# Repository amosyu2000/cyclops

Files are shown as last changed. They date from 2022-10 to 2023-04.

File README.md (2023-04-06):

<div align="center">

<a href="https://github.com/amosyu2000/cyclops">
	Cyclops header
</a>

# Cyclops <!-- omit in toc -->
Cyclops Ride Assist: Real-Time Monitoring System.<br/>  
__Team 9__  
[Aaron Li](https://github.com/aaronhsli) (lia79)  
[Amos Cheung](https://github.com/amoscheung99527) (cheuny2)  
[Amos Yu](https://github.com/amosyu2000) (yua25)  
[Brian Le](https://github.com/briantule) (leb7)  
[Manny Lemos](https://github.com/MannyLemos) (lemosm1)  

</div>

 <!-- Page Break -->

North American cities are shifting from a car-centric design to greener forms of transportation. It is expected that more people will adopt cycling as their primary method of commuting. However, it is difficult for a cyclist to keep track of everything going on around them, especially during busy times.

Cyclops Ride Assist (CRA) will be a user-friendly, all-in-one, and easily mountable system that adds modern automobile safety features on any bicycle that will allow its users to have full detection of their surroundings during their trip from start to finish. This includes rear view detection using LiDAR sensors and an LED display, crash identification through an accelerometer, as well as a front-facing camera to capture and record footage. In the event of an accident, the CRA will automatically record a min of footage, the LiDAR data, as well as an acclerometer log for future review and analysis. 

## Video

Click the thumbnail to be directed to our promotional video!

Watch the video (https://youtu.be/2H2faZxTyGI)

## Schedule 

| Date | Description |
|---|---|
| September 7, 2022 | Project started |
| September 21, 2022 | Problem Statement and Goals started |
| September 24, 2022 | Development Plan started |
| Oct 3, 2022 | Software Requirements Specification started |
| October 19, 2022 | Hazard Analysis started |
| October 25, 2022 | Verification and Validation Plan started |
| November 14, 2022 | Proof of Concept demo |
| January 17, 2023 | Design Document started |
| February 9, 2023 | Revision 0 demo |
| March 1, 2023 | Verification and Validation Report started |
| April 1, 2023 | Revision 1 demo |
| April 5, 2023 | User Guide started |
| April 5, 2023 | Reflection started |
| April 11, 2023 | Capstone EXPO |

## Repository Structure

### Source Code

We put all our code in the [Code tab](https://github.com/amosyu2000/cyclops). The file structure of the code is as follows.

<details><summary>docs</summary>

- Documentation for the project

</details>

<details><summary>refs</summary>

- Reference material used for the project, including papers

</details>

<details><summary>src</summary>

- Source code

</details>

<details><summary>test</summary>

- Test cases

</details>

### Issues

We report and keep track of bugs that need to be fixed and things that need to be done in the [Issues tab](https://github.com/amosyu2000/cyclops/issues). 

### Contributing

We contribute to the codebase by making pull requests, which are tracked in the [Pull requests tab](https://github.com/amosyu2000/cyclops/pulls).

### Meeting Minutes

We schedule weekly meetings to discuss progress, setbacks, and deadlines. Meeting minutes are kept in the [Discussions tab](https://github.com/amosyu2000/cyclops/discussions).

### Wiki

We write down things we've learned so that we can refer to it in the future. Documentation is kept in the [Wiki tab](https://github.com/amosyu2000/cyclops/wiki) and is updated frequently.

## License
See our [license file](./LICENSE).

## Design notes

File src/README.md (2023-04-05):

<div align="center">

# Source Code

</div>

## How to execute `__main__`
1. Add your packages to the pipenv with `pipenv install <package> --skip-lock`
1. Once added, run `pipenv run python .`

## Modules

This folder contains all source code for the project, including software for the Raspberry Pi, schematics for the electrical system, or 3D models for the mechanical housing.

### Physical Modules



### Electrical Modules



### Software Modules









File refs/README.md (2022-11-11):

<div align="center">

# Reference Information

</div>

This folder holds information and resources of interest for the project.  This
is intended to be a convenient location for project members to access
support material for the project.

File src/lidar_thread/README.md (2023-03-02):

<div align="center">

# Lidar Sensor

</div>

## Hardware
[TF-Luna (8m)](http://en.benewake.com/product/detail/5e1c1fd04d839408076b6255.html)

## Usage
In the `src` directory, run `pipenv run python -m lidar_thread.__init__`

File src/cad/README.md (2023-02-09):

<div align="center">

# CAD Files

</div>

.ipt, .stl files for use on Prusa i3 MK3S printers.

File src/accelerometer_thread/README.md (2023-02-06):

<div align="center">

# Accelerometer

</div>

## Hardware
[ADXL345](https://www.analog.com/media/en/technical-documentation/data-sheets/adxl345.pdf)

## Usage
In the `src` directory, run `pipenv run python -m accelerometer_thread.__init__`

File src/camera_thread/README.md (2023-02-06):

<div align="center">

# Camera

</div>

## Hardware
[Webcam](https://www.amazon.ca/Microphone-Otooking-Streaming-Conferencing-Recording/dp/B08HYDZ6TN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)

## Usage
In the `src` directory, run `pipenv run python -m camera_thread.__init__`

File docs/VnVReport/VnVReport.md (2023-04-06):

<div align="center">

<a href="https://github.com/amosyu2000/cyclops">
	Cyclops header
</a>

# Verification and Validation Report <!-- omit in toc -->
Cyclops Ride Assist: Real-time Monitoring System.<br/>  
__Team 9__  
Aaron Li (lia79)  
Amos Cheung (cheuny2)  
Amos Yu (yua25)  
Brian Le (leb7)  
Manny Lemos (lemosm1)  

</div>

 <!-- Page Break -->

## Table Of Contents <!-- omit in toc -->
- [1. Revision History](#1-revision-history)
- [2. Symbols, Abbreviations, and Acronyms](#2-symbols-abbreviations-and-acronyms)
- [3. General Information](#3-general-information)
	- [3.1. Purpose](#31-purpose)
	- [3.2. Scope](#32-scope)
	- [3.3. Background](#33-background)
- [4. Functional Requirements Evaluation](#4-functional-requirements-evaluation)
- [5. Non-Functional Requirements Evaluation](#5-non-functional-requirements-evaluation)
	- [5.1. Look and Feel Requirements](#51-look-and-feel-requirements)
	- [5.2. Usability and Humanity Requirements](#52-usability-and-humanity-requirements)
	- [5.3. Performance Requirements](#53-performance-requirements)
	- [5.4. Operational and Environmental Requirements](#54-operational-and-environmental-requirements)
	- [5.5. Maintainability and Support Requirements](#55-maintainability-and-support-requirements)
	- [5.6. Security Requirements](#56-security-requirements)
	- [5.7. Cultural and Political Requirements](#57-cultural-and-political-requirements)
	- [5.8. Legal Requirements](#58-legal-requirements)
- [6. Testing](#6-testing)
	- [6.1. Rear Vehicle Detection](#61-rear-vehicle-detection)
	- [6.2. Crash Detection](#62-crash-detection)
	- [6.3. Video/Data Logging](#63-videodata-logging)
	- [6.4. Power](#64-power)
	- [6.5. Mounting](#65-mounting)
- [7. Changes Due to Testing](#7-changes-due-to-testing)
- [8. Code Coverage Metrics](#8-code-coverage-metrics)
- [9. Appendix](#9-appendix)
	- [9.1. Reflection](#91-reflection)
	- [9.2. Usability Survery Responses](#92-usability-survery-responses)

## List of Tables <!-- omit in toc -->
- [Table 1.1: Revision History](#rh)
- [Table 1.2: Rear Vehicle Detection Tests](#t1.2)
- [Table 1.3: Crash Detection Tests](#t1.3)
- [Table 1.4: Video/Data Logging Tests](#t1.4)
- [Table 1.5: Power Tests](#t1.5)
- [Table 1.6: Mounting Tests](#t1.6)
- [Table 1.7: Code Coverage Metrics](#t1.7)

## List of Figures <!-- omit in toc -->

## 1. Revision History
<div align="center">

<p id="rh">Table 1.1: Revision History</p>

| Date | Developer(s) | Change |
|:--|:--|:--|
| March 1, 2023 | Aaron Li, Amos Cheung, Amos Yu, Brian Le, Manny Lemos | Document created |
| March 6, 2023 | Brian Le | Updated sections | 
| March 6, 2023 | Amos Cheung | Updated sections | 
| March 7, 2023 | Aaron Li | Updated sections |
| April 3, 2023 | Amos Cheung | Changed name/description of some of the sections. Refer to issue #322 for details | 
| April 5, 2023 | Aaron Li | Link sections. | 

</div>

## 2. Symbols, Abbreviations, and Acronyms
| Name | Description |
|:--|:--|
| CRA | Abbreviation of Cyclops Ride Assist.|
| Cyclist | A person who operates a bicycle as a means of transportation. |
| User | A person who will operate the final product. See Cyclist. |
| Client | See user. |
| SRS | Software Requirements Specification |
| Video feed | A cycle of clips using a fifo queue implementation. Can be concatenated to form the last buffer_time seconds of video.  |
| LiDAR | Light Detection and Ranging. A range sensing method that uses a pulsed laser. |
| LED stick | An array of 8 individually addressable RGB LEDs. |
| α_x | Measures acceleration parallel to the path of the bicycle. |
| α_y | Measures acceleration perpendicular to the path of the bicycle along the plane of the ground. |
| α_z | Measures acceleration in the vertical direction. |
| norm | A measure of the absolute value of the acceleration vector. |
| tilt | A measure of acceleration vector in the xy plane. |
| f_sampling_cd | Sampling frequency of the crash detection. |
| f_sampling_bd | Sampling frequency of the rear vehicle detection. |
| buffer_time | Seconds of video to save after a crash occurs. |

## 3. General Information

### 3.1. Purpose
The purpose of this document is to outline the steps taken for validation, verification, and testing of the functionality of Cyclops Ride Assist (CRA).

### 3.2. Scope
This document details the testing procedures and pass-fail requirements that ensure each sub-system in CRA functions independently and as a complete and fully integrated product. Software and hardware components alike will both be subject to Black box testing.

### 3.3. Background
CRA will be an easily mountable, and quick to set up system that adds modern car safety features onto any bike. These features include rear vehicle detection and alert, a continuous loop of the last 60 seconds of camera, accelerometer, and LiDAR data, and crash identification and response. CRA is aimed at cyclists of all levels that frequently traverse road and gravel terrains. CRA is not designed to be used on extreme terrain such as downhill mountain biking.

## 4. Functional Requirements Evaluation
The testing of the functional requirements is important to ensure that the system, and the many components that it is composed of, functions as designed. The methodology for the functional requirements is to begin with unit testing of the individual components, then move to integration testing.

| Traceability | Relevant Components | Test Plan and Test Factors |
|:--|:--|:--|
| CFR1 | Rear Vehicle Detection | The tests that focus on this requirement demonstrated that the system is able to accurately convert a distance signal input into an LED output. For the testing of this requirement to pass, it was critical that both the LiDAR and the LEDs are functioning properly independently of each other. When testing the LiDAR, it was important to consider the length of the cable that connects the LiDAR to the microcontroller. Having such a long cable can cause inaccuracies in signal transmission. Testing the LiDAR also involved making sure that the sensor could return accurate distance measurements over the full range of operation of the device. The LEDs also needed to be tested to make sure that each individual LED on the LED stick could be toggled on or off, and the color modified as desired. To test the integration of the full rear vehicle detection system, it was important to test that the rate at which the LEDs turn on was proportional to the rate at which an object was being closer in the LiDAR's range of operation. Testing involved both using code to test as well as field testing, to ensure that this functional requirement worked accurately and continuously from the input to the output.|
| CFR2 | Video/Data Logging | The test plan for video recording demonstrated that the system can collect uninterrupted video footage. This sort of testing focuses on the camera equipment itself as well as the code that uses it. Factors to consider included making sure that the camera was mounted securely to the housing, and verifying that the soldering of the camera cable has good contact and no shorting. When testing the software for the video logging, the camera was connected to a laptop and it was demonstrated that it worked as intended. This same test was then transferred to the microcontroller to make sure that it could provide the same performance on the embedded system.|
| CFR3 | Crash Detection | A factor that was kept in mind when testing the accuracy of the acceleration data returned by the accelerometer was that the data returned was not in m/s^2. Thus, it was also necessary to test the function used to scale the data coming in to be in SI units. Knowing also that the accelerometer is three-axis, it was necessary to test all three axes independently to measure any cross-sensitivity that might be present. It was also important to test the frequency at which the crash detection polls data. Testing revealed an optimal f_sample_cd sampling frequency that was a balance between resource usage and data reliability. Testing involved both using code to test as well as field testing. Field testing looked like subjecting the accelerometer to various impacts in different directions, and also running tests to ensure that, when a user is cycling under normal conditions, the jitter of the acceleration data that is being measured is kept below a threshold. |
| CFR5 | Crash Detection | The tests that focus on this requirement were designed to demonstrate that the crash detection component is able to differentiate between a user that is cycling versus a user that is still. Testing revealed that the system is not capable of achieving this, as there were too many factors at play. For example, in order for the acceleration data of an idle bike versus a moving bike to be differentiable, it had to be assumed that the bike was on its kickstand in order to remove the factor of any movement that the user might introduce. Although this test did not pass, it was shown that the functionality of the crash detection in | CFR7 was not  |affected, as the crash detection algorithm did not depend on the ability to discern if a user is moving. This test revealed that the accelerometer is always detecting that the user is moving, and so the crash detection algorithm was designed to work around this problem. 
| CFR6 | Rear Vehicle Detection | When testing the LiDAR sensor, a factor that was considered was the type of material of the surface that the signal would reflect off of. The exterior of vehicles is usually made of a smooth metal with a coating to finish, which was shown to reflect the LiDAR signal reliably. Although vehicles were the primary target for the rear vehicle detection, testing factored in other common surfaces that might be seen by cyclists on the road, such as concrete, wood, and plastic, as well as objects with bizarre shapes, such as other bicycles. It was also important to test the frequency at which the rear vehicle detection polls distance data. Testing revealed an optimal f_sample_bd sampling frequency that was a balance between resource usage and data reliability. Unit testing for the software portion of this functional requirement involved feeding mock data to the rear vehicle detection function, then verifying that the algorithm could recognize that an object was approaching (i.e. the distance was steadily decreasing). 
| CFR7 | Crash Detection | Testing the crash detection algorithm involved verifying the functionality of each of the three stages of the algorithm, then making sure that the algorithm was able to transition from one stage to the next in response to the acceleration data coming in. The three stages are called the Normal, Climax, and Inverse states, and to enter each stage, the acceleration data needed to exhibit certain behavior. If the algorithm got to the Inverse state, it was determined that a crash had occurred. When testing the robustness of the algorithm, atypical crash datasets were provided to see if a crash would be detected. By this approach, the algorithm could be continuously improved and refined until all the datasets would be detected. The same testing process was carried out for false positives. Testing involved using software testing suites as well as field testing, to ensure that the algorithm could match performance in a real-time environment.|
| CFR8 | Crash Detection, Video/Data Logging | The testing done for this requirement focused on the length of the video exported by the system. Other factors to consider included the memory and CPU usage that the buffer process consumed on the microcontroller. A software testing suite was used to verify that the buffer process was safely creating and dumping video fragments, and could stitch those fragments together into a full video of maximum length buffer_time upon request. The suite also tested the length of video outputs that are requested one right after another. On top of using the suite, manual testing revealed the importance of maintaining a steady, expected framerate. This was found to be important because it was necessary to ensure a video that was not sped-up or slowed-down, and would also not sporadically speed up and slow down. |
| CFR9 | Video/Data Logging | It was important to test the functional requirement of CRA to be able to save the video footage to disk in order to define how the microcontroller behaves when the external storage is either not plugged in or out of memory. The idea is to validate that the user experience is not affected when the external storage component is found to be in an invalid state. A factor to consider was the fact that a user could choose to plug in their own external storage instead of using the one provided. Another factor was the fact that a user might be using the external storage for other things as well, and thus the CRA should not interfere with other files on it. Field testing looked like leaving the external storage unplugged or plugging in several different external storages at different storage capacities.|
| CFR11 | Power | The objective behind testing the power component was to make sure that the battery is able to sustain the microcontroller under normal operating conditions, and to define the behavior of CRA in the cases when the power supplied by the battery is insufficient. A part of the testing plan involved measuring the battery life of the system from a full charge, when it is turned on, and when it is turned off. This testing revealed ways that the microcontroller process could be optimized to consume less power, and gave the product a specification of battery life that can be provided to the user. Furthermore, the testing plan needed to decide at what point the user needs to be reminded of low battery, and at what point the battery can no longer sufficiently power CRA. |
| CFR12 | Video/Data Logging | The testing done for this requirement focused on the continuous, uninterrupted execution of the video buffer process while another a previous video was being logged. For the testing of this requirement to pass, it was required that there be a negligible, ideally zero, amount of lag occur when a video logging action is called. This testing was first done manually in the lab, performed over SSH or with the CRA plugged into an external monitor. Then, the testing was transitioned to the field, where the system was subjected to normal operating conditions. In the case of the field, the process could not be monitored in real time, so the test was verified by looking for any time discrepancies in the generated logs. |
| CFR13 | Crash Detection | The testing done for this requirement focused on the continuous, uninterrupted execution of the crash detection process while another crash was being logged. For the testing of this requirement to pass, it was required that there be a negligible, ideally zero, amount of lag occurring when the crash detection algorithm would detect a crash. This testing was first done manually in the lab, performed over SSH or with the CRA plugged into an external monitor. Then, the testing was transitioned to the field, where the system was subjected to normal operating conditions. In the case of the field, the process could not be monitored in real time, so the test was verified by looking for any time discrepancies in the generated logs. |

## 5. Non-Functional Requirements Evaluation
The testing of the non-functional required both qualitative and quantitive tests. [Usability surveys](#92-usability-survery-responses), rankings, and timing tests were all used in conjunction with one another to determine if all the requirements had been satisfied. In order to ensure that the CRA is of the highest standards, the team ensured that all testing was done in a robust and repeatable way. All test specifications and structure can be found in the VnVPlan. 

### 5.1. Look and Feel Requirements
|Requirement Traceability | Test Plan and Test Factors| Results and Evaluation | 
|:--|:--|:--|
|CNFR1, CNFR2, CNFR3, CNFR4, CNFRST1| The main goal of testing the Look and Feel Requirements is to ensure that the CRA is well adapted to a certain style and appearance that was outlined in the SRS document. Due to certain factors such as societal or personal factors, it was key to ensure that the look and feel of the CRA would not become a hindrance to its users. The test plan was to first conduct a visual inspection test and to create several usability surveys - which can be viewed in [Section 9.2](#92-usability-survery-responses) - for all patrons to fill out in order to determine whether or not the product was satisfactory according to the noted requirements.| Usability tests were completed by different users and the overall score was averaged out to be an 8.5. Positive feedback came from the minimalistic design, colour choice, and size. However, there was criticism in terms of the overall rectangular appearance and choice of material. |

### 5.2. Usability and Humanity Requirements
|Requirement Traceability | Test Plan and Test Factors| Results and Evaluation | 
|:--|:--|:--|
|CNFR5 - CNFR14, CNFRST2 - CNFRST6| The main goal of testing the Usability and Humanity Requirements is to ensure that the CRA can be used by a variety of users and stakeholders with ease as was outlined in the SRS document. Since the system may be considered complicated to non-technical or technical users, it was imperative to make sure that the product was as simple as possible. Therefore, two categories were to be tested: hardware and software.| Overall, four different tests were completed to ensure that the Usability and Humanity Requirements were fulfilled. For further details and implications of the test, the VnV Plan can be referenced. For CNFRST2, the average time was measured to be around 16.3s. Positive feedback was given for the design of the locking mechanism while negative feedback was given for the weight. For CNFRST3, the average time it took to open the application after a power cycle was approximately 30.7s. This was not satisfactory to the developers as it was above the threshold set (RESPONSE_TIME_MILLISECONDS) given and so further implementation and testing will be done to ensure a shorter time. For CNFRST4 and CNFRST5, the manual was spoken instead to different users using non-technical language. The overall score was 8.1 out of a possible 10. Feedback included further instructions and explanations of the system. These tests were combined for simpler testing. For CNFRST6, the audiovisual cue was output almost immediately which was <1 second. This is within the response time desired.| 

### 5.3. Performance Requirements
|Requirement Traceability | Test Plan and Test Factors| Results and Evaluation | 
|:--|:--|:--|
|CNFR15 - CNFR33, CNFRST7 - CNFRST21 | The main goal of testing the performance requirements is to ensure that the CRA is performing up to expected standards. The testing plan included all the different modules of the system. This would include the hardware (The chassis, the camera, the microcontroller, the storage, etc.) as well as the software (Algorithms, crash detection, LiDAR, video logging, etc). These tests also ran simultaneously with various CFRST tests.| Please refer to the Functional Requirements Evaluation in [Section 4](#4-functional-requirements-evaluation) or the Testing listed below in [Section 6](#6-testing) for further details on the testing plan for performance. Furthermore, the details of each test can be found in the VnVPlan document. For CNFRST7, the average of the recorded tests was 30.7s. This was the same test as CFNRST3. For CNFRST8, the average of the recorded tests was 16.5s. This is within our allowable range as prescribed through UPLOAD_TIME_SECONDS. For CNFRST9, the average of the recorded tests was <1s. This is within our allowable range. For CNFRST10,  the average of the recorded tests was 84%. This is within our allowable range but can be improved on to ensure better vehicle detection. For CNFRST11, the developers tested on their own personal bicycles with no hindrance. Furthermore, after conversing with users, it was deemed that there was no hindrance to the pedaling, braking, or other normal functions on their bicycle. For CNFRST12, there was no leaking or sounds to be heard. Over the course of twenty trials, there was no indication of any failure or degradation. For CNFRST13, through our software unit testing, it was deemed that all calculations were within the three decimal range provided. For CNFRST14, through our software unit testing, it was deemed the speedometer and accelerometer were running accurately within 2%. For CNFRST15, the average of the recorded tests was within 1s. This is within our allowable range. For CNFRST16, the average of the recorded tests was 10.3s. This is within our allowable range. For CNFRST17, a drop test and crash test was performed twenty different times. After further inspection, it was deemed that there was no damage to the CRA. For CNFRST18, the average of the recorded tests was 5.1s. This is within our allowable range. For CNFRST19, the system was left on for various periods of time while running solely on battery. At the end of the tests, it was found that the battery could last for approximately 30 minutes before depleting. This result was not satisfactory and will require further research. For CNFRST20, a survey was collected with feedback and can be viewed in [Section 9.2](#92-usability-survery-responses). Many responses did not have any concerns with the CRA; however, some wanted further extensibility in terms of ports, cameras, battery. For CNFRST21, the test was intended to be continuous. Upon writing this document, there has been no documentation of any damage or wear to the product. | 

### 5.4. Operational and Environmental Requirements
|Requirement Traceability | Test Plan and Test Factors| Results and Evaluation | 
|:--|:--|:--|
|CNFR34 - CNFR38, CNFRST22 - CNFRST24 | The main goal of testing the operational and environmental requirements is to ensure that the CRA would be able to operate in various conditions and situations. The testing plan included placing the CRA in various locations with different climates, placing the CRA in different positions, as well as interfacing the CRA with different OS and hardware. | For CNFRST22, the CRA was brought outside and all intended functionalities were working as expected. For CNFRST23, the CRA was connected to a variety of systems and computers  and all intended functionalities were working as expected. For CNFRST24, the repository was able to be accessed publicly by the developers as well as other users and stakeholders through a link. | 

### 5.5. Maintainability and Support Requirements
|Requirement Traceability | Test Plan and Test Factors| Results and Evaluation | 
|:--|:--|:--|
|CNFR39 - CNFR42, CNFRST25 | The main goal of testing the maintainability and support requirements is to ensure that the CRA will be widely available and accessible to all. The testing plan included ensuring that the code repository was fully public and able to be accessed by any on various sorts of computers and systems. | For CNFRST25, different errors like unplugging, missing hardware, and recreated bugs were created and the system did not work as intended. Furthermore, the system would alert the user that it was not working as intended. | 

### 5.6. Security Requirements
|Requirement Traceability | Test Plan and Test Factors| Results and Evaluation | 
|:--|:--|:--|
|CNFR43, CNFR44, CNFR45, CNFRST26, CNFRST27|The main goal of testing the security requirements is to ensure that the CRA. The testing plan included two plans that would test the access and the privacy to the loaded storage. It was ensured that the footage created would not be uploaded to any unwanted platforms or the cloud. | For CNFRST26, the SD card was placed into various systems and computers and all files were readable. A conversion was done between the Pi video file and an .mp4. For CNFRST27, no videos were sent to the cloud through the wireless connection provided to the CRA. All files were found to be local. | 

### 5.7. Cultural and Political Requirements
|Requirement Traceability | Test Plan and Test Factors| Results and Evaluation | 
|:--|:--|:--|
|CNFR46, CNFR47, CNFRST28 | The main goal of testing the cultural and political requirements is to ensure that the CRA will not offend stakeholders, users, or others. This testing plan was included to ensure that the product would not infringe on Equity, Diversion, and Inclusion of any users. The tests included a [usability survey](#92-usability-survery-responses) given to users to gain their feedback. | For CNFRST28, the manual was indeed in English.  | 
### 5.8. Legal Requirements
|Requirement Traceability | Test Plan and Test Factors| Results and Evaluation | 
|:--|:--|:--|
|CNFR48, CNFR49, CNFRST29, CNFRST30 |The main goal of testing the legal requirements is to ensure that the CRA is compliant and is not breaking any laws in various countries, mainly Canada. The testing plan included group meetings and further research that would be compiled into a document. | For CNFRST29, various bicycle brands were researched and tested. Furthermore, many users possess bicycles and so testing was also done on a multitude of these vehicles. For CNFRST30, the CRA did not infringe on any of the legal or compliance requirements in Canada. Therefore, it was noted that the product would be allowed. | 

## 6. Testing
Testing was structured based on how the systems and subsystems were defined for the software of Cyclops. With the nature of how each major safety feature is composed of both electrical and software components, either white box or black box testing was utilized. If the unit required a real-world environment to fully work, black box testing was chosen and if the unit involved more algorithmic components, white box testing was chosen.

### 6.1. Rear Vehicle Detection
The main goal of testing the rear vehicle detection would be to test the functionality of our LiDAR sensor as well as the algorithm used to convert the distance-based data into a visual representation (LED)’s. The visual representation of LEDs is configured such that each LED will represent a specific level/proximity to the rider of a vehicle or object. Our plan in unit testing would be to ensure that the LEDs are functioning from each extremity (close and far) ensuring that there is a visible object in the sensor's field of vision at all times. 

<div align="center">

<p id="t1.2">Table 1.2: Rear Vehicle Detection Tests</p>

| Test Number | Description | Requirement Referenced | Inputs | Expected Outputs | Actual Outputs | Result |
|:--|:--|:--|:--|:--|:--|:--|
| BD1 | Object should be held 0 - 1 meters to the rear sensor | CFR1, CFR2, CFR6, CFR10, CFR12, CNFR12, CNFR25 | LiDAR sensor feed | LED stick cells 1 - 7 should all be lit up | LED stick cells1 - 7 were all lit up | Pass |
| BD2 | Object will be 4 meters from the rear sensor | CFR1, CFR2, CFR6, CFR10, CFR12, CNFR12, CNFR25 | LiDAR sensor feed | LED stick cells 1 - 4 should all be lit up | LED stick cells 1 - 6 were all lit up | Pass |
| BD3 | Object will be greater than 8 meters from the rear sensor | CFR1, CFR2, CFR6, CFR10, CFR12, CNFR12, CNFR25 | LiDAR sensor feed | LED stick cells should all be off | LED stick cells were all off | Pass |
| BD4 | Rear Vehicle detection should have < 1 second in latency for updating the LEDS. We will hide an object away from the Ultrasonic sensors field of vision and then suddenly hold it in the view to see its reaction time | CFR1, CFR2, CFR6, CFR10, CFR12, CNFR15 | LiDAR sensor feed | LED stick cells should light up within 1 second once an object is put in the sensors field of vision | LED stick cells light up within 1 second once the object is put in the sensors field of vision | Pass |
</div>

### 6.2. Crash Detection 

The crash detection unit of CRA consists of 2 main components which are the accelerometer inputs and the algorithm to determine a crash. The algorithm is implemented through trial and error to approximate a valid threshold of disturbance towards the unit for the program to have recognized a crash. The test plan is to create a real world environment where the rider and bike will go through common obstacles and routines that are similar to that of the field. Varying obstacles shall be used to create a variety of test cases to test the system boundaries. The accelerometer is the main electrical component in this subsystem so we will also add test suites to ensure that reads are properly made and logged. Simulated tests will be done in a safe and risk free manner in which we are generating enough force for CRA to recognize a crash. 

Each test performed for the crash detection unit will have CRA 2 main units already mounted on the bike handle and rear seat respectively.

<div align="center">

<p id="t1.3">Table 1.3: Crash Detection Tests</p>

| Test Number | Description | Requirement Referenced | Inputs | Expected Outputs | Actual Outputs | Result |
|:--|:--|:--|:--|:--|:--|:--|
| CD1 | Rider will ride in a straight line on a flat road for 10 seconds | CFR3, CFR4, CFR5, CFR7 | Accelerometer electrical input, front camera feed | No crashed detected | No crashed detected | Pass |
| CD2 | Rider will ride in a straight line over grass or a bumpy path for 10 seconds | CFR3, CFR4, CFR5, CFR7 | Accelerometer electrical input, front camera feed | No crashed detected | No crashed detected | Pass |
| CD3 | Rider will ride in a straight line for 5 seconds and then “crash” | CFR3, CFR4, CFR5, CFR7 | Accelerometer electrical input, front camera feed | Crash detection algorithm should prompt a video clip to be logged | Video clip was logged and stored on SD as well as crash information of moments before | Pass |
| CD4 | Rider will hold the bike in their hand and let the bike drop/fall over | CFR3, CFR4, CFR5, CFR7 | Accelerometer electrical input, front camera feed | No crashed detected | No crashed detected | Pass |
| CD5 | Rider will hold the bike and jolt it forward and backwards for 5 seconds | CFR3, CFR4, CFR5, CFR7 | Accelerometer electrical input | α_x readings should update to reflect the sudden change in acceleration | α_x readings updates to reflect the sudden change in acceleration | Pass |
| CD6 | Rider will hold the bike and jolt it side to side (left to right) for 5 seconds | CFR3, CFR4, CFR5, CFR7 | Accelerometer electrical input | α_y readings should update to reflect the sudden change in acceleration | α_y readings updates to reflect the sudden change in acceleration | Pass |
| CD7 | Rider will hold the bike and jolt it up and down for 5 seconds | CFR3, CFR4, CFR5, CFR7 | Accelerometer electrical input | α_z readings should update to reflect the sudden change in acceleration | α_z readings updates to reflect the sudden change in acceleration | Pass |
| CD8 | Create another crash after recovering from the prior crash.| CFR12, CFR13 | Accelerometer electrical input | CRA should resume crash detection and recording video and data | CRA resumes crash detection and recording video and data | Pass |
</div>

### 6.3. Video/Data Logging

The video and data logging unit testing will ensure the functionality of the logging remains active during the time the system is running, saves logged values upon crash, and resumes its logging after the crash. Logged clips and values should remain consistent and have little to no latency. The test suite for this unit will also account for the accuracy and rate in which data has been logged when the unit itself experiences varying changes in movement. 

Each test will be performed by having the CRA unit experience and trigger a crash.

<div align="center">

<p id="t1.4">Table 1.4: Video/Data Logging Tests</p>

| Test Number | Description | Requirement Referenced | Inputs | Expected Outputs | Actual Outputs | Result |
|:--|:--|:--|:--|:--|:--|:--|
| VDL1 | Take note of event that happened in the field of view of vfront 60 seconds prior to crash | CFR2, CFR7, CFR8 | Vfront input | The events of the video clip should be exactly the same as what was viewed 60 seconds prior | The events of the video clip are the exact same as what was viewed 60 seconds prior | Pass |
| VDL2 | Prior to the crash, jolt CRA forward and backwards to log and verify the changes in α_x have been logged | CFR3 | Vfront input, Accelerometer electrical input, front camera feed | The past 60 seconds of events for α_x should be logged and stored within the CSV data log | The past 60 seconds of events for α_x are logged and stored within the CSV data log | Pass |
| VDL3 | Prior to the crash, jolt CRA forward and backwards to log and verify the changes in α_x have been logged | CFR3 | Vfront input, Accelerometer electrical input, front camera feed | The past 60 seconds of events for α_y should be logged and stored within the CSV data log | The past 60 seconds of events for α_y are logged and stored within the CSV data log | Pass | 
| VDL4 | Prior to the crash, jolt CRA forward and backwards to log and verify the changes in α_x have been logged | CFR3 | Vfront input, Accelerometer electrical input, front camera feed | The past 60 seconds of events for α_z should be logged and stored within the CSV data log | The past 60 seconds of events for α_z are logged and stored within the CSV data log | Pass |
| VDL5 | When CRA is powered on, video and data logs should be stored on a new file | CFR7, CFR8 | Power button, Vfront input, Accelerometer electrical input, front camera feed | The next crash is detected and should be logged, verify that the file is a fresh file from the previous crash log | A crash was detected and the file is a fresh file from the previous crash log | Pass |
| VDL6 | When CRA detects a crash, the next crash after should have video and data logs stored on a new file | CFR7, CFR8, CNFR29 | Power button, Vfront input, Accelerometer electrical input, front camera feed | The next crash is detected and should be logged, verify that the file is a fresh file from the previous crash log | A crash was detected and the file is a fresh file from the previous crash log | Pass |
| VDL7 | CRA video and data logs should be responsive and have latency of < 1 second. We will display the constant data outputs being read in by CRA and note if the values are changing within a reasonable time | CNFR15, CNFR17 | Vfront input, Accelerometer electrical input, front camera feed | The values of the acceleration should update and reflect a drop within 1 second of use dropping the unit | The values update within 1.5 second of dropping the unit | Fail |

</div>

### 6.4. Power

CRA has configured the power button such that both the crash detection and rear vehicle detection should automatically start running once it has been pressed. The system also has configured the button to log the last bit of data once the power has been turned off (button is pressed again). 

<div align="center">

<p id="t1.5">Table 1.5: Power Tests</p>

| Test Number | Description | Requirement Referenced | Inputs | Expected Outputs | Actual Outputs | Result |
|:--|:--|:--|:--|:--|:--|:--|
| P1 | CRA should automatically have the scripts of CRA’s crash and rear vehicle detection ran once powered on | CFR11, CNFR6 | Power button | Video and data should begin to be read in and LEDs should light up to indicate power on | Video and data begins to be read in and LEDs light up when powered on | Pass |
| P2 | CRA should automatically clip and log the past 60 seconds of CRA’s crash and rear vehicle detection data once powered off | CFR11, CNFR6 | Power button | Data should be logged and saved within CSV locally when CRA has been powered off | Data is logged and saved within CSV locally when CRA was powered off | Pass | 

</div>

### 6.5. Mounting

The physical system of the CRA consists of two separate housing units that each attach to different parts of the bike. The main housing unit mounts to the handlebars, while the LiDAR housing unit mounts to the seat post. Both units use the same mounting hardware. Testing will ensure that each mounting system can reliably secure the CRA to the bicycle in a variety of situations.

<div align="center">

<p id="t1.6">Table 1.6: Mounting Tests</p>

| Test Number | Description | Requirement Referenced | Inputs | Expected Outputs | Actual Outputs | Result |
|:--|:--|:--|:--|:--|:--|:--|
| M1 | The main housing is resistant to shaking when mounted to the handlebars of the bicycle | CNFR5, CNFR21 | High-frequency, low-amplitude shaking over an extended time period | The housing stays in place | The housing stays in place | Pass |
| M2 | The main housing is resistant to impact when mounted to the handlebars of the bicycle | CNFR5, CNFR21 | A single, high-amplitude impact | The housing stays in place | The housing stays in place | Pass |
| M3 | Securely mount the main housing the handlebars of the bicycle | CNFR13, CNFR21 | Several bike handlebars of different diameters | The housing mounts securely | The housing mounts securely | Pass |
| M4 | The LiDAR housing is resistant to shaking when mounted to the seat post | CNFR5, CNFR21 | High-frequency, low-amplitude shaking over an extended time period | The housing stays in place | The housing stays in place | Pass |
| M5 | The LiDAR housing is resistant to impact when mounted to the seat post | CNFR5, CNFR21 | A single, high-amplitude shock | The housing stays in place | The housing stays in place | Pass | 
| M6 | Securely mount the LiDAR to the seat post | CNFR13, CNFR21 | Several seat posts of different tube diameters | The housing mounts securely | The housing mounts securely | Pass |

</div>

## 7. Changes Due to Testing
The Rev0 demo provided the cyclops team with an opportunity to showcase a functional prototype of the ride monitoring system. However, the presentation's weak points paired with feedback from the Teaching Assistants provided valuable insight that has shaped our final product. 

The most glaring failure of the demo was the poor performance of the ultrasonic sensor. The signal noise from operating in an enclosed space meant that the distance being detected was marginally accurate at best, and catastrophically dangerous to users at worst. Immediately following the demo more reliable alternatives were researched. It was determined that the technology at the forefront of the automotive industry, LiDAR distance sensing, was the only suitable option. In the following weeks, the switchover to LiDAR was implemented in code, wiring schematics, and mounting. The change proved fruitful, the outputs were significantly more accurate and less susceptible to noise.  Moreover, the upper limit of distance sensing was drastically increased from 2 metres to 8 metres providing a much larger window to warn users of incoming vehicles. 

Another problem identified by the Teaching assistants was our hardware housing’s striking resemblance to the humble construction block commonly known as a brick. This issue was multifold; the design was not only sharp and unattractive but also too large. This problem was considered at length following the presentation and led the Cyclops team to take on a complete redesign of the internal circuitry and hardware layout. This effort yielded a hardware housing with an approximate 50 percent reduction in volume and a less boxy design which favoured rounded corners. 

While digging into technical specifications and the real-world usage of the ride-assist system, the Teaching Assistants identified battery life as a potential source of trouble. At that time, the unit could run for approximately 30 minutes on a 10,000 mAh battery. Thanks to this insight the Cyclops team made it a priority to begin researching battery-saving methods which could be applied to the raspberry pi development board used. While still an ongoing effort, this issue has begun to be addressed. With all things considered, the largest contributor to poor battery life is the overhead associated with running unneeded functions of the operating system. Namely; the ethernet and power LEDs were disabled, wifi and Bluetooth were disabled, and HDMI output was disabled. Moreover, the LEDs used were exchanged for a more power-efficient led strip. Reaching beyond the raspberry pi, the problem was also addressed at its root - the battery. The size of the battery has been increased. The summation of these changes aims to see battery life improved to a minimum of 2 hours.

## 8. Code Coverage Metrics
Code coverage is determined by whether a specific sub system and code was exercised or not during the execution of our test suite. For the code coverage, although there exists a lot of unit testing extensions that measure out these metrics for us, it is more accurate and effective for us to calculate these metrics ourselves due to the nature that the majority of our testing is done in a real world environment and limited use of PyTest. Coverage was collected my monitoring each segment of the system while running through all of the mentioned unit tests. We monitor and have set breakpoints for functions, statements, and conditions ensuring they run through during utilization of that specific sub system. It is also noted that we will not be running unit testing for each of the respective constructor (init.py) files for each of the subsystems. Metrics that we are including in our coverage report includes:
- Function coverage: How many functions defined have been called
- Statement coverage: How many of the statements in the in the program have been executed
- Condition coverage: How many of the boolean sub-expressions have been testing for a true and a false value
- Line coverage: How many lines of source code have been tested

<div align="center">

<p id="t1.7">Table 1.7: Code Coverage Metrics</p>

| File | Statements | | Condition | | Functions | | Lines | | 
|:--|:--|:--|:--|:--|:--|:--|:--|:--|
| acceleration_plot.py | 100% | 38/38 | 100% | 1/1 | 100% | 4/4 | 100% | 79/79 |
| acceleration.py | 100% | 35/35 | N/A | N/A | 100% | 9/9 | 100% | 91/91 |
| video_capture.py | 93% | 65/70 | 80% | 8/10 | 100% | 4/4 | 100% | 159/159 |
| led.py | 100% | 14/14 | 100% | 2/2 | 100% | 3/3 | 100% | 36/36 |
| ultrasonic.py | 100% | 30/30 | 100% | 3/3 | 100% | 5/5 | 100% | 82/82 |

</div>

## 9. Appendix

### 9.1. Reflection
The VnV Plan put about a solid foundation upon which the Cyclops team worked to verify and validate the numerous intricate components of the ride assist system. The testing identified in the VnV Plan was a response to the fundamental features required by the implementation chosen. Those features are rear vehicle detection, crash detection, video and data logging, and some baseline usability and stylistic requirements. 

As a result of tackling broader requirements in testing specifications as opposed to generating specific tests for specific implementations, the VnV Plan proved to be a robust document that withstood the changes made due to testing. Some of those changes include switching from ultrasonic to LiDAR distance sensing and decreasing the size of the system. In the first instance clearly predicting what was required was driven by the overarching concept of the system; improving user safety by indicating the distance of objects behind the rider. This brings about an important concept that the Cyclops team learned and will be sure to use in future Verification and Validation Planning; Test cases should be broad enough that implementation shifts will not render them obsolete, yet specific enough that every requirement is sure to be met under their cumulative rule. 

Another vital component of specifying testing requirements is the idea of a feasible workload. This concept was considered carefully in the construction of the VnV plan and remains a cornerstone of our testing specifications. Striking a balance between a robust set of tests that fulfill all of our system's requirements while remaining feasible for the members to perform is a tricky task that must be navigated with care. Over the course of the VnV plan and subsequent testing specifications, the Cyclops team formed smaller subgroups to form testing teams. These testing teams worked together to share the load of testing, hold each other accountable to schedules, and vouch for one another when workloads were too high. To maximize efficiency the Cyclops team learned that tests should be designed to maximize their coverage and overlap as minimally as possible with other tests. 

Selecting the right tests to prove the required characteristics is yet another vital component of testing design. The Cyclops team came to understand that having the ability to take a step back from the specific test being designed and consider how the project will operate as a whole was the key to this undertaking. To succeed the team must be on the same page when it comes to overarching goals that must be fulfilled and how the product will be used. For example, when designing testing for the hardware housing it is extremely important not to treat the housing as simply a piece of plastic operating in a vacuum. Testing designers must consider the hardware housing operating in the context of the project riding atop the handlebars of a typical bicycle, outside in the elements, moving at speed, and experiencing bumps and jolts. These considerations are what make or break a testing case and demonstrate project vision.

### 9.2. Usability Survery Responses
| Timestamp | CNFRST1: Is the CRA designed in a way that is appealing? | CNFRST1: Is the CRA designed in a way that is non-intrusive? | CNFRST1: What would you add to the CRA if you were the designer? | CNFRST3: Is the CRA software designed in a way that is appealing?|CNFRST3: Was the Power ON system button easy to use? | CNFRST11: Does the CRA hinder your ability to ride your bicycle? If so, in what way? | CNFRST21: Is there any way that you would like to expand the CRA? | CNFRST21: Do you have any concerns with the CRA on your own personal bicycle? | CNFRST29: What is your brand and model of bicycle and if you know, what are the size and weight restrictions? | CNFRST46, 47: Is the CRA and all of the documents inclusive, neutral and not offensive to any stakeholders, users, or others. |
|:--|:--|:--|:--|:--|:--|:--|:--|:--|:--|:--|
| 3-3-2023 14:15:18 | Yes | Yes | nothing | Yes | Yes | no | No | No | don't know my bike model | Yes |
| 3-3-2023 14:17:13 | Yes | Yes | Nothing, its perfect | Yes | Yes | No it does not. | No | Yes | CCM 26inch tires. | Yes |
| 3-4-2023 10:35:49 | Yes | Yes | Other color options | Yes | Yes | No it doesn't. | Yes | No | Triumph Lazer | Yes |
| 3-5-2023 12:22:53| Yes | Yes | Increase camera resolution | Yes | Yes | No | No | No | Super cycle Walmart edition. Max height 6ft3. Max weight 300lbs. | Yes |
| 3-5-2023 16:31:17 | Yes | No | I would add a panel of LED lights to add to the aesthetic of the machine. | Yes | Yes | It blocks my POV. | Yes | No | NA | Yes |
| 3-5-2023 16:59:53 | Yes | Yes | A price tag | Yes | Yes | I can't put the light on the bicycle, and I ride the bike at night | No | No | Giant 10' wheel. Cannot be over 200lbs | Yes |
| 3-6-2023 17:22:36 | Yes | Yes | | Yes | Yes | | No | No | | Yes |
| 3-7-2023 14:53:19 | Yes | Yes | a headlight | Yes | Yes | no | No | No | | Yes |

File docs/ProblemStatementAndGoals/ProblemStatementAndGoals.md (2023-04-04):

<div align="center">

<a href="https://github.com/amosyu2000/cyclops">
	Cyclops header
</a>

# Problem Statement And Goals <!-- omit in toc -->
Cyclops Ride Assist: Real-Time Monitoring System<br/>  
__Team 9__  
Aaron Li (lia79)  
Amos Cheung (cheuny2)  
Amos Yu (yua25)  
Brian Le (leb7)  
Manny Lemos (lemosm1)  

</div>

 <!-- Page Break -->

## Table of Contents <!-- omit in toc -->
- [1. Revision History](#1-revision-history)
- [2. Problem Statement](#2-problem-statement)
  - [2.1. Problem](#21-problem)
  - [2.2. Stakeholders](#22-stakeholders)
  - [2.3. Inputs](#23-inputs)
  - [2.4. Outputs](#24-outputs)
- [3. Goals](#3-goals)
  - [3.1. Reliable Rear Vehicle Detection](#31-reliable-rear-vehicle-detection)
  - [3.2. Convenient Mounting and Dismounting](#32-convenient-mounting-and-dismounting)
  - [3.3. Accurate Crash Identification](#33-accurate-crash-identification)
  - [3.4. Fast Video Buffering and Saving](#34-fast-video-buffering-and-saving)
  - [3.5. Accessible Video and Data Export](#35-accessible-video-and-data-export)
- [4. Stretch Goals](#4-stretch-goals)
  - [4.1. Emergency Response Integration](#41-emergency-response-integration)
  - [4.2. Mobile App](#42-mobile-app)
  - [4.3. Map Integration](#43-map-integration)
- [5. Appendix](#5-appendix)
  - [5.1. Symbolic Parameters](#51-symbolic-parameters)

## List of Tables <!-- omit in toc -->
- [Table 1.1: Revision History](#rh)
- [Table 5.1.1: List of Symbolic Parameters](#sp)

## List of Figures <!-- omit in toc -->

## 1. Revision History
<div align="center">

<p id="rh">Table 1.1: Revision History</p>

| Date | Developer(s) | Change |
|:--|:--|:--|
| 2022-10-19 | All | Document creation |
| 2022-10-20 | Amos Yu | Improved formatting |
| 2022-11-09 | Aaron Li | Updated content |
| 2023-04-03 | Amos Yu | Updated Problem Statement and Goals for Rev1 |

</div>

## 2. Problem Statement

### 2.1. Problem

As North America pursues greener goals, it is expected a higher percentage of people will adopt cycling as their primary method of transportation as for its relatively low carbon footprint compared to automobiles. However, many roads were not designed and developed with cyclists in mind. Even with dedicated bicycle lanes, cyclists may find themselves in fear as cars, trucks, and buses dart past with a far greater speed and momentum. In the worst cases, accidents may occur leading to both physical injuries and emotional trauma for the cyclist, the automobile driver, their respective families, and the community. Therefore, it is vital that this system will provide greater safety by increasing the awareness of cyclists on the road, allowing drivers and cyclists to share the road responsibly.

Cyclops Ride Assist (CRA) is going to be an all-in-one, easily installable, and easy-to-use system that adds modern car safety features onto a bike, such as rear vehicle detection and crash detection. Furthermore, the CRA will feature automatic video, LiDAR, and accelerometer data upload to a flash drive.

This solution to this problem will deliver on the following goals listed in [Section 3](#3-goals).

### 2.2. Stakeholders 

| Stakeholder | Representatives |
|:--|:--|
| Project Proposers | Aaron Li, Amos Cheung, Amos Yu, Brian Le, Manny Lemos |
| Project Supervisor | Spencer Smith |
| Teaching Assistants | Nicholas Annable, Christopher Schankula, Timofey Tomashevskiy, Samuel Crawford, Ting-Yu Wu |
| End Users | Cyclists |

### 2.3. Inputs

- The user will be able to mount and dismount the system to and from their bicycle. 
- The user will be able to turn the system on and off.
- The user will be able to connect the system to an external power source, such as a power bank.
- The user will be able to save footage at any time during their ride.

### 2.4. Outputs
- The system will stay on the bicycle until manual intervention by the user. 
- The system will be powered on and fully activated with all functionalities. 
- The system will increase the safety and awareness of the cyclist during their ride.
- The system will deliver on the following goals listed in [Section 3](#3-goals). 

## 3. Goals

### 3.1. Reliable Rear Vehicle Detection

The system will be mounted to the bicycle in such a way that it can monitor the blindspots of the cyclist. As soon as the system turns on, it will detect if there are vehicles within MAX_DISTANCE metres of the cyclist's rear. The system will visually notify the cyclist that there is a vehicle in their blindspot without requiring them to turn around and take their eyes off of the road.

### 3.2. Convenient Mounting and Dismounting

The cyclist will be able to mount the system to the bicycle and unmount the system from the bicycle with minimal effort. The system should remain mounted on the bicycle under normal working conditions and in the event of a crash. The should system should only unmount if unmounted by the user or in extreme circumstances of mechanical failure.

### 3.3. Accurate Crash Identification

As soon as the system turns on, it will collect data on the orientation and state of the bicycle. Using the data collected, the system will interpret if the cyclist has been involved in one of many types of accidents (crashing into something, getting hit by something, falling off) with a high degree of accuracy. The crash identification algorithm will consider acceleration due to gravity and a CRASH_THRESHOLD acceleration.

### 3.4. Fast Video Buffering and Saving

As soon as the system turns on, it will collect video footage at a rate of FRAMERATE frames per second. The system will buffer the past BUFFER_TIME seconds of footage and will delete all older footage. In the event of an accident, or if the user hits the capture button, the system will save the buffer footage within MAX_UPLOAD_TIME seconds to an external storage option.

### 3.5. Accessible Video and Data Export

Exported footage and data will be accessible to the user at any point during or after the ride. Taking inspiration from airplane electronic flight recorders, the footage and data exported by the system should clearly communicate to the user the context of the bicycle and its surroundings during each crash or capture. 

## 4. Stretch Goals

### 4.1. Emergency Response Integration

A user will be able to provide the contact information of an emergency contact to the system. The system will alert the saved emergency contact in the event of any serious crashes. 

### 4.2. Mobile App

The user will be able to interface with the system via the mobile app. The user will be able to use the app to set certain parameters and permissions for the system. The system will be able to wirelessly export footage and data to the user's smartphone via the mobile app.

### 4.3. Map Integration

The system will record the distance and places/roads travelled from start to finish of a trip. The system will leverage GPS and real-time traffic data to alert the user of any road closures, accidents, or heavy traffic. 

## 5. Appendix

### 5.1. Symbolic Parameters

<div align="center">

<p id="sp">Table 5.1.1: List of Symbolic Parameters</p>

| Name | Parameter Description | Type | Units |
|:--|:--|:--|:--|
| GRAVITY | Acceleration due to gravity. | float | m/s<sup>2</sup> |
| CRASH_THRESHOLD | The maximum acceleration incurred during a crash. | integer | m/s<sup>2</sup> |
| MAX_DISTANCE | The maximum distance that the rear vehicle detection will monitor. | float | m |
| BUFFER_TIME | The length of footage before the crash that will be saved. | integer | seconds |
| MAX_UPLOAD_TIME | The maximum time required to upload a video to the external storage device. | integer | seconds |
| RESPONSE_RATE | The polling rate at which the output is updated to match the current input. | integer | Hz |
| FRAMERATE | The framerate of the front-facing video | integer | fps |

</div>

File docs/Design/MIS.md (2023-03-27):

<div align="center">

<a href="https://github.com/amosyu2000/cyclops">
	Cyclops header
</a>

# Module Interface Specification <!-- omit in toc -->
Cyclops Ride Assist: Real-time bicycle crash detection and blindspot monitoring.<br/>  
__Team 9__  
Aaron Li (lia79)  
Amos Cheung (cheuny2)  
Amos Yu (yua25)  
Brian Le (leb7)  
Manny Lemos (lemosm1)  

</div>

 <!-- Page Break -->

## Table Of Contents <!-- omit in toc -->
- [1. Revision History](#1-revision-history)
- [2. Introduction](#2-introduction)
- [3. Purpose](#3-purpose)
- [4. Scope](#4-scope)
	- [4.1. System Context](#41-system-context)
- [5. Project Overview](#5-project-overview)
	- [5.1. Functional Decomposition](#51-functional-decomposition)
	- [5.2. Module Hierarchy](#52-module-hierarchy)
- [6. System Variables](#6-system-variables)
	- [6.1. Monitored and Controlled Variables](#61-monitored-and-controlled-variables)
	- [6.2. Constants](#62-constants)
- [7. User Interfaces](#7-user-interfaces)
	- [7.1. Inputs](#71-inputs)
	- [7.2. Outputs](#72-outputs)
- [8. Mechanical Hardware](#8-mechanical-hardware)
	- [8.1. Raspberry Pi Mechanical Specifications](#81-raspberry-pi-mechanical-specifications)
	- [8.2. Polylactic Acid (PLA) Material](#82-polylactic-acid-pla-material)
	- [8.3. Mechanical Design](#83-mechanical-design)
- [9. Electrical Components](#9-electrical-components)
	- [9.1. CRA Electrical Specifications](#91-cra-electrical-specifications)
	- [9.2. Raspberry Pi Electrical Specifications](#92-raspberry-pi-electrical-specifications)
	- [9.3. Accelerometer Specifications](#93-accelerometer-specifications)
	- [9.4. Lidar Sensor Specifications](#94-lidar-sensor-specifications)
	- [9.5. Camera Specifications](#95-camera-specifications)
- [10. Communication Protocols](#10-communication-protocols)
	- [10.1. USB Protocol](#101-usb-protocol)
	- [10.2. Wi-Fi Protocol](#102-wi-fi-protocol)
	- [10.3. I2C Protocol](#103-i2c-protocol)
	- [10.4. Serial Protocol](#104-serial-protocol)
- [11. Software Modules](#11-software-modules)
	- [11.1. video\_capture.py](#111-video_capturepy)
	- [11.2. acceleration.py](#112-accelerationpy)
	- [11.3. \__init_\_.py - LED\_Handler](#113-_init_py---led_handler)
	- [11.4. lidar.py](#114-lidarpy)
	- [11.3. \__init_\_.py - Dir\_Handler](#113-_init_py---dir_handler)
- [12. Timeline](#12-timeline)
- [13. Appendix](#13-appendix)
	- [13.1. Reflection](#131-reflection)
		- [13.1.1. Solution Limitations](#1311-solution-limitations)
	- [13.2. References](#132-references)

## List of Tables <!-- omit in toc -->
- [Table 1.1: Revision History](#rh)

## List of Figures <!-- omit in toc -->
- [Figure 4.1.1: CRA System Context Diagram](#4.1.1)
- [Figure 5.1.1: CRA Functional Decomposition Diagram](#5.1.1)
- [Figure 5.2.1: CRA Module Hierarchy Diagram](#5.2.1)
- [Figure 8.1.1: Raspberry Pi 4 Model B Physical Schematic](#8.1.1)
- [Figure 8.3.1: Figure 8.3.1: Raspberry-Pi Housing and Mount Assembly](#8.3.1)
- [Figure 8.3.2: Raspberry-Pi Housing Top Component](#8.3.2)
- [Figure 8.3.3: Raspberry-Pi Housing Middle Component](#8.3.3)
- [Figure 8.3.4: Raspberry-Pi Housing Bottom Component](#8.3.4)
- [Figure 8.3.5: Raspberry-Pi Housing Mount Top Component](#8.3.5)
- [Figure 8.3.6: Raspberry-Pi Housing Mount Bottom Component](#8.3.6)
- [Figure 8.3.7: Lidar Housing and Mount Assembly](#8.3.7)
- [Figure 8.3.8: Lidar Housing Component](#8.3.8)
- [Figure 8.3.9: Lidar Housing Mount Top Component](#8.3.9)
- [Figure 8.3.10: Lidar Housing Mount Bottom Component](#8.3.10)
- [Figure 9.1.1: CRA Circuit Diagram](#9.1.1)
- [Figure 9.1.2: CRA Breadboard Schematic](#9.1.2)
- [Figure 9.2.1: Raspberry Pi 4 Model B Circuit Diagram](#9.2.1)
- [Figure 9.2.2: Raspberry Pi 4 Model B Pinouts](#9.2.2)
- [Figure 9.4.1: Accelerometer Sensor Diagram](#9.4.1)
- [Figure 9.5.1: Lidar Sensor Diagram](#9.5.1)
- [Figure 11.0.1: CRA Software Stack](#11.0.1)

## 1. Revision History
<div align="center">

<p id="rh">Table 1.1: Revision History</p>

| Date | Developer(s) | Change |
|:--|:--|:--|
| **2023**-01-17 | Aaron Li, Amos Cheung, Amos Yu, Brian Le, Manny Lemos | Document created |
| 2023-02-02 | Amos Cheung | Updated Timeline and Module Hierchary based on peer review |
| 2023-03-22 | Manny Lemos | Revision 1 Edit |

</div>

## 2. Introduction
This document is the Modular Interface Specification of Cyclops Ride Assist (CRA) system. The purpose of this document is to outline the design specification for each component in CRA and serve as the basis for implementation work when building the system. 

## 3. Purpose
Cyclops Ride Assist (CRA) aims to provide cyclists with a simple-to-use ride monitoring system that decreases the risk of a crash, and provides valuable data in the event of a crash.

## 4. Scope
CRA will be an easily mountable, and quick to set up system that adds modern car safety features onto any bike. These features include rear vehicle detection and alert, a continuous loop of the last 60 seconds of camera, accelerometer, and Lidar data, and crash identification and response. CRA is aimed at cyclists of all levels that frequently traverse road and gravel terrains. CRA is not designed to be used on extreme terrain such as downhill mountain biking.

### 4.1. System Context

<div align="center">
<p id="4.1.1">Figure 4.1.1: CRA System Context Diagram</p>



</div>

## 5. Project Overview

### 5.1. Functional Decomposition
<div align="center">
<p id="5.1.1">Figure 5.1.1: CRA Functional Decomposition Diagram</p>

  

</div>

### 5.2. Module Hierarchy
<div align="center">
<p id="5.2.1">Figure 5.2.1: CRA Module Hierarchy Diagram</p>

  

</div>

## 6. System Variables

### 6.1. Monitored and Controlled Variables

The following are a list of variables that are to be monitored.

| Monitored Var | Monitored Type | Range | Units | Comments |
|:--|:--|:--|:--|:--|
| poweroff_button_pushed | Boolean | N/A | N/A | GPIO event to respond to the press of the poweroff button. |
| capture_button_pushed | Boolean | N/A | N/A | GPIO event to respond to the press of the capture button. |
| capture | N/A | N/A | N/A | Video capture object which is queried for video frames, and monitored for errors. |
| accelerometer | N/A | N/A | N/A | Accelerometer sensor object which is queried for acceleration readings, and monitored for errors. |
| x | Size | [-160, 160] |  m/s<sup>2</sup> | The first acceleration vector provided by the accelerometer sensor. |
| y | Size | c |  m/s<sup>2</sup> | The second acceleration vector provided by the accelerometer sensor. |
| z | Size | c |  m/s<sup>2</sup> | The final acceleration vector provided by the accelerometer sensor. |
| norm | Size | c |  m/s<sup>2</sup> | Vector sum of the 3 dimensions of acceleration. |
| Lidar_serial | N/A | N/A | N/A | Lidar sensor object which is queried for distance readings, and monitored for errors. |
| distance | Size | [20, 800] | cm | Used to store the current distance retrieved from the Lidar sensor.

The following are a list of variables that are to be controlled.

| Controlled Var | Controlled Type | Range | Units | Comments |
|:--|:--|:--|:--|:--|
| poweroff_event | Boolean | N/A | N/A | Event which can be set to safely terminate all threads and power down the pi. |
| crash_event |  Boolean | N/A | N/A | Event which is set based on accelerometer data parsed by a crash detection algorithm. Results in a 10-second wait followed by data logging. |
| c_capture_event | Boolean | N/A | N/A | Camera capture event which is set when data logging is intended to occur. Notifies camera thread to concatenate and log its clips. |
| a_capture_event | Boolean | N/A | N/A | Accelerometer capture event which is set when data logging is intended to occur. Notifies accelerometer thread to export its buffer of data. |
| l_capture_event | Boolean | N/A | N/A | Lidar capture event which is set when data logging is intended to occur. Notifies Lidar thread to export its buffer of data. |
| fps | Size | [1, 60] | Frames Per Second | Number of captures per second |
| frame_width | Size | [640, 1920] | Pixels | Number of pixel in capture width |
| frame_height | Size | [480, 1080] | Pixels | Number of pixel in capture height |
| video_length | Time | [0 - 60] | Seconds | The length in seconds of the requested video |
| accelerometer_sample_rate | Size | [10, 3200] | Samples Per Second | Number of accelerometer sensor readings per second |
| accelerometer_data | Entries | N/A | N/A | A FIFO queue which retains the last 60 seconds of accelerometer data. |
| Lidar_sample_rate | Size | [1, 250] | Samples Per Second | Number of Lidar distance sensor readings per second |
| baud_rate | Size | [9600, 921600] | Bits Per Second | Rate of data transfer in serial communication channel. |
| Lidar_data | Entries | N/A | N/A | A FIFO queue which retains the last 60 seconds of Lidar data. |

### 6.2. Constants

| Constant Var | Constant Type | Value | Units | Comments |
|:--|:--|:--|:--|:--|
| g | Acceleration | 9.81 | m/s<sup>2</sup> | Acceleration due to gravity |

## 7. User Interfaces

### 7.1. Inputs

| Input Name | Input Type | Range | Units | Comments |
|:--|:--|:--|:--|:--|
| Power On Button | Physical | [0, 1] | N/A | Button that is used to power on the system and automatically run the CRA software. |
| Power Off Button | Physical | [0, 1] | N/A | Button that is used to power off the system. |
| Capture Button | Physical | [0, 1] | N/A | Button that is used to manually capture an event |
| Mount | Physical | N/A | N/A | Mount used to secure Cyclops to the bike. |
| Battery Port | Physical | N/A | N/A | Port for charging the battery bank. |
| SD Storage Device Port | Physical | N/A | N/A | Port for inserting the SD Card. |
| USB-A Storage Device Port | Physical | N/A | N/A | Port for inserting the USB-A stick. |

### 7.2. Outputs

| Output Name | Output Type | Range | Units | Comments |
|:--|:--|:--|:--|:--|
| LED Strip | Visual | [0, 8] | N/A | 8 addressable RGB LEDs are used to communicate with the user. Their primary purpose is to display the distance of an object behind the user as a function of colour and number of LEDs turned on. Moreover, the LEDs also notify users of CRA powering on, detecting a crash, performing a data capture, and powering off. |
| USB-A stick | Physical | N/A | N/A | The USB-A stick is used to store capture folders containing the last 60 seconds of video capture, acceleration data, and rear object distance data. |

## 8. Mechanical Hardware

### 8.1. Raspberry Pi Mechanical Specifications   

<div align="center">
<p id="8.1.1">Figure 8.1.1: Raspberry Pi Mechanical Drawing and Schematic [1]</p>

  

</div>
The Raspberry Pi 4 Model B is the microcontroller that will be used for all software and processing. The mechanical specifications of the Raspberry Pi is as follows:

| Raspberry Pi Mechanical Specifications | Value | 
|:--|:--|
| Dimensions |  85mm x 56mm | 
| CPU | Quad core Cortex-A72 (ARM V8) | 
| Ports | USB3, USB2, USB-C, HDMI, MicroSD | 
| RAM | 4GB | 
| Operating Temperature | 0-50C | 
| Audio | 4-Pole Stereo Audio | 
| Video | Composite Video | 

The requirements traceability of the Raspberry Pi is as follows:

| Module | [Functional Requirements](../SRS/SRS.md#64-functional-requirements) | [Non-Functional Requirements](../SRS/SRS.md#7-non-functional-requirements) |
|:--|:--|:--|
| Raspberry Pi | CFR11 | CNFR6, CNFR11, CNFR20, CNFR28, CNFR29, CNFR31, CNFR33, CNFR36, CNFR37 |

### 8.2. Polylactic Acid (PLA) Material

The mechanical chassis and frame will be created using Polylactic Acid (PLA) filament, molded through a Prusa i3 MK3s 3D printer. 

The color of the PLA material was chosen to be white in order to reflect the NFRs outlined in the SRS document, specifically CNFR1. 

The mechanical specifications of PLA are as follows [2]:

| PLA Specifications | Value | 
|:--|:--|
| Heat Deflection Temperature | 52C | 
| Density | 1.24 g/cm3 | 
| Tensile Strength | 50MPa | 

### 8.3. Mechanical Design

The mechanical chassis and frame is shown below in Figure 8.3. Each module outlined in the above sections will be fitted with a frame or mount to allow for ease-of-use and protection. 

The mechanical design was created using PLA and the Prusa i3 MK3s 3D printer. 
<div align="center">
<p id="8.3.1">Figure 8.3.1: Raspberry-Pi Housing and Mount Assembly</p>

  

</div>

<div align="center">
<p id="8.3.2">Figure 8.3.2:  Raspberry-Pi Housing Top Component </p>

  

</div>

| Raspberry-Pi Housing Top Component Specification | Value | 
|:--|:--|
| Outer Dimensions | 6.9 mm x 80 mm x 125 mm | 
| Weight | 8 grams | 
| Material | PLA |  

<div align="center">
<p id="8.3.3">Figure 8.3.3: Raspberry-Pi Housing Middle Component</p>

  

</div>

| Raspberry-Pi Housing Middle Component Specification | Value | 
|:--|:--|
| Outer Dimensions | 41 mm x 80 mm x 125 mm | 
| Weight | 9 grams | 
| Material | PLA |  

<div align="center">
<p id="8.3.4">Figure 8.3.4: Raspberry-Pi Housing Bottom Component</p>

  

</div>

| Raspberry-Pi Housing Bottom Component Specification | Value | 
|:--|:--|
| Outer Dimensions | 6.9 mm x 80 mm x 125 mm | 
| Weight | 8 grams | 
| Material | PLA |  

<div align="center">
<p id="8.3.5">Figure 8.3.5: Raspberry-Pi Housing Mount Top Component</p>

  

</div>

| Raspberry-Pi Housing Mount Top Component Specification | Value | 
|:--|:--|
| Outer Dimensions | 30 mm x 69.5 mm x 20 mm | 
| Weight | 8 grams | 
| Material | PLA |  

<div align="center">
<p id="8.3.6">Figure 8.3.6: Raspberry-Pi Housing Mount Bottom Component</p>

  

</div>

| Raspberry-Pi Housing Mount Bottom Component Specification | Value | 
|:--|:--|
| Outer Dimensions | 30 mm x 69.5 mm x 20 mm | 
| Weight | 8 grams | 
| Material | PLA |  

<div align="center">
<p id="mhdb">Figure 8.3.7: Lidar Housing and Mount Assembly</p>

  

</div>

<div align="center">
<p id="mhdb">Figure 8.3.8: Lidar Housing Component</p>

  

</div>

| Lidar Housing Component Specification | Value | 
|:--|:--|
| Outer Dimensions | 40 mm x 51 mm x 16 mm | 
| Weight | MASS grams | 
| Material | PLA | 

<div align="center">
<p id="8.3.9">Figure 8.3.9: Lidar Housing Mount Top Component</p>

  

</div>

| Lidar Housing Mount Top Component Specification | Value | 
|:--|:--|
| Outer Dimensions | 30 mm x 69.5 mm x 20 mm | 
| Weight | 8 grams | 
| Material | PLA |  

<div align="center">
<p id="8.3.10">Figure 8.3.10: Lidar Housing Mount Bottom Component</p>

  

</div>

| Lidar Housing Mount Bottom Component Specification | Value | 
|:--|:--|
| Outer Dimensions | 30 mm x 69.5 mm x 20 mm | 
| Weight | 8 grams | 
| Material | PLA |  

The requirements traceability of the mechanical frames are as follows:

| Module | [Functional Requirements](../SRS/SRS.md#64-functional-requirements) | [Non-Functional Requirements](../SRS/SRS.md#7-non-functional-requirements) |
|:--|:--|:--|
| Mechanical Frame | n/a | CNFR1, CNFR2, CNFR3, CNFR4, CNFR5, CNFR9, CNFR11, CNFR14, CNFR21, CNFR22, CNFR23, CNFR28, CNFR29, CNFR32, CNFR33, CNFR35, CNFR40, CNFR48, CNFR49 |

## 9. Electrical Components

### 9.1. CRA Electrical Specifications

<div align="center">
<p id="9.1.1">Figure 9.1.1: CRA Circuit Diagram</p>



<p id="9.1.2">Figure 9.1.2: CRA Breadboard Schematic</p>



</div>

### 9.2. Raspberry Pi Electrical Specifications

The Raspberry Pi 4's reduced electrical schematic can be seen below. Using various pins and ports provided, CRA will be able to accomplish what is set out in the scope. 
<div align="center">
<p id="9.2.1">Figure 9.2.1: Raspberry Pi 4 Model B Circuit Diagram [3]</p>

  

<p id="9.2.2">Figure 9.2.2: Raspberry Pi 4 Model B Pinouts</p>

 

</div>

| Raspberry Pi Electrical Specifications | Value | 
|:--|:--|
| Microchip | 64-bit SoC @ 1.5GHz | 
| Pins | 40 Pin GPIO Header | 
| Voltage | 5V DC via USB-C/GPIO Header | 
| Amperage | 3A | 

### 9.3. Accelerometer Specifications

The accelerometer will be used to determine when a crash has occured. The accelerometer used is the ADXL-345 and the specifications are as follows, as outlined by Analog Devices [4]. 

| Accelerometer Specifications | Value | 
|:--|:--|
| Voltage Range | 2.0V to 3.6V | 
| Interfaces | SPI and I2C | 
| Temperature Range | -40C to 85C | 
| Axis | 3-Axis (X,Y,Z) | 
| Resolution | 10-bit | 

The requirements traceability of the accelerometer is as follows:

| Module | [Functional Requirements](../SRS/SRS.md#64-functional-requirements) | [Non-Functional Requirements](../SRS/SRS.md#7-non-functional-requirements) |
|:--|:--|:--|
| Accelerometer | CFR3, CFR5 | CNFR15, CNFR17, CNFR24, CNFR25, CNFR29, CNFR33, CNFR35 |

<div align="center">
<p id="9.4.1">Figure 9.4.1: Accelerometer Sensor Diagram [4]</p>

  

</div>

### 9.4. Lidar Sensor Specifications

The Lidar sensor will be used to determine the distance of objects approaching CRA from the rear. CRA makes use of the TF-Luna Lidar sensor and is specified in its documentation [5] by the following.

| Radar Sensor Specifications | Value | 
|:--|:--|
| Dimensions | 45mm x 20mm x 15mm | 
| Operating Range | 0.2-0.8m | 
| Accuracy | ±2% | 
| Range Resolution | 1cm | 
| FOV | 2° | 
| Frame Rate | 1-250Hz | 
| Supply Voltage | 5V| 
| Average Power | 350mW | 

The requirements traceability of the Lidar sensor is as follows:

| Module | [Functional Requirements](../SRS/SRS.md#64-functional-requirements) | [Non-Functional Requirements](../SRS/SRS.md#7-non-functional-requirements) |
|:--|:--|:--|
| Lidar sensor | CFR1, CFR2 | CNFR2, CNFR4, CNFR15, CNFR18, CNFR29, CNFR33 |

<div align="center">
<p id="9.5.1">Figure 9.5.1: Lidar Sensor Diagram [5]</p>

  

</div>

### 9.5. Camera Specifications

The camera will be used to continuously record sequential clips such that the last 60 seconds of footage is always available to be permanently saved. The camera that is being used is the Ootoking 1080p webcam, that can be referenced on Amazon.ca [6].
| Camera Specification | Value | 
|:--|:--|
| Dimension | 3cm x 4cm x 2cm| 
| Weight | 55g | 
| Resolution | 1080p |

The requirements traceability of the camera is as follows:

| Module | [Functional Requirements](../SRS/SRS.md#64-functional-requirements) | [Non-Functional Requirements](../SRS/SRS.md#7-non-functional-requirements) |
|:--|:--|:--|
| Camera | CFR2, CFR6, CFR12 | CNFR2, CNFR7, CNFR15, CNFR27, CNFR33, CNFR35 |

## 10. Communication Protocols

The requirements traceability of all communication protocols is as follows:

| Modules | [Functional Requirements](../SRS/SRS.md#64-functional-requirements) | [Non-Functional Requirements](../SRS/SRS.md#7-non-functional-requirements) |
|:--|:--|:--|
| USB, Wi-Fi, I2C | CFR9, CFR10 | CNFR16, CNFR19, CNFR36, CNFR40, CNFR42. CNFR43, CNFR44, CNFR45 |

### 10.1. USB Protocol
In order to communicate and transmit data, the USB protocol will be used. The following ports will be mainly used for the following: 

| USB | Purpose | 
|:--|:--|
| USB 3.0 | The USB 3.0 ports will be used to connect a camera and a removable USB-A stick. During development other devices like keyboards, mice, external storage devices, and other computers will be connected to these ports to allow for greater ease-of-use and accessibility. | 
| USB-C | The USB-C port will be used to power CRA via battery packs. | 

### 10.2. Wi-Fi Protocol
The Wi-Fi protocol is the 802.11ac protocol. This protocol allows for connections from frequencies of 2.4GHz or 5.0Ghz. This protocol will be used for the following. 

| Wifi Protocol | Purpose | 
|:--|:--|
| 802.11ac | This wireless protocol will allow the users to connect to the CRA remotely using SSH, VNC, and SFTP. Furthermore, this protocol allows users to connect their CRA to either a 2.4 or 5.0GHz wireless network. | 

### 10.3. I2C Protocol
The I2C protocol will be used for communication with the accelerometer. 

| I2C Protocol | Purpose | 
|:--|:--|
| I2C | Enables peripheral chips like the accelerometer to communicate with the controller chip in a synchronous packet switched configuration. | 

### 10.4. Serial Protocol
Bitwise continuous communication protocol which is used in two sensor applications of the CRA system.

| Serial Protocol | Purpose | 
|:--|:--|
| UART | Asynchronous communication interface used for short distance transmissions. The UART protocol will be used for communication with the Lidar distance sensor.  | 
| SPI | Synchronous communication interface used for short distance transmissions. The SPI protocol will be used for communication with the 8 LED pixel strip.  | 

## 11. Software Modules

The main entry point of the program is the `__main__.py` script. All software modules are classes implemented in Python 3.9. Software modules are constructed and executed by threaded `Start` classes. Each module is instantiated by `__main__.py` and communicates with other threads via thread events. Upon startup of the Raspberry Pi, `__main__.py` should immediately begin execution. To shut down the Raspberry Pi, `__main__.py` should pass control to the OS to do a safe poweroff and terminate.

<div align="center">
<p id="11.0.1">Figure 11.0.1: CRA Software Stack</p>



</div>

### 11.1. video_capture.py

__Module Implementation__

Composed of a class Threaded_Video_Writing. Provides the functionality of grabbing frames from a camera, writing said frames to a temporary non-volatile storage location, and logging the last 60 seconds of footage to a permanent storage location. 

__Module Secrets__

- Video capture instance.
- Frames of video clips.
- Video codec.
- Temporary non-volatile storage location
- Video Resolution
- Output file type.

__Module Relationships__

Receives the following Threaded_Video_Writing class construction parameters through `__init__()`.

| Parameter | Type | Description |
|:--|:--|:--|
| fps | integer | Number of frames requested from camera every second. |

__Likely Changes__

- Reduce the number of input parameters to the instantiation of the Threaded_Video_Writing class. These inputs will be replaced by fixed parameters which are deemed most suitable. 
  - This change was implemented
- Implement hardware accelerated video encoding.
  - This will likely enable higher resolution video capture
  - This change has not yet been implemented

__Unlikely Changes__

- Change the camera being used from a USB web-camera to the Raspberry Pi Camera Module.
  - Subsequently, a large portion of the code for the Threaded_Video_Writing class will have to be rewritten.
  - This change has not yet been implemented

__Traceability__

The requirements traceability of the video_capture.py class is as follows:

| Module | [Functional Requirements](../SRS/SRS.md#64-functional-requirements) | [Non-Functional Requirements](../SRS/SRS.md#7-non-functional-requirements) |
|:--|:--|:--|
| video_capture.py | CFR2, CFR8, CFR9, CFR12 | CNFR6, CNFR12, CNFR15, CNFR16, CNFR19, CNFR26, CNFR27, CNFR30, CNFR37, CNFR38, CNFR39, CNFR43, CNFR44 |

### 11.2. acceleration.py

__Module Implementation__

A class named Acceleration. Provides functions for retrieving acceleration readings from the accelerometer, storing the past 60 seconds of readings to a queue, analyzing readings to determine is a crash has occurred, and logging the queue of readings to a non-volatile memory location in the form of a .csv file.

__Module Secrets__

- Amount of time to store acceleration readings for.
- Acceleration Readings.
- Acceleration scaling factors (calibrated).
- Algorithm for computing if a crash has occurred.
- Algorithm to translate queue of readings into .csv file.

__Module Relationships__

Receives the following Acceleration class construction parameters through `__init__()`.

| Parameter | Type | Description |
|:--|:--|:--|
sample_rate | integer | Number of times per second to retrieve an accelerometer reading. This will determine the size of the required queue. |
i2c | busio.I2C Class | Enables setup to accelerometer object by passing i2c as the communication protocol. |

Receives incoming acceleration data through `read_data()`.

| Parameter | Type | Description |
|:--|:--|:--|
| x | float | x component of acceleration |
| y | float | y component of acceleration |
| z | float | z component of acceleration |

The scaled available acceleration data is analyzed, and a determination is returned through `is_crashed()`.

| Returns | Description |
|:--|:--|
| boolean | If a crash has been detected |

Receives the current permanent storage location through `Dir_Handler()`.

| Parameter | Type | Description |
|:--|:--|
| dir_handler | string | Absolute directory of the current permanent capture storage location. |

__Likely Changes__

- Adding the ability to log acceleration data in CSV format, so that data can be collected in the field and brought back to the lab for analysis.
  - This change has been implemented
- Crash detection algorithm will likely be updated and refined as manual testing continues.
  - This change has been implemented.

__Unlikely Changes__

- Functions related to the visualization of acceleration data are useful in testing, but may be removed to improve the performance of the embedded system.
  - This change has been implemented.

__Traceability__

The requirements traceability of the acceleration.py class is as follows:

| Module | [Functional Requirements](../SRS/SRS.md#64-functional-requirements) | [Non-Functional Requirements](../SRS/SRS.md#7-non-functional-requirements) |
|:--|:--|:--|
| acceleration.py | CFR3, CFR5, CFR7, CFR13 | CNFR6, CNFR12, CNFR15, CNFR17, CNFR24, CNFR29, CNFR37, CNFR38, CNFR39 |

### 11.3. \__init__.py - LED_Handler

__Module Implementation__
A class named LED_Handler. Provides a startup, capture, dynamic capture error, dynamic rear object distance, and poweroff LED lighting animations for use with the 8 LED neopixel strip.

__Module Secrets__

- Rasberry Pi pin setups.
- Number of LEDs
- Distance Display Color Gradient
- Animation Implementations

__Module Relationships__

 `error_capture_sequence()` method receives `debug` when called.

| Parameter | Type | Description |
|:--|:--|:--|
| debug | list | 3 boolean values mapping to Accelerometer, Camera, and LiDar capture events respectively. Successful capture is indicated by False, and Failed capture by True. |

`distance_display()` method receives `distance` when called.

| Parameter | Type | Description |
|:--|:--|:--|
| distance | integer | Distance in cm or objects in the rear. |

__Likely Changes__

- Enhance Power on animation to show an initialization debug. 
  - This change has not yet been implemented.

__Unlikely Changes__

- No unlikely changes

__Traceability__

The requirements traceability of the Led_Handler() class is as follows:

| Module | [Functional Requirements](../SRS/SRS.md#64-functional-requirements) | [Non-Functional Requirements](../SRS/SRS.md#7-non-functional-requirements) |
|:--|:--|:--|
| Led_Handler() | CFR1 | CNFR6, CNFR8, CNFR12, CNFR13, CNFR18, CNFR37, CNFR38, CNFR39 |

### 11.4. lidar.py

__Module Implementation__
A class named Lidar. Provides the functionality of reading data from the rear facing lidar sensor, translating this data into a distance reading, storing the past 60 seconds of readings to a queue, and logging the queue of readings to a non-volatile memory location in the form of a .csv file.

__Module Secrets__

- Rasberry Pi serial setup.
- Algorithm to translate raw lidar sensor data into a distance reading.

__Module Relationships__

Receives the following led class construction parameters through `__init__()`.

| Parameter | Type | Description |
|:--|:--|:--|
sample_rate | integer | Number of distance sensor readings per second. |
baud_rate | integer | Speed of communication over serial channel in bits per second. |

Data is interpreted from the lidar distance sensor, and a distance is returned through `read_data()`.

| Returns | Description |
|:--|:--|
| integer | distance in cm measured by the lidar distance sensor. |

Receives the current permanent storage location through `Dir_Handler()`.

| Parameter | Type | Description |
|:--|:--|
| dir_handler | string | Absolute directory of the current permanent capture storage location. |

__Likely Changes__

- Some methodology to decrease noise.
  - Perhaps some distance average or data linearization.

__Unlikely Changes__

- No unlikely changes

__Traceability__

The requirements traceability of the lidar.py class is as follows:

| Module | [Functional Requirements](../SRS/SRS.md#64-functional-requirements) | [Non-Functional Requirements](../SRS/SRS.md#7-non-functional-requirements) |
|:--|:--|:--|
| lidar.py | CFR1 | CNFR6, CNFR12, CNFR15, CNFR18, CNFR37, CNFR38, CNFR39 |

### 11.3. \__init__.py - Dir_Handler

__Module Implementation__
A class named Dir_Handler. Provides the functionality of mounting a USB stick if any are available, as well as determining or creating the most up-to-date directory to permanently store a capture file at.

__Module Secrets__

- Algorithm to mount a USB stick
- Algorithm to determine the most recent capture folder and the conditions under which a new folder must be created.
- Parent directory of folders which will be created.

__Module Relationships__

 `locate_export_dir()` method receives `filename` when called.

| Parameter | Type | Description |
|:--|:--|:--|
| filename | string | Name of the file to be saved excluding timestamps. |

__Likely Changes__

- Add intelligent USB stick mounting if a USB stick is detected. 
  - This change has been implemented.

__Unlikely Changes__

- No unlikely changes

__Traceability__

The requirements traceability of the Dir_Handler() class is as follows:

| Module | [Functional Requirements](../SRS/SRS.md#64-functional-requirements) | [Non-Functional Requirements](../SRS/SRS.md#7-non-functional-requirements) |
|:--|:--|:--|
| Dir_Handler() | ADD | ADD |

## 12. Timeline
| Date | Task | Person | Testing |
|---|---|---|---|
| 2023-01-22 | Creation of crash detection algorithm. | Manny Lemos, Amos Yu  | Automated testing to determine response under a wide range of accelerometer inputs. |
| 2023-01-25 | Update design and 3D print hardware case to accommodate the camera, battery pack, and mounting bracket. | Aaron Li, Amos Cheung | Manual testing. Ensure everything fits as expected. |
| 2023-01-28 | Design and 3D print a mounting bracket to attach the hardware case to bicycle fork. | Aaron Li, Manny Lemos | Manual testing. Ensure the mounting bracket can support the weight of the loaded hardware case sufficiently. Ensure the mounting bracket will function for common bicycle forks. |
| 2023-01-31 | Swap breadboard and jumper wires for PCB and soldered connections. | Amos Cheung | Manual testing. Verify connections using multimeter. |
| 2023-02-05 | Integration of all software modules. | Brian Le, Amos Yu | Manual Testing. Mount the hardware to the bicycle and ensure it functions as detailed in the SRS Document. | 
| 2023-02-09 | Rev0 Demonstration | Brian Le, Amos Yu, Amos Cheung, Aaron Li, Manny Lemos | Ensure all tasks in the timeline up to 2023-02-09 is completed and working as a whole. |
| 2023-02-20 | Implement Lidar Sensor | Amos Cheung, Amos Yu, Brian Le | Manual testing. Ensure lidar sensor functions as detailed in the SRS document. | 

## 13. Appendix

### 13.1. Reflection
Cyclops ride assist aims to fill the ride monitoring and crash avoidance gap in the cycling market. This solution takes the form of a camera, accelerometer, and distance sensor. These inputs are parsed by an embedded computer to provide users with warning lights when vehicles are approaching, and an automatically logged clip if a crash is detected.
#### 13.1.1. Solution Limitations
**Camera Resolution:** The maximum camera resolution possible with the current implementation is 640p. This is due to the data transfer speeds being limited by the USB connection made between the camera and the Raspberry Pi. Using the Raspberry Camera Module is an alternative to the current implementation which would overcome the USB bandwidth issue and could increase the resolution to 1080p. This alternative comes with the downside of addition cost and recording software rewriting because the Pi Camera Module uses custom libraries.

**Camera Position:** With the current implementation the camera is seated atop the bicycle forks facing forward. This provides video capture of the volume of space in front of the cyclist. The limitation of this implementation is evident, there is no camera footage of the volume of space behind the rider. An alternative to the current state would be to add an additional camera with a view behind the cyclist. However, due to the current USB bandwidth issues with a single camera and the lack of support for dual Raspberry Pi Camera Modules this change is not feasible. A possible alternative would be changing the position of the current camera to face being the cyclist.

**Battery Life:** For cyclists who go on multi hour long bicycle rides, battery life may be of concern. The Raspberry Pi used to perform computations is not particularly battery efficient compared to more project specific embedded computers who do not have as much computational overhead. The capacity of the current battery pack being used is 10,000mah. To improve battery life, a higher capacity battery pack could be purchased. However, a higher capacity battery pack is almost certain to come along with the unwanted side effects of a larger size and heavier weight. 

**Ultrasonic Sensor:** Prior to the Lidar sensor, an Ultrasonic distance sensor was used to measure the distance of rear objects. This Ultrasonic sensor was viable up to 2 metres. However, the effectiveness of this was extremely limited when detecting an object at the upper end of this range, or in an enclosed environment where ultrasonic signals bouncing off surfaces created noise. Temperature was also a major limiting factor as the accuracy was subject to change in temperatures of 5 - 19 degrees. One way we can look to improve on the performance and accuracy of our object detection would be to use a higher quality sensor for cyclops which would decrease these problems.

### 13.2. References

[1] "Raspberry Pi 4 Mechanical Drawing", 2018. [Online]. Available: https://datasheets.raspberrypi.com/rpi4/raspberry-pi-4-mechanical-drawing.pdf

[2] "What is PLA?", 2023. [Online]. Available: https://www.twi-global.com/technical-knowledge/faqs/what-is-pla

[3] "Raspberry Pi 4 Electrical Schematic", 2018. [Online]. Available: https://datasheets.raspberrypi.com/rpi4/raspberry-pi-4-reduced-schematics.pdf

[4] "ADXL-345 Datasheet", 2023. [Online]. Available: https://www.analog.com/media/en/technical-documentation/data-sheets/adxl345.pdf

[5] "TF-Luna Product Manual", 2023. [Online]. Available: http://en.benewake.com/res/wuliu/docs/15978504093169389SJ-PM-TF-Luna%20A05%20Product%20Manual.pdf

[6] "1080p Webcam", 2023. [Online]. Available: https://www.amazon.ca/Microphone-Otooking-Streaming-Conferencing-Recording/dp/B08HYDZ6TN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

[7] K. Gross, “Ultrasonic sensors: Advantages and limitations,” MaxBotix Inc., 28-Oct-2020. [Online]. Available: https://www.maxbotix.com/articles/advantages-limitations-ultrasonic-sensors.htm/. [Accessed: 18-Jan-2023].

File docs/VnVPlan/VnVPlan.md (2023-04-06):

<div align="center">

<a href="https://github.com/amosyu2000/cyclops">
    Cyclops header
</a>

# System Verification and Validation Plan <!-- omit in toc -->
Cyclops Ride Assist: Real-time monitoring system.<br/>  
__Team 9__  
Aaron Li (lia79)  
Amos Cheung (cheuny2)  
Amos Yu (yua25)  
Brian Le (leb7)  
Manny Lemos (lemosm1)  

</div>

 <!-- Page Break -->

## Table Of Contents <!-- omit in toc -->
- [1. Revision History](#1-revision-history)
- [2. Symbols, Abbreviations, and Acronyms](#2-symbols-abbreviations-and-acronyms)
- [3. General Information](#3-general-information)
	- [3.1. Purpose](#31-purpose)
	- [3.2. Scope](#32-scope)
	- [3.3. Background](#33-background)
	- [3.4. Relevant Documentation](#34-relevant-documentation)
- [4. Plan](#4-plan)
	- [4.1. Verification and Validation Team](#41-verification-and-validation-team)
	- [4.2. SRS Verification Plan](#42-srs-verification-plan)
	- [4.3. Design Verification Plan](#43-design-verification-plan)
	- [4.4. Verification and Validation Plan Verification Plan](#44-verification-and-validation-plan-verification-plan)
	- [4.5. Implementation Verification Plan](#45-implementation-verification-plan)
	- [4.6. Automated Testing and Verification Tools](#46-automated-testing-and-verification-tools)
	- [4.7. Software Validation Plan](#47-software-validation-plan)
- [5. System Test Description](#5-system-test-description)
	- [5.1. Tests for Functional Requirements](#51-tests-for-functional-requirements)
		- [5.1.1. Rear Vehicle Detection Test](#511-rear-vehicle-detection-test)
		- [5.1.2. Crash Detection Test](#512-crash-detection-test)
		- [5.1.3. Video/Data Logging Test](#513-videodata-logging-test)
		- [5.1.4. Power On System Test](#514-power-on-system-test)
		- [5.1.5. Power Off System Test](#515-power-off-system-test)
		- [5.1.6. Mounting Test](#516-mounting-test)
	- [5.2. Tests for Nonfunctional Requirements](#52-tests-for-nonfunctional-requirements)
		- [5.2.1. Appearance and Style Test](#521-appearance-and-style-test)
		- [5.2.2. Hardware Ease of Use Test](#522-hardware-ease-of-use-test)
		- [5.2.3. Software Ease of Use Test](#523-software-ease-of-use-test)
		- [5.2.4. Learning Test](#524-learning-test)
		- [5.2.5. Understandability Test](#525-understandability-test)
		- [5.2.6. Accessibility Test](#526-accessibility-test)
		- [5.2.7. Power Response Speed Test](#527-power-response-speed-test)
		- [5.2.8. Video Upload Speed and Latency Test](#528-video-upload-speed-and-latency-test)
		- [5.2.9. Crash Detection Speed and Latency Test](#529-crash-detection-speed-and-latency-test)
		- [5.2.10. Car Detection Speed and Latency Test](#5210-car-detection-speed-and-latency-test)
		- [5.2.11. External Safety-Critical Test](#5211-external-safety-critical-test)
		- [5.2.12. CRA Emission Safety-Critical Test](#5212-cra-emission-safety-critical-test)
		- [5.2.13. CRA Decimal Precision Test](#5213-cra-decimal-precision-test)
		- [5.2.14. CRA Accelerometer Accuracy Test](#5214-cra-accelerometer-accuracy-test)
		- [5.2.15. CRA Camera Time Accuracy Test](#5215-cra-camera-time-accuracy-test)
		- [5.2.16. Reliability and Availability Test](#5216-reliability-and-availability-test)
		- [5.2.17. Robustness and Fault-Tolerance Test](#5217-robustness-and-fault-tolerance-test)
		- [5.2.18. Max Storage Capacity Test](#5218-max-storage-capacity-test)
		- [5.2.19. Low Battery Capacity Test](#5219-low-battery-capacity-test)
		- [5.2.20. Scalability and Extensibility Test](#5220-scalability-and-extensibility-test)
		- [5.2.21. Longevity Test](#5221-longevity-test)
		- [5.2.22. Physical Environment Test](#5222-physical-environment-test)
		- [5.2.23. Interfacing with Adjacent Systems Test](#5223-interfacing-with-adjacent-systems-test)
		- [5.2.24. Productization and Release Test](#5224-productization-and-release-test)
		- [5.2.25. Interfacing with Adjacent Systems Test](#5225-interfacing-with-adjacent-systems-test)
		- [5.2.26. Access Security Test](#5226-access-security-test)
		- [5.2.27. Privacy Test](#5227-privacy-test)
		- [5.2.28. Cultural Test](#5228-cultural-test)
		- [5.2.29. Compliance Test](#5229-compliance-test)
		- [5.2.30. Standards Test](#5230-standards-test)
- [6. Appendix](#6-appendix)
	- [6.1. Symbolic Parameters](#61-symbolic-parameters)
	- [6.2. Usability Survey Questions for Non Functional Tests](#62-usability-survey-questions-for-non-functional-tests)
- [7. Reflection](#7-reflection)
## List of Tables <!-- omit in toc -->
- [Table 1.1: Revision History](#rh)

## List of Figures <!-- omit in toc -->

## 1. Revision History
<div align="center">

<p id="rh">Table 1.1: Revision History</p>

| Date | Developer(s) | Change |
|:--|:--|:--|
| October 25, 2022 | Aaron Li, Amos Cheung, Amos Yu, Brian Le, Manny Lemos | Document created |
| November 7, 2022 | Amos Yu | Addressed peer review suggestions |
| April 5, 2022 | Aaron Li | Re-edited for Rev1 |

</div>

## 2. Symbols, Abbreviations, and Acronyms
| Name | Description |
|:--|:--|
| CRA | Abbreviation of Cyclops Ride Assist.|
| Cyclist | A person who operates a bicycle as a means of transportation. |
| User | A person who will operate the final product. See Cyclist. |
| Client | See user. |
| SRS | Software Requirements Specification |
| Video feed | A cycle of clips using a fifo queue implementation. Can be concatenated to form the last buffer_time seconds of video.  |
| LiDAR | Light Detection and Ranging. A range sensing method that uses a pulsed laser. |
| LED stick | An array of 8 individually addressable RGB LEDs. |
| α_x | Measures acceleration parallel to the path of the bicycle. |
| α_y | Measures acceleration perpendicular to the path of the bicycle along the plane of the ground. |
| α_z | Measures acceleration in the vertical direction. |
| norm | A measure of the absolute value of the acceleration vector. |
| tilt | A measure of acceleration vector in the xy plane. |
| f_sampling_cd | Sampling frequency of the crash detection. |
| f_sampling_bd | Sampling frequency of the rear vehicle detection. |
| buffer_time | Seconds of video to save after a crash occurs. |

## 3. General Information
### 3.1. Purpose
The purpose of this document is to describe the testing, validation, and verification processes which will be carried out on the CRA system. Testing instills confidence that software and hardware function as expected independently, and interface correctly. 
### 3.2. Scope
This validation and verification document lays the foundation for testing the CRA system. The requirements for correct system functionality presented in the SRS document will be extended upon to include specific, quantifiable metrics. Success in the testing described will verify that CRA has met these requirements in a measurable, meaningful way.

### 3.3. Background
CRA will be an easily mountable, and quick to set up system that adds modern car safety features onto any bike. These features include rear vehicle detection and alert, a continuous loop of the last 60 seconds of camera, accelerometer, and LiDAR data, and crash identification and response. CRA is aimed at cyclists of all levels that frequently traverse road and gravel terrains. CRA is not designed to be used on extreme terrain such as downhill mountain biking.

Specifically, this document will address testing pertaining to both the software and hardware of CRA. Out of scope testing would include testing for requirements not covered in the SRS document. 
### 3.4. Relevant Documentation
[SRS Document](https://github.com/amosyu2000/cyclops/blob/main/docs/SRS/SRS.md)
## 4. Plan
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

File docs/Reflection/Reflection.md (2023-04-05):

<div align="center">

<a href="https://github.com/amosyu2000/cyclops">
	Cyclops header
</a>

# Reflection <!-- omit in toc -->
Cyclops Ride Assist: Real-Time Monitoring System<br/>  
__Team 9__  
Aaron Li (lia79)  
Amos Cheung (cheuny2)  
Amos Yu (yua25)  
Brian Le (leb7)  
Manny Lemos (lemosm1)  

</div>

 <!-- Page Break -->
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

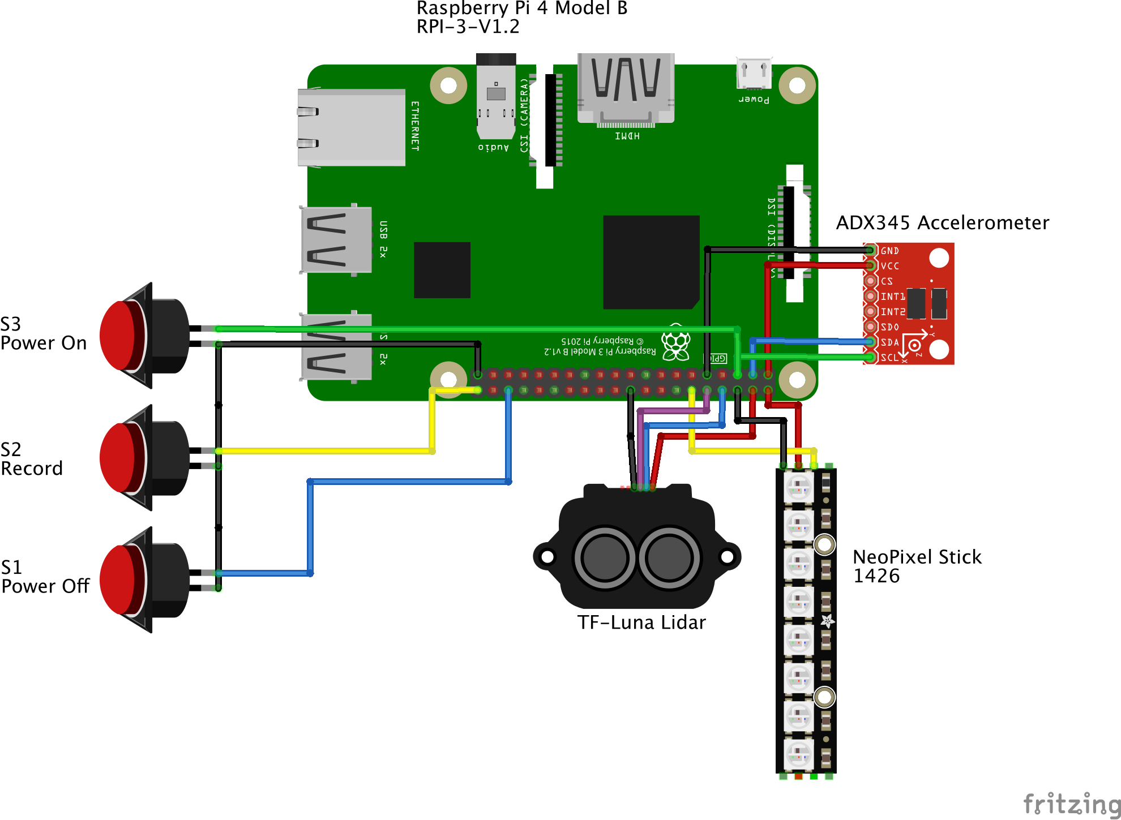
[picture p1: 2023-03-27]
src/circuit_schematics/V2/CRA_bb.png

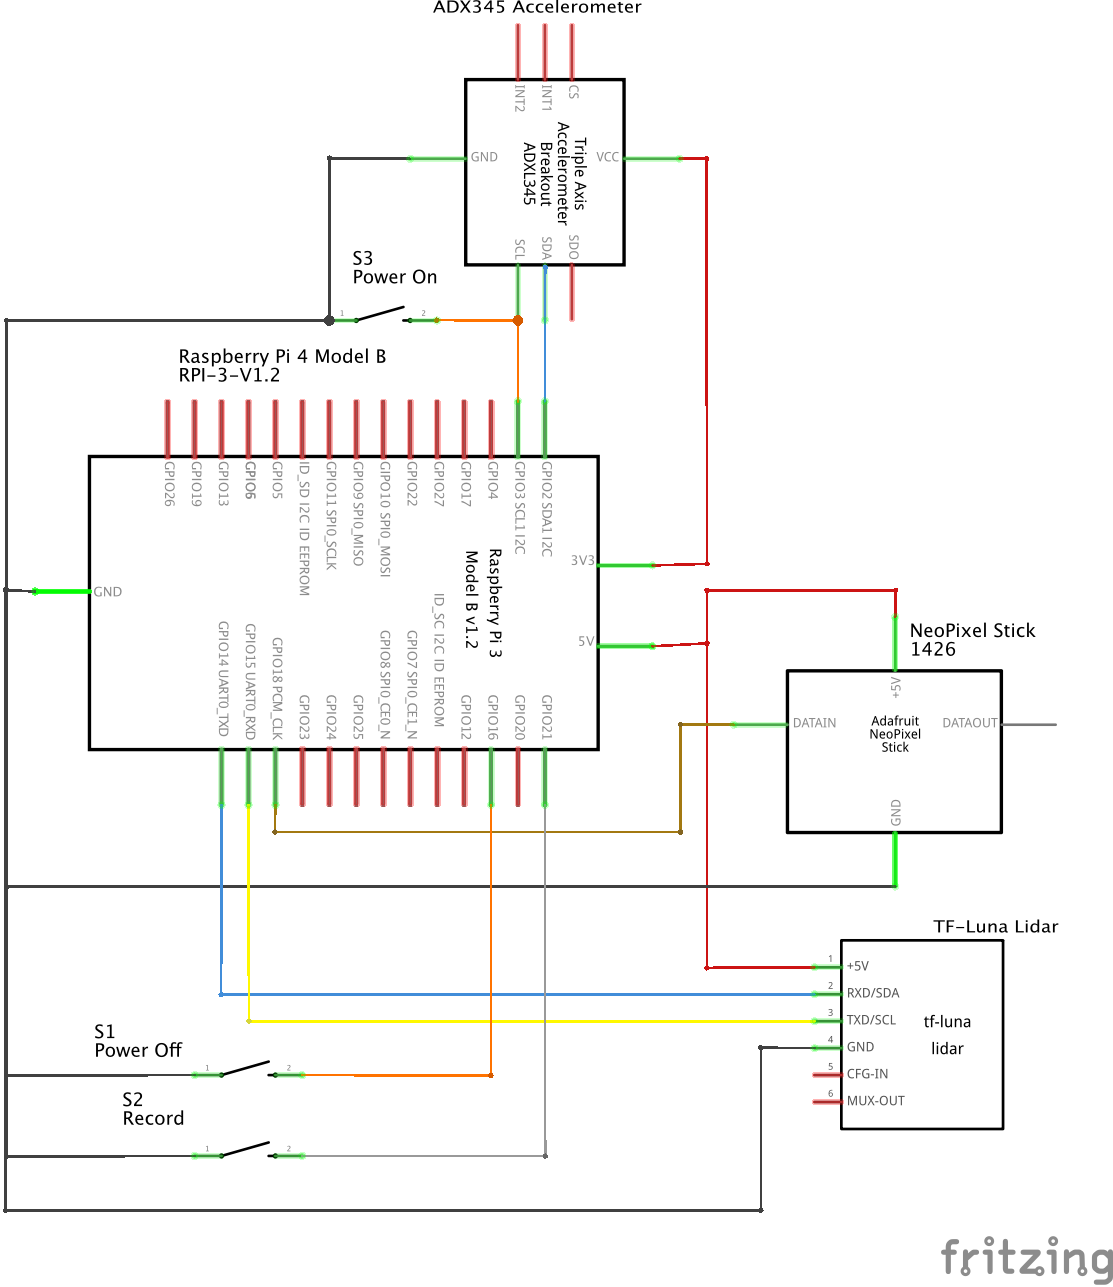
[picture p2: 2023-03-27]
src/circuit_schematics/V2/CRA_schem.png

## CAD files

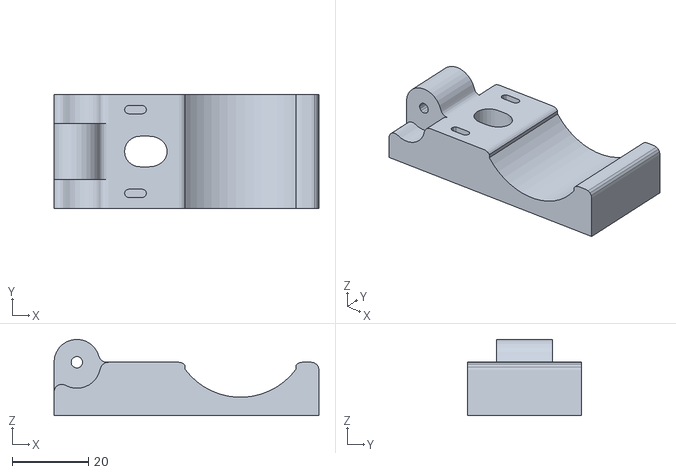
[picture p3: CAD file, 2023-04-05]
src/cad/bike_mount/BIKE_MOUNT_BOTTOM.stl
69.5 x 30.0 x 20.0

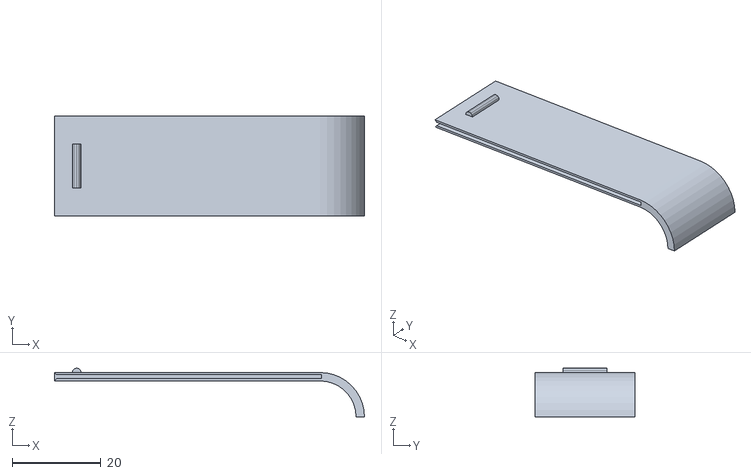
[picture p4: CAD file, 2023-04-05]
src/cad/front_housing/DOOR.stl
69.8 x 22.6 x 11.0

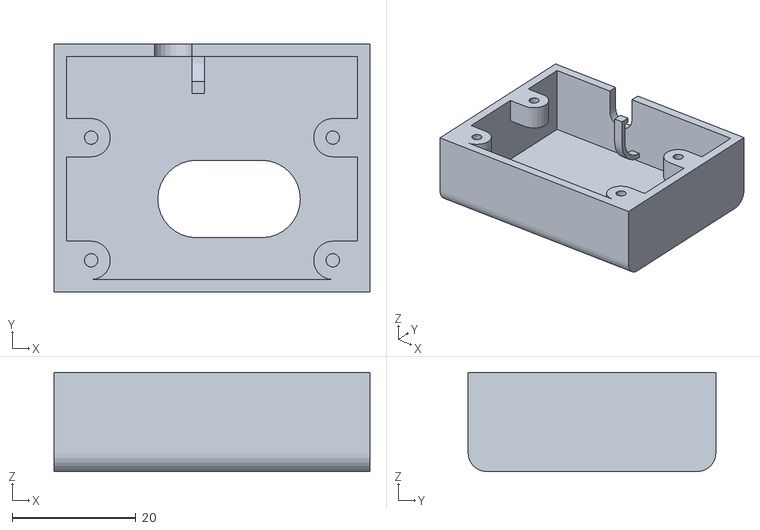
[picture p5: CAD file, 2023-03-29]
src/cad/rear_housing/LiDAR_Housing.stl
51.0 x 40.0 x 16.0

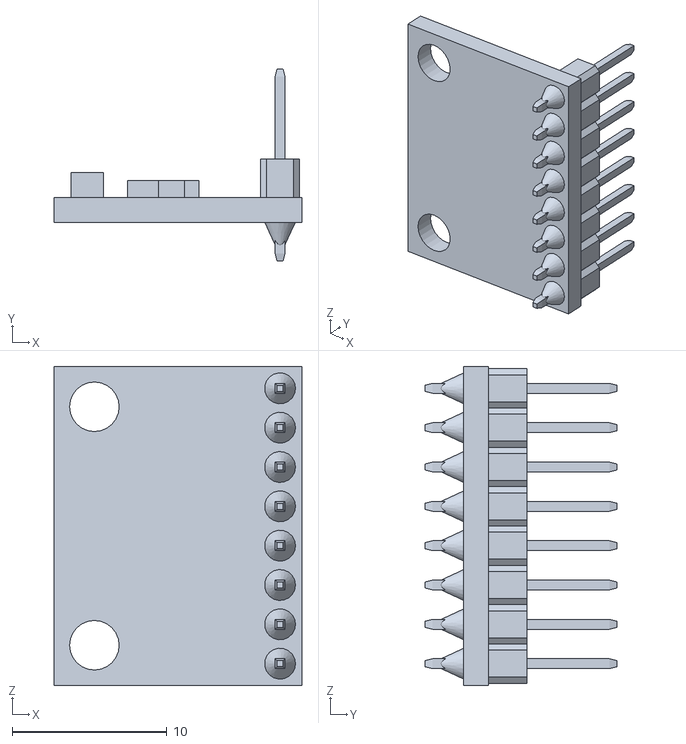
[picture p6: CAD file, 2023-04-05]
src/cad/ACCELEROMETER.stl
16.0 x 12.4 x 20.6

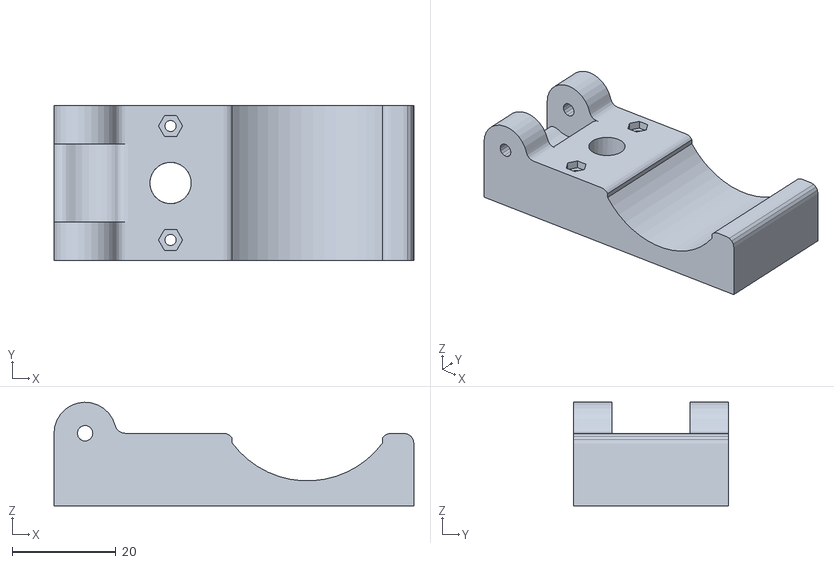
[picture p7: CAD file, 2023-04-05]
src/cad/bike_mount/BIKE_MOUNT_TOP.stl
69.5 x 30.0 x 20.0

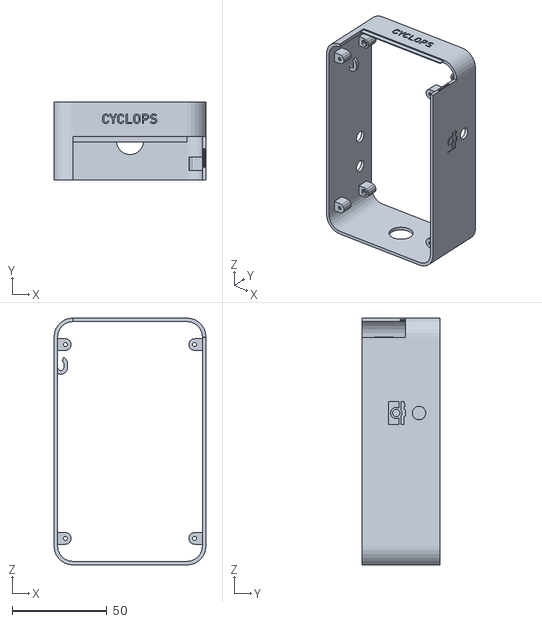
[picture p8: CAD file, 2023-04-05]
src/cad/front_housing/MIDDLE.stl
80.0 x 41.0 x 130.0

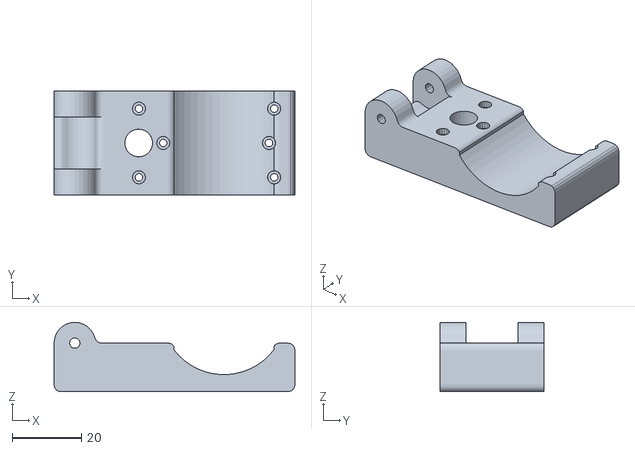
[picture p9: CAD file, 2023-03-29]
src/cad/rear_housing/Bike_Mount_Right_LiDAR.stl
69.5 x 30.0 x 20.0

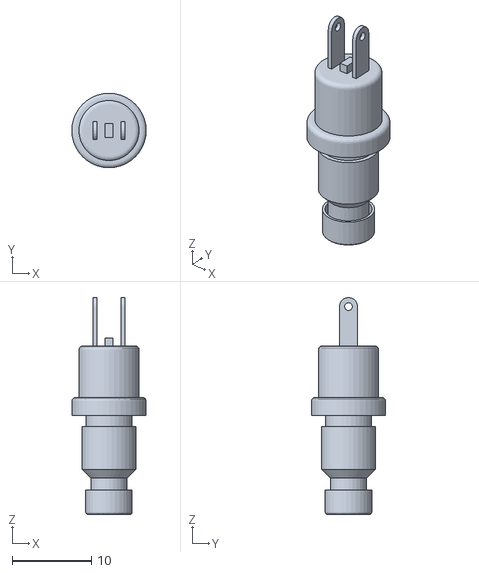
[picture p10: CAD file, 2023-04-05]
src/cad/BUTTON.stl
9.40 x 9.40 x 27.4

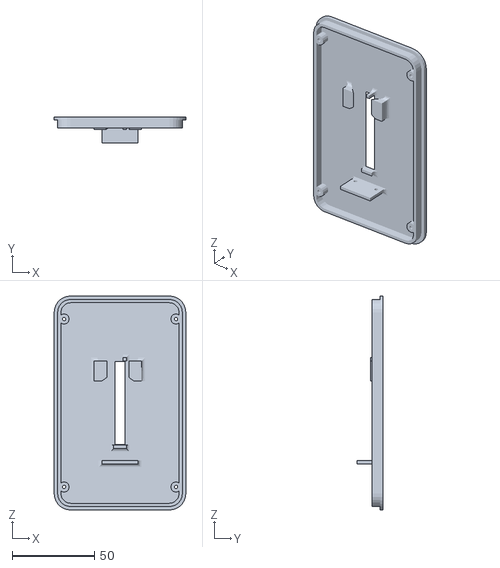
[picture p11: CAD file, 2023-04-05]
src/cad/front_housing/TOP.stl
80.0 x 16.0 x 130.0

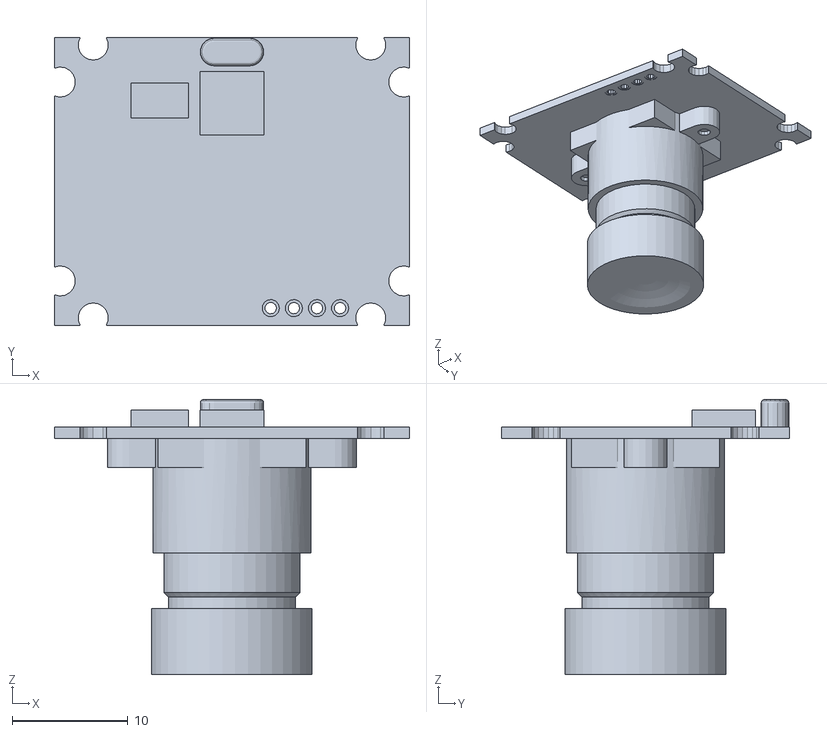
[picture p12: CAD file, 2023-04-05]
src/cad/CAMERA.stl
30.7 x 24.9 x 23.8

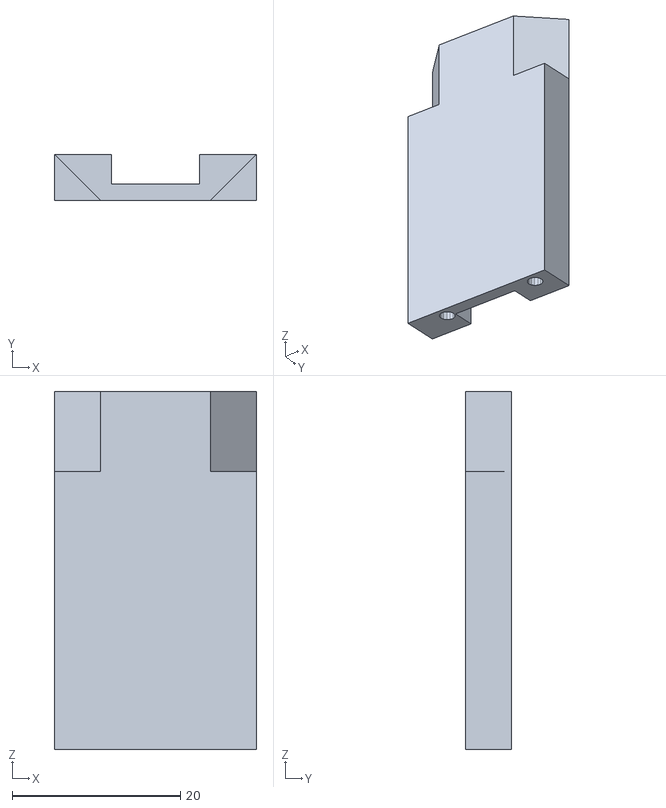
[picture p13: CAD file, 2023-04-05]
src/cad/front_housing/LED_HOUSING.stl
24.0 x 5.50 x 42.5

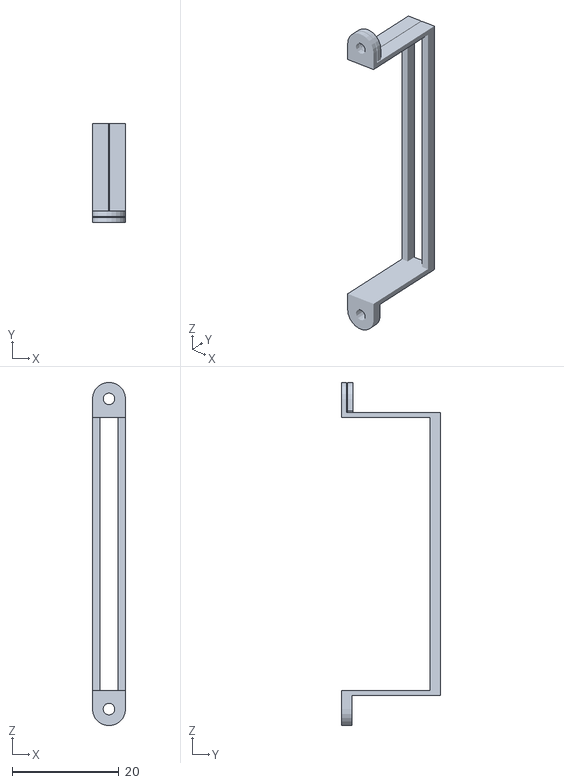
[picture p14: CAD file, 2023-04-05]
src/cad/front_housing/WIRE_HOUSING.stl
6.20 x 18.6 x 64.1

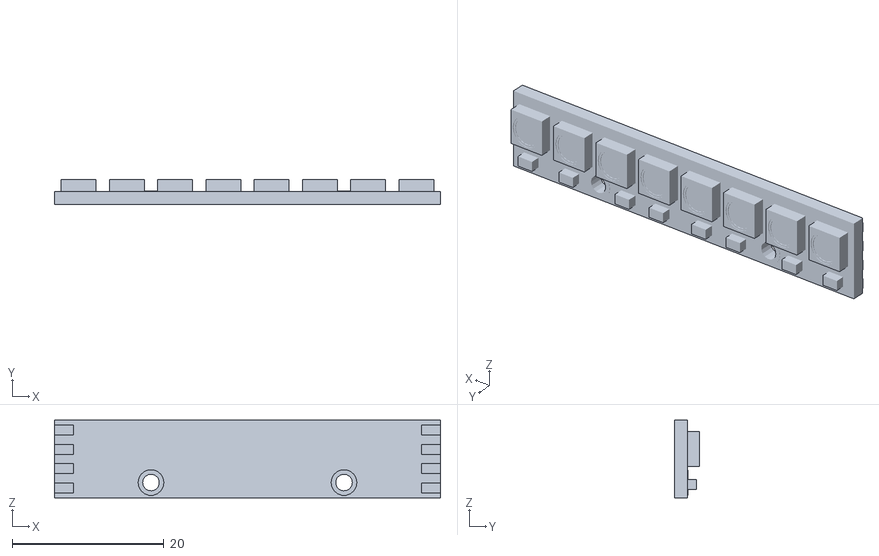
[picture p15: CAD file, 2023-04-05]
src/cad/LED.stl
50.8 x 3.35 x 10.2

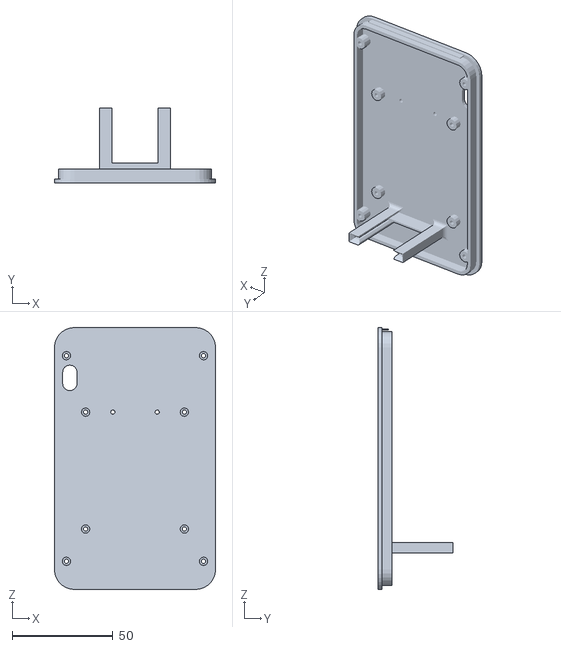
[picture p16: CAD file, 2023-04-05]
src/cad/front_housing/BOTTOM.stl
80.0 x 37.0 x 130.0

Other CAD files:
src/cad/RASPBERRY PI.stl
src/cad/BOLT.stl
src/cad/NUT.stl
src/cad/ACCELEROMETER.ipt
src/cad/BOLT.ipt
src/cad/BUTTON.ipt
src/cad/CAMERA.ipt
src/cad/LED.ipt
src/cad/NUT.ipt
src/cad/bike_mount/BIKE_MOUNT_BOTTOM.ipt
src/cad/bike_mount/BIKE_MOUNT_TOP.ipt
src/cad/front_housing/BOTTOM.ipt
src/cad/front_housing/DOOR.ipt
src/cad/front_housing/HOUSING.iam
src/cad/front_housing/LED_HOUSING.ipt
src/cad/front_housing/MIDDLE.ipt
src/cad/front_housing/PARAMETERS.ipt
src/cad/front_housing/TOP.ipt
src/cad/front_housing/WIRE_HOUSING.ipt
src/cad/rear_housing/Bike_Mount_Right_LiDAR.ipt
src/cad/rear_housing/LiDAR.iam
src/cad/rear_housing/LiDAR_Housing.ipt
src/cad/rear_housing/LiDAR_Sensor.ipt

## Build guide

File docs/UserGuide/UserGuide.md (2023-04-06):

<div align="center">

<a href="https://github.com/amosyu2000/cyclops">
	Cyclops header
</a>

# User Guide <!-- omit in toc -->
Cyclops Ride Assist: Cyclops Ride Assist: Real-Time Monitoring System<br/>  
__Team 9__  
Aaron Li (lia79)  
Amos Cheung (cheuny2)  
Amos Yu (yua25)  
Brian Le (leb7)  
Manny Lemos (lemosm1)  

</div>

 <!-- Page Break -->

## Table Of Contents <!-- omit in toc -->
- [1. Revision History](#1-revision-history)
- [2. Legal and Copyright Information and Disclaimer](#2-legal-and-copyright-information-and-disclaimer)
- [3. Introduction](#3-introduction)
- [4. Hardware Installation](#4-hardware-installation)
  - [4.1. Hardware Overview](#41-hardware-overview)
  - [4.2. Main Housing Assembly](#42-main-housing-assembly)
  - [4.3. Rear Housing Assembly](#43-rear-housing-assembly)
  - [4.4. Mounting and Dismounting the CRA](#44-mounting-and-dismounting-the-cra)
    - [4.4.1. Mounting the Main Housing of the CRA](#441-mounting-the-main-housing-of-the-cra)
    - [4.4.2. Mounting the Rear Housing of the CRA](#442-mounting-the-rear-housing-of-the-cra)
- [5. Instructions on Using the CRA](#5-instructions-on-using-the-cra)
  - [5.1. Pre-Trip Power On Sequence](#51-pre-trip-power-on-sequence)
  - [5.2. Post-Trip Power Off Sequence](#52-post-trip-power-off-sequence)
  - [5.3. Logging Data from the CRA](#53-logging-data-from-the-cra)
  - [5.4. Interpreting a Capture Sequence Debug](#54-interpreting-a-capture-sequence-debug)
  - [5.5. Retrieving the Video, LiDAR, and Accelerometer Data](#55-retrieving-the-video-lidar-and-accelerometer-data)
- [6. Troubleshooting](#6-troubleshooting)
- [7. Frequently Asked Questions](#7-frequently-asked-questions)

## List of Tables <!-- omit in toc -->
- [Table 1.1: Revision History](#rh)
- [Table 4.1: All Hardware Components](#hc)

## List of Figures <!-- omit in toc -->
- [Figure 3.1: The Cyclops Ride Assist](#cra)  
- [Figure 4.1: Hardware Components of the Cyclops Ride Assist](#hcra)  
- [Figure 4.2: The Main Housing of the Cyclops Ride Assist (CAD)](#mh)
- [Figure 4.3: The Internals of the Main Housing of the Cyclops Ride Assist](#mhi)
- [Figure 4.4: The Rear Housing of the Cyclops Ride Assist (CAD)](#rhc)
- [Figure 4.5: The Main Housing of the Cyclops Ride Assist](#mhca)
- [Figure 4.6: The Rear Housing of the Cyclops Ride Assist](#rhca)
- [Figure 4.7: The Clamp of the Cyclops Ride Assist](#crac)
- [Figure 5.1: The Cyclops Ride Assist on a Bicycle](#bike)
- [Figure 5.2: The On and Off Button of the Cyclops Ride Assist](#onof)
- [Figure 5.3: The Capture Button of the Cyclops Ride Assist](#capt)
- [Figure 5.4: The Special LEDs of the Cyclops Ride Assist](#ledc)
- [Figure 5.5: The Sliding Door and USB Access of the Cyclops Ride Assist](#sdus)

## 1. Revision History
<div align="center">
<p id="rh">Table 1.1: Revision History</p>

| Date | Developer(s) | Change |
|:--|:--|:--|
| April 5, 2023 | Aaron Li, Manny Lemos | Document created |

</div>

## 2. Legal and Copyright Information and Disclaimer

The Cyclops Ride Assist as well as its accompanying documentation is licensed under the Cyclops Team in the Department of Computing and Software (CAS) at McMaster University. All Hardware and Software is the intellectual property of CAS. CAS reserves the right to nullify any aspect or agreement in the Cyclops Ride Assist as well as in its accompanying documentation with no prior notice.

As the product has been deemed open-source, you may develop or re-create the Product for personal, non-commercial, or commercial use as you deem fit with the proper citations. The Team and CAS will not be held liable in the event of any possible hazards or consequences created from the Product that may or may not be limited to physical, mental, health damages, technical issues, or factors out of the Team's control.

By using this product, you accept and agree to be bound by the Terms and Conditions. 

Copyright © 2023 Cyclops, Department of Computing and Software (CAS), McMaster University. 

## 3. Introduction

This document is the User Guide for the Cyclops Ride Assist (CRA). It will cover all required installations, assemblies, mounting and dismounting, and proper usage. Furthermore, some common troubleshooting techniques will be introduced as well as some frequently asked questions. 
The CRA is an all-in-one, easily mountable, and quick to setup system that adds modern car safety features onto a bicycle or motorcyCle. These features include rear vehicle detection, crash detection, and automatic video and data capture with upload. This ensures that the Cyclops Ride Assist can be immediately used out of package. The User Guide will thus outline the best practices on mounting the CRA to their own personal bicycle.

<div align="center">

  

<p id="cra">Figure 3.1: The Cyclops Ride Assist</p>
</div>

## 4. Hardware Installation 
### 4.1. Hardware Overview

As the Cyclops Ride Assist is a complete product consisting of both hardware and software, it is imperative to correctly install both to ensure proper use. This section will outline the proper technique required to do so. Both the main and rear housing assembly will be pre-assembled prior to delivery to a user.

Pictured below in Figure 3.1 are the components of the Cyclops Ride Assist. Cables are provided. Batteries are not included.

<div align="center">



<p id="hcra">Figure 4.1: All hardware components of the Cyclops Ride Assist.</p>
</div>

<div align="center">

| Hardware Component Name | Assembly Location| Number of Pieces |
|:--|:--|:--|
| Raspberry Pi Model B | Main Housing | 1 |
| 1080p USB Camera  | Main Housing | 1 |
| Accelerometer ADXL-345 | Main Housing | 1 |
| Adafruit Neopixel LED Striplight | Main Housing | 1 |
| On, Off, Capture Push Button | Main Housing | 3 |
| Main Housing (Top) | Main Housing | 1 |
| Main Housing (Middle) | Main Housing | 1 |
| Main Housing (Bottom) | Main Housing | 1 |
| Clamp for Main Housing (Top) | Main Housing | 1 |
| Clamp for Main Housing (Bottom) | Main Housing | 2 |
| Sliding Door | Main Housing | 1 |
| Camera Slot | Main Housing | 1 |
| LED Housing Slot | Main Housing | 1 |
| TF-Luna LiDAR Sensor  | Rear Housing | 1 |
| Rear Housing | Main Housing | 1 |
| Clamp for Rear Housing (Top) | Rear Housing | 1 |
| M2 x 20mm Nuts | Main and Rear Housing | 22 |
| M2 Bolts | Main and Rear Housing | 22 |
<p id="hc">Table 4.1: All Hardware Components of the Cyclops Ride Assist</p>
</div>

### 4.2. Main Housing Assembly
The Main Housing Assembly will come pre-assembled to the users. All external components can be purchased through approved third party vendors and the 3D printed components will be sourced locally. 

<div align="center">



<p id="mh">Figure 4.2: The Main Housing of the Cyclops Ride Assist.</p>
</div>

<div align="center">



<p id="mhi">Figure 4.3: The Internals of the Main Housing of the Cyclops Ride Assist.</p>
</div>

### 4.3. Rear Housing Assembly
The Rear Housing Assembly will come pre-assembled to the users. All external components can be purchased through approved third party vendors and the 3D printed components will be sourced locally. 

<div align="center">



<p id="rhc">Figure 4.4: The Rear Housing of the Cyclops Ride Assist (CAD).</p>
</div>

### 4.4. Mounting and Dismounting the CRA

#### 4.4.1. Mounting the Main Housing of the CRA
| Step Number |  Instruction |
|:--|:--|
| 1 | Securely mount the CRA to your bicycle. |
| 2 | Place the housing clamp onto the handlebars of your bicycle. Tighten the clamp by spinning the tightener clockwise. | 
| 3 | Ensure the camera is facing forward. |
| 4 | Ensure the LED strip is visible while seated in your riding position. |
| 5 | Ensure all cables are securely strapped to the bicycle such that no cable is overhanging.|
<div align="center">


<p id="mhca">Figure 4.5: The Main Housing of the Cyclops Ride Assist.</p>
</div>   

#### 4.4.2. Mounting the Rear Housing of the CRA

| Step Number |  Instruction |
|:--|:--|
| 1 | Complete [Section 4.4.1.](#441-mounting-the-main-housing-of-the-cra)|
| 2 | Place the rear clamp onto the seat bar of your bicycle. Tighten the clamp by spinning the tightener clockwise. | 
| 2 | Ensure the LiDAR sensor is facing away from the bicycle and is level. |
| 3 | Ensure all cables are securely strapped to the bicycle such that no cable is overhanging.|

<div align="center">



<p id="rhca">Figure 4.6: The Main Housing of the Cyclops Ride Assist (CAD).</p>
</div>

<div align="center">



<p id="crac">Figure 4.7: The Clamp of the Cyclops Ride Assist (CAD).</p>
</div>

## 5. Instructions on Using the CRA
Below are the instruction on how to use the CRA once fully assembled on a bicycle. Please ensure that the previous sections have already been completed.

<div align="center">



<p id="bike">Figure 5.1: The Cyclops Ride Assist Mounted Properly on a Bicycle.</p>
</div>

### 5.1. Pre-Trip Power On Sequence
In order to setup the CRA prior to a trip, please do the following: 

| Step Number |  Instruction |
|:--|:--|
| 1 | Securely mount the CRA to your bicycle using [Section 4.4](#44-mounting-and-dismounting-the-cra) above. |
| 2 | Locate a portable battery capable of consistently outputting 5V. |
| 2a | Ensure the battery is charged beyond 60%. |
| 3 | Securely fasten the battery into the battery carrying pouch. |
| 4 | Connect the USB power cable to the battery. |
| 5 | Power on the battery. |
| 6 | Press the WHITE button labeled '1' located on the left side of the main housing. |
| 7 | Wait for the GREEN welcome sequence on the LEDs. |
| 8 | Begin your trip. |

### 5.2. Post-Trip Power Off Sequence
In order to turn off the CRA after a trip, please do the following: 

| Step Number |  Instruction |
|:--|:--|
| 1 | Press the black Power Off button labeled ‘0’ located on the left side of the main housing and as seen in Figure 5.2 below. |
| 2 | Wait for the RED goodbye sequence on the LEDs. |
| 3 | Power off your portable battery. |
| 4 | Remove the CRA from your bicycle. |

<br/>
<div align="center">



<p id="onof">Figure 5.2: The On and Off Button.</p>
</div>

### 5.3. Logging Data from the CRA
In the event of a system recognized collision, data logging will occur automatically 10 seconds after the crash without any user intervention. 

Logging can also occur when the user presses the BLUE capture button on the side of the main housing.  

| Step Number |  Instruction |
|:--|:--|
| 1 | Ensure the Pre-Trip Power On Sequence has been followed completely. |
| 2 | Press the BLUE capture button labelled with a camera icon located on the right side of the main housing. |

<div align="center">



<p id="capt">Figure 5.3: The Capture Button.</p>
</div>

### 5.4. Interpreting a Capture Sequence Debug

Following a system detected collision or capture button press, the CRA will do the following actions automatically: 

| Action |  Instruction |
|:--|:--|
| 1 | Following a system detected crash or capture button press, the CRA will log 60 seconds of accelerometer, camera, and LiDAR data.  |
| 2 | Following the logging, the user is notified separately of the success or failure of each of these 3 logging events. |
| 3 | Wait between 0 to 10 seconds after a system detected crash or capture button press for all footage and data to log.|
| 4 |Note the blinking color of the 3 LEDs closest to the user. Blue would indicate a SUCCESS and red would indicate a FAILURE. Please refer to [Section 6: Troubleshooting](#6-troubleshooting) for further help.|
| 4a |The LEDs correspond to: <br/> Accelerometer (closest LED to user)<br/>  Camera (2nd closest LED to user) <br/> LiDAR (3rd closest LED to user)|

<div align="center">



<p id="ledc">Figure 5.4: The Special LED Buttons.</p>
</div>

### 5.5. Retrieving the Video, LiDAR, and Accelerometer Data
In order to view the video footage, LiDAR files, or accelerometer data files, a personal computer must be used. The following steps will outline how to do so.

| Step |  Instruction |
|:--|:--|
| 1 | Open the sliding door on the rear of the main housing to expose the USB stick.  |
| 2 | Pull the USB stick out of the USB port.  |
| 3 | Plug the USB stick into your device (personal computer, laptop, etc.)|
| 4 |Copy any videos or files you would like to save onto your device. All files are located inside "Capture" folders.|
| 5 |(OPTIONAL) Reformat the USB stick as FAT32 to wipe all data.|

<div align="center">



<p id="sdus">Figure 5.5: The Sliding Door for USB Access.</p>
</div>

## 6. Troubleshooting
In the event of an error, please do the following: 

| Action |  Instruction |
|:--|:--|
| 1 | Determine the cause of the issue (accelerometer, camear, LiDAR) based on the LED lights as outlined in Step 3 and 4 of [Section 5.4](#54-interpreting-a-capture-sequence-debug) |
| 1a | If the accelerometer is the issue, open the CRA Main Housing. Check to see if the accelerometer cables are properly connected to the microcontroller. |
| 1b | If the camera is the issue, open the CRA Main Housing. Check to see if the camera cables are properly connected to the microcontroller.|
| 1c | If the LiDAR is the issue, ensure that the wires are connected properly at the CRA Rear Housing.|
| 2 | If the above actions do not work, please power off the CRA using the BLACK button under the '0', wait 30s, and then power it on using the WHITE button under the '1' button.|
| 3 | If the above actions do not work, please power off the CRA through the battery, wait 30s, re-power on the battery, and then power the CRA on using the WHITE button under the '1' button.|

## 7. Frequently Asked Questions 
Q: Will the CRA system work with my bicycle?   
A: CRA is intended to work with all modern bicycles. Its universal clamp can grip posts from 1” up to 3.5” in diameter.

Q: Where can I ask further questions about the Cyclops Ride Assist? Where can I submit a ticket for an issue?
A: An issue or question can be created on our repository, available [here](https://github.com/amosyu2000/cyclops) on Github.

Q: How can I contribute to the Cyclops Ride Assist software/hardware?   
A: All of our software and hardware drawings are open-source and available  [here](https://github.com/amosyu2000/cyclops) on Github.

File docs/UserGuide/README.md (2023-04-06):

<div align="center">

# User Guide




</div>

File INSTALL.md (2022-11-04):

Check the [wiki](https://github.com/amosyu2000/cyclops/wiki) for installation instructions.

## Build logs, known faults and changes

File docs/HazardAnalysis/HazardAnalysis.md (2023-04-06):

<div align="center">

<a href="https://github.com/amosyu2000/cyclops">
	Cyclops header
</a>

# Hazard Analysis <!-- omit in toc -->
Cyclops Ride Assist: Real-Time Monitoring System.<br/>  
__Team 9__  
Aaron Li (lia79)  
Amos Cheung (cheuny2)  
Amos Yu (yua25)  
Brian Le (leb7)  
Manny Lemos (lemosm1)  

</div>

 <!-- Page Break -->

## Table Of Contents <!-- omit in toc -->
- [1. Revision History](#1-revision-history)
- [2. Introduction](#2-introduction)
- [3. Scope and Purpose](#3-scope-and-purpose)
- [4. Definition of Hazard](#4-definition-of-hazard)
- [5. Critical Assumptions](#5-critical-assumptions)
- [6. System Boundary](#6-system-boundary)
	- [6.1. Housing System Boundary](#61-housing-system-boundary)
		- [6.1.1. Physical Hazards](#611-physical-hazards)
		- [6.1.2. Software Hazards](#612-software-hazards)
	- [6.2. Software System Boundary](#62-software-system-boundary)
		- [6.2.1. Physical Hazards](#621-physical-hazards)
		- [6.2.2. Software Hazards](#622-software-hazards)
	- [6.3. Microcontroller System Boundary](#63-microcontroller-system-boundary)
		- [6.3.1. Physical Hazards](#631-physical-hazards)
		- [6.3.2. Software Hazards](#632-software-hazards)
	- [6.4. Peripherals System Boundary](#64-peripherals-system-boundary)
		- [6.4.1. Physical Hazards](#641-physical-hazards)
		- [6.4.2. Software Hazards](#642-software-hazards)
	- [6.5. Camera System Boundary](#65-camera-system-boundary)
		- [6.5.1. Physical Hazards](#651-physical-hazards)
		- [6.5.2. Software Hazards](#652-software-hazards)
	- [6.6. LiDAR System Boundary](#66-lidar-system-boundary)
		- [6.6.1. Physical Hazards](#661-physical-hazards)
		- [6.6.2. Software Hazards](#662-software-hazards)
	- [6.7. Memory System Boundary](#67-memory-system-boundary)
		- [6.7.1. Physical Hazards](#671-physical-hazards)
		- [6.7.2. Software Hazards](#672-software-hazards)
- [7. Failure Modes and Effect Analysis](#7-failure-modes-and-effect-analysis)
	- [7.1. Hazards Out of Scope](#71-hazards-out-of-scope)
	- [7.2. Failure Modes and Effect Analysis Table](#72-failure-modes-and-effect-analysis-table)
- [8. Safety and Security Requirements](#8-safety-and-security-requirements)
	- [8.1. Safety Requirements](#81-safety-requirements)
	- [8.2. Access Requirements](#82-access-requirements)
	- [8.3. Integrity Requirements](#83-integrity-requirements)
	- [8.4. Privacy Requirements](#84-privacy-requirements)
- [9. Roadmap](#9-roadmap)
- [10. Appendix](#10-appendix)

## List of Tables <!-- omit in toc -->
- [Table 1.1: Revision History](#rh)
- [Table 7.2.1: Failure Modes and Effect Analysis](#fmea)

## List of Figures <!-- omit in toc -->

## 1. Revision History
<div align="center">

<p id="rh">Table 1.1: Revision History</p>

| Date | Developer(s) | Change |
|:--|:--|:--|
| 2022-10-19 | Aaron Li, Amos Cheung, Amos Yu, Brian Le, Manny Lemos | Document created |
| 2022-10-20 | Amos Yu | Improved formatting |
| 2022-11-06 | Amos Yu | Addressed peer review suggestions |
| 2023-03-25 | Aaron Li | Updated document, incorporate TA and peer feedback for Rev1| 

</div>

## 2. Introduction
This document is the hazard analysis of the Cyclops Ride Assist (CRA) system. The CRA is an all-in-one, easily mountable, and quick to setup system that adds modern car safety features onto a bicycle or motorcyle. These features include rear vehicle detection, crash detection, and automatic video and data capture with upload. 

## 3. Scope and Purpose
The scope of this document will be kept within the physical and software space of the CRA system boundary. Hazards imposed by the outer environment, society, and user error will be considered out of the scope for this document. At each major phase of production, this document will be updated to reflect any hazards that come up. Phases of production will include software design and implentation, hardware design and implementation, software and hardware testing, etc. 

The purpose of this document is to identify potential hazards which arise due to failures in the hardware and software used in the CRA system, the causes and effects of these failures, plans for hazard mitigation and potential elimination, and the safety and security requirements which emerge as a result of this knowledge. Requirements can be found extensively in our  [SRS](../SRS/SRS.md).
    
## 4. Definition of Hazard
A hazard is any property or condition in the CRA, that combined with environmental conditions, has the potential to cause harm to both the user and the various systems of the CRA. In the CRA, there are physical (mount, enclosure, wiring) and software hazards (video logging, vehicle detection) that will be mitigated to ensure safety-criticalness. A hazard is differentiable from an error in that an error results in degraded system performance but does not have the potential to cause harm. Hazards of the CRA will be discussed extensively in this document.    
## 5. Critical Assumptions
There are no critical assumptions that were made.    
## 6. System Boundary
The system boundary consists of all components within and on the surface of the physical space of the housing and mounting bracket. Although the system's environment can affect or be affected by the CRA, it will not be considered to be within the system boundary. Thus, the hazards can be classified by subdividing the system boundary into sub-systems and domains.   

### 6.1. Housing System Boundary
#### 6.1.1. Physical Hazards
The physical hazards within the housing system boundary are listed below.Consideration was given to components of the CRA that could lead to possible physical hazards to the user and system. Some possible environmental factors were also acknowledged. 

| Hazard | Possible Consequences |
|:--|:--|
|Temperature of Exterior Environment| This can cause extreme temperature conditions with the housing which may damage certain components of the housing.|
|Environmental Factors| Water can be introduced into the housing via holes, screwholes, etc, leading to housing damage.|
|Accidental Drop of Housing | The housing can be damaged by the surface upon which it has fallen (concrete, wood, glass, dirt, etc).|
|Inconsistent Mounting |Tilting and shifting of the bracket can occur, leading to instability of the system on the handlebars.|
|Significant Car Accident| A signficant external force applied to the housing (ex. a major crash, weight of the vehicle) can cause the housing to break.|
|Ergonomic Design| After prolonged use, the user may feel strained due to repeated movements. Possible repetitive movement can lead to further injury including carpal tunnel syndrome. |
|Clamp Design| Improper clamping can lead to possible damage to the housing. Since the force is high, physical harm can be caused to the user if clamped onto a finger or other body part.  |
#### 6.1.2. Software Hazards
Since the housing is a completely mechanical system, there are no software hazards within the housing system boundary.
| Hazard | Possible Consequences |
|:--|:--|
|-|-|
### 6.2. Software System Boundary
#### 6.2.1. Physical Hazards
The physical hazards contained within the software system boundary are listed below. Consideration was given to components of the CRA that could lead to possible software hazards to the user and system. 

| Hazard | Possible Consequences |
|:--|:--|
|Microcontroller Failures| Errors such as wiring issues, shorts, etc. can cause the microcontroller to become defective, leading to software malfunctions. This may lead to improper output of the system.|
|Cable Connections| Cables held within their own casing may become defective due to wear and tear, leading to communication issues and software errors. This is especially important at manually soldered areas. | 
|LiDAR Recognition Failure| A faulty LiDAR sensor can lead to incorrect data being inputted into the software. The LEDs will then display the incorrect information of objects approaching. |
|Accelerometer Inaccuracies| An inaccurate accelerometer reading can lead to false detections of a crash. This can lead to the software incorrectly identifying accidents vs non-accidents, which can be hazardous if the storage of the flash drive becomes filled unexpectedly.|

#### 6.2.2. Software Hazards
The software hazards contained within the software system boundary are listed below. Consideration was given to components of the CRA that could lead to possible software hazards to the user and system. 

| Hazard | Possible Consequences | 
|:--|:--|
| Error Handling | Unanticipated errors can cause the software process to behave unexpectedly, leading to bugs or crashes during operation. | 
|Memory Leak| A memory leak can cause the software process to crash after prolonged use. | 
|Cable Mismanagement| Crossing wires may become shorted or loose, leading to incorrect inputs and outputs if wires or pins accidentally touch improper connectors. |
| Algorithm Bottlenecks | Bottlenecks in the process can cause slow response and processing times. Having different processes run over a certain runtime can lead to even greater processing times. |
| Code Upkeep | Poor code upkeep can decrease code readability and maintainability. In the event of an error, hazards can arise from debug oversights. |

### 6.3. Microcontroller System Boundary
#### 6.3.1. Physical Hazards
The physical hazards contained within the microcontroller system boundary are listed below. Consideration was given to components of the CRA that could lead to possible physical hazards to the user and system. 

| Hazard | Possible Consequences | 
|:--|:--|
|Faulty Microcontroller Mounting| Improper mounting can cause the microcontroller to move around in the housing, damaging the controller and the housing.|
|High Microcontroller Temperature| High operating temperature can lead to damage to ports or connections. |
|Environmental Factors| The microcontroller can malfunction if introduced to enough dust, water, etc.|
|Power Failure| A power supply failure or surge can cause damage to various components on the microcontroller. |
|Physical and Static Force| Excessive force from an external factor such as a finger can damage components. Static force can induce a current that could cause damage to components. | 

#### 6.3.2. Software Hazards
The software hazards contained within the microcontroller system boundary are listed below. Consideration was given to components of the CRA that could lead to possible software hazards to the user and system. 

| Hazard | Possible Consequences | 
|:--|:--|
|Power Failure | A power supply failure or surge can cause the software processes to terminate at an unexpected state. |
|Microcontroller Damage| Damage to the microcontroller board via physical, static force can cause the firmware to malfunction. |
### 6.4. Peripherals System Boundary
#### 6.4.1. Physical Hazards
The physical hazards contained within the peripherals system boundary are listed below. Consideration was given to components of the CRA that could lead to possible physical hazards to the user and system. 
| Hazard | Possible Consequences | 
|:--|:--|
|Cable Agitation | Constant agitation can cause the peripheral cables to come loose from the micontroller or LiDAR sensor. Agitation can also cause the peripherals to fall from their mounting points. This will lead to unconnected cables and connections while the CRA is in use. |
|Exposed Wiring | Exposed wires with a current can inflict an electric shock to the user. |
|Environmental Factors| The peripherals can become damaged if exposed to enough water, dust, etc, leading to the failure of the CRA's features. |
|Power Failure | A power supply failure or surge can damage the peripherals with a high voltage. |
#### 6.4.2. Software Hazards
The software hazards contained within the peripherals system boundary are listed below. Consideration was given to components of the CRA that could lead to possible software hazards to the user and system. 

| Hazard | Possible Consequences | 
|:--|:--|
|Loose Peripherals| Peripherals can become loose, contaminating the data being collected by the accelerometer, LiDAR, and camera. |
|Cable Mismanagement| The cables of the peripherals can become intertwined with the bike's wires which could lead to falls. |
|Peripheral Boundary Limits| Software can exceed the limit as set out by the manufacturers of the peripheral, leading to unexpected behaviour. |
### 6.5. Camera System Boundary
#### 6.5.1. Physical Hazards
The physical hazards contained within the camera system boundary are listed below. Consideration was given to components of the CRA that could lead to possible physical hazards to the user and system. 

| Hazard | Possible Consequences | 
|:--|:--|
|Environmental Factors | Rain, dust, vehicle fumes, etc. can obscure the view on the lens of the camera, leading to improper footage capture which can not be used for further analysis. | 
|Bicycle Collision| A bicycle collision leading to severe contact between the camera and the surface can cause the front lens of the camera to shatter. | 
#### 6.5.2. Software Hazards
The software hazards contained within the camera system boundary are listed below. Consideration was given to components of the CRA that could lead to possible software hazards to the user and system. 

| Hazard | Possible Consequences | 
|:--|:--|
| Video Compression | Excessive compression of the video can lead to unclear or grainy footage, leading to improper footage capture which can not be used for further analysis.|
### 6.6. LiDAR System Boundary
#### 6.6.1. Physical Hazards
The physical hazards contained within the LiDAR system boundary are listed below. Consideration was given to components of the CRA that could lead to possible physical hazards to the user and system. 

| Hazard | Possible Consequences | 
|:--|:--|
|Cable Mismanagement| The cable of the LiDAR can become intertwined with the bicycle's regular cabling which could lead to dangling or hanging wires.|
|Environmental Factors| Various environmental factors can cause the LiDAR to crash, leading to electrical issues. |
|LiDAR Mounting| The clamp that the LiDAR is located on has a strong clamping force that can become a hazard if tightened improperly on unintended surfaces such as body parts. |
#### 6.6.2. Software Hazards
The software hazards contained within the LiDAR system boundary are listed below. Consideration was given to components of the CRA that could lead to possible software hazards to the user and system. 

| Hazard | Possible Consequences | 
|:--|:--|
|Software Misreads | Rain, dust, vehicle fumes, etc. can obscure the LiDAR's view, leading to inaccurate distance information provided to the software.|
|Environmental Factors| If the LiDAR sensor is exposed to enough factors including temperature, water, dust, the connections and pins make render useless, making the software behave unexpectedly. |

### 6.7. Memory System Boundary
#### 6.7.1. Physical Hazards
The physical hazards contained within the camera system boundary are listed below. Consideration was given to components of the CRA that could lead to possible physical hazards to the user and system. 
| Hazard | Possible Consequences | 
|:--|:--|
|Improper Contact| A flash drive with improper contact can cause unexpected interruptions during operation |
|Flash Drive Damage| Physical damage to the flash drive can lead it to not be properly plugged in to record footage.|
#### 6.7.2. Software Hazards
The software hazards contained within the memory system boundary are listed below. Consideration was given to components of the CRA that could lead to possible software hazards to the user and system. 

| Hazard | Possible Consequences | 
|:--|:--|
|Long File Write Time| Video may take more time to upload, creating a bottleneck in the system. |
|Storage Overflow | Too many files located in the memory can cause the system to overheat if writes continue to occur. |
|Power Supply Failure | A power supply failure or surge during file writing can corrupt the card.| 
## 7. Failure Modes and Effect Analysis
### 7.1. Hazards Out of Scope
Hazards Out of Scope will not be considered in the Failure Modes and Effect Analysis listed below in [Section 7.2](#72-failure-modes-and-effect-analysis-table).

| Group  | Example | 
|:--|:--|
|External Environment|Bicycle hazards (brakes, cabling, frame), road conditions (construction zones, potholes, traffic),  other factors (precipitation, temperature, air quality)|
|Society|City and rural design, video recording laws, theft, damage (graffiti)|
|User Error|Improper use and installation, excessive carelessness during handling, low battery, low storage, and low maintenance upkeep|
### 7.2. Failure Modes and Effect Analysis Table
The Failure Modes and Effect Analysis Table (FMEA) Table indicates the failure modes associated with certain design functions and the optimal response to minimize harm to the user or product. The FMEA able thus outlines the recommended course of action required for the CRA team to eliminate as many hazards or failures for its users.  

<div align="center">
<p id="fmea">Table 7.2.1: Failure Modes and Effect Analysis</p>

| Design Function | Ref # | Failure Mode | Effects of Failures | Causes of Failure | Recommended Action | SR |
|:--|:--|:--|:--|:--|:--|:--|
Crash Detection | H1-1 | False negative crash detection. | The current loop of video will not be logged to the storage device. | a. Sensor failure (bias, drift, complete failure, precision degradation). <br/> b. Crash was not violent enough to trigger a crash detection sequence. | a. Perform a sensor calibration and test when the CRA is turned on. Indicate an issue if one is detected. <br/> b. Allow users to force video loop logging with a  button. | a. SR-1 <br/> b. AR-1|
| | H1-2 | False positive crash detection. | An unnecessary loop of video will be logged to the storage device. | a. Sensor failure (bias, drift, complete failure, precision degradation). <br/> b. A non-crash event had trademark features of a crash (e.g. high force, tipping). | a. Same as H1-1a <br/> b.  Alert the user through the LED display that a video has started. Do not stop the video recording in the event of an accident. | a. SR-1 <br/> b. AR-1 |
| Video Export to Storage | H2-1 | Insufficient memory in storage device | Video loop will not be logged to the storage device. | a. Video loop is too large to be logged on the storage device or there is insufficient space on the storage device. | a. Notify the user that there is an insufficient amount of storage space on boot. In the event of a storage overflow, remove the oldest capture folders to accomodate for the incoming footage.  | a. SR-3 |
| | H2-2 | Obscured front-facing camera footage. | Camera footage will be void or non-optimal in the event of a camera loop logging. Footage cannot be used for review and analysis as required. | a. Debris or dust obstructs the camera's view. <br/> b. Complete camera or camera feed failure. | a. Create a housing that will allow for the complete camera to be covered. Place the camera in a location where it is unlikely to be impacted by any debris. <br/> b. Perform a camera and camera feed check when the CRA is turned on. Indicate an issue if one is detected. | a. IR-1 <br/> b. SR-1 |
| | H2-3 | Corruption of video files. | Video files are lost or become unreadable. | a. Physical damage to the flash drive. <br/> b. Improper contact between the flash drive and the memory slot. <br/> c. Multiple files being written concurrently. <br/> d. Power supply failure. | a. Design a physical barrier that prevents a damaged flash drive from being inserted into the memory slot. <br/> b. Alert the user in the case that there is no detected memory device inputted. If connected, alert the user if the drive cannot be written to. <br/> c. Only allow one video to be written to the memory drive at a time. <br/> d. Use a reliable power supply with a reliable connection. | a. IR-2, AR-1 <br/> b. IR-1 <br/> c. SR-3 <br/> d. IR-3 |
| Rear Vehicle Detection | H3-1 | False negative rear vehicle detection. | A vehicle exists in the user's rear view, but they are not alerted. | a. The vehicle is not detected by the LiDAR sensor. <br/> b. The LiDAR sensor is obstructed by debris. <br/> c. The LiDAR connection or feed fails. | a. Perform a sensitivity check on bootup to ensure that the LiDAR is connected properly through a debug mode. <br/> b. Same as H2-2a <br/> c. Same as H2-2b | a. SR-4 <br/> b. SR-1 <br/> c. SR-1 |
| | H3-2 | False positive rear vehicle detection. | A user is alerted that a vehicle exists in their rear view when no vehicle is present. | a. Debris obstructs the LiDAR's view. | a. Same as H2-2a | a. SR-1 |
| Rear Vehicle Alerting | H4-1 | Incorrect LED lights. | A vehicle exists in the user's rearview but the rear vehicle alerting system does not identify the distance correctly. The opposite also occurs. | a. Debris obstructs the LiDAR's view. <br/> b. The connection pins between the LiDAR and system have failed. </br> c. The LED has disconnected from some of the pins on the microcontroller.  | a. Same as H2-2a <br/> b. Perform a sensitivity check on the LEDs when powering the system on. <br/> c. Perform a sensitivity check on the LEDs when powering the system on. |a. IR-1 <br/> b. SR-1  <br/> c. SR-1|
|| H4-2 | Missing LED lights | The LED system does not light up at all when powered on. | a. The connection between the LiDAR system and the main system has failed. <br/> b. The LED system has come off the microcontroller. | a. Perform a sensitivity check on the LEDs when powering the system on. <br/> b. Perform a sensitivity check on the LEDs when powering the system on. |a. SR-1 <br/> b. SR-1|
| Hardware Housing | H5-1 | Housing integrity is violated. | Internal hardware components are damaged or destroyed. | a. Housing is submerged in water (e.g. rain, puddle, body of water). <br/> b. Housing is violently rattled. <br/> c. Housing is dropped to the ground. | a. Create a water-proof housing with minimal holes <br/> b. Secure the microcontroller using screws, nuts, and bolts to the housing. Secure the housing to the frame through a designed clamp. <br/> c. Make the housing robust and resistant to fall damage. Secure the housing to the frame through a designed clamp to minimize impact. | a. IR-1 <br/> b. SR-2, IR-1 <br/> c. SR-2 |
| | H5-2 | Poor ergonomical and accessible design. | User is susceptible to repetitive strain injuries.| a. Housing obstructs usage of bicycle handlebars. <br/> b. Buttons on the exterior of the housing are hard to use. <br/> c. Housing cannot be put together or taken apart easily. | a. Provide detailed instructions on how to mount the device in a non-obstructive way. <br/> b. Design buttons to be visible, intuitive, tactile, and easily accessible. <br/> c. Design housing using the same nut and bolt size and with intuitive mounting holes of where pieces should be placed. Create a user manual to aid installation. | a. SR-2 <br/> b. AR-2 <br/> c. AR-2|
| Bicycle Mount For Housing | H6-1 | Mount failure. | Housing is dropped to the ground. | a. Mount is impacted by debris. <br/> b. Rattling loosens mount grip. | a. Place the mount in a position unlikely to be impacted by debris. <br/> b. Instruct user to firmly tighten the mount to their bicycle like the metal frame bar. Line the gripping portion of the mount with rubber to increase friction and fit. | a. SR-2, IR-1 <br/> b. SR-2, IR-1 |
| System Firmware | H7-1 | Hardware malfunction. | The microcontroller is unable to execute the software as intended. | a. Power supply failure. <br/> b. Poor mounting of the microcontroller. | a. Same as H2-3d <br/> b. Design a durable mount for the microcontroller, and test the reliability during crashes. | a. IR-3 <br/> b. IR-1 |
| | H7-2 | Software malfunction. | The real-time software running on the microcontroller does not behave as intended. | a. Unanticipated errors in software. <br/> b. Poor code upkeep. | a. Run the software process for a prolonged period of time. <br/> b. Enforce readable, maintainable code. | a. PR-1 <br/> b. PR-2 |

</div>

## 8. Safety and Security Requirements

### 8.1. Safety Requirements
| SR-1 |  A system welfare check will be conducted each time the CRA is powered on to verify that all cameras and sensors are successfully communicating with the microcontroller. |  
|:--|:--|
| Rationale |A problem with the LiDAR sensor could result in unexpected rear view detection behaviour (false positives or false negatives). A problem with the rear facing camera could result in footage of a crash being lost. A problem with crash detection sensors could result in unexpected crash detection behaviour (false positives or false negatives).|  
| Associated Hazards |  H1-1a, H1-2a, H2-2b, H2-3b, H3-1b, H3-1c, H3-2a, H4-1b, H4-1c, H4-2a, H4-2b |  

| SR-2 |  Safety instructions will be created to ensure that the CRA is properly equipped and mounted for the user.  |  
|:--|:--|
| Rationale | Instructions will allow the user to properly mount and maintain their system.|  
| Associated Hazards | H5-1b, H5-1c, H5-2a, H6-1a, H6-1b |  

| SR-3 | System self-assessments will optimize video storage to ensure there is enough space to hold videos and will alert the user if the space is insufficient. |  
|:--|:--|
| Rationale | In the case that the storage memory device is full, videos will be cut short to ensure that the user has the footage of the latest accident that they have been involved in. |  
| Associated Hazards | H2-1a, H2-3c |  

| SR-4 |  The camera, LiDAR, camera feed will be checked on startup by the system to ensure that all required software is connected and usable. |  
|:--|:--|
| Rationale | This is to ensure that the camera is able to create and log video data as required on vehicle collision. This is also to ensure the LiDAR sensing is able to detect distances of objects accurately. |  
| Associated Hazards |  H3-1a |  

### 8.2. Access Requirements
| AR-1 |  CRA will allow the users to access their videos freely from an external hardware storage drive. |  
|:--|:--|
| Rationale | This is to allow the user to connect it to their own personal systems to view, delete their videos. There is no need for encryption as this would complicate the process. |  
| Associated Hazards | H2-3a |  

| AR-2 |  CRA will be ergonomically designed to accomodate all cyclists, including cyclists with special physical accessibility needs. |  
|:--|:--|
| Rationale | The design of the device should feel seamless without interfering with the user experience for cyclists with accessibility needs. |  
| Associated Hazards | H5-2b, H5-2c |  

### 8.3. Integrity Requirements
| IR-1 |  The mounting system will be made with solid and sustainable material to ensure mechanical integrity. |  
|:--|:--|
| Rationale | This will be able to withstand changes in weather and temperature, accidental drops, and debris. |  
| Associated Hazards |  H2-2a, H4-1a, H5-1b, H6-1a, H6-1b, H7-1b |  

| IR-2 | The housing will protect its interior from undesired foreign items. |  
|:--|:--|
| Rationale | This will keep damaging substances like water, debris, and dust out while allowing access to necessary components like memory and charging ports |  
| Associated Hazards | H2-3a |  

| IR-3 | The components that are sourced from third-parties will be upheld to a quality level corresponding to their importance. |  
|:--|:--|
| Rationale | As we cannot economically create every part of the device ourselves, we will need to source basic parts from third-party manufacturers. These parts need to be reliable enough to operate as intended. |  
| Associated Hazards | H2-3d, H7-1a |  

### 8.4. Privacy Requirements
| PR-1 |  CRA will not be connected to the internet but will be used and trained locally for CV purposes. |  
|:--|:--|
| Rationale | This is to ensure that the footage of accidents will not be posted on the internet without the consent of the user. Instead all footage will be saved to an external hardware storage device. | 
| Associated Hazards | H7-2a |  

| PR-2 | Code will be open-sourced, but only select individuals will be allowed to contribute to the master branch of the main repository. |  
|:--|:--|
| Rationale | This will ensure that the code running on the device follows the coding standards and is peer-reviewed by members of the team. | 
| Associated Hazards | H7-2b |  

## 9. Roadmap
The roadmap of CRA is a projection of the safety and security requirements listed above. The majority of these requirements will be implemented on the initial prototype and final application due to the nature of the system and its functionalities. Requirements will be constantly reevaluated with several factors in consideration such as time and project constraints. Towards the end of the project, the Hazard Analysis document will be an evaluation over the project to get an understanding of what risks have been successfully mitigated and which ones will still require work.

With the conclusion of the CRA approaching, the Hazard Analysis was reconsidered to accomodate for any changes or additions. Changes included the introduction of camera and video logging for the rear vehicle detection camera, the LiDAR sensor along with the rear vehicle alerting LED system, as well as the removal of the use of computer vision. Throughout the design process and verification and validation phase, the Hazard Analysis was repeatedly considered which allowed the team to miitigate all risks outlined in this document. Further addendums or updates will be created in the case any discrepancies that arise. 

## 10. Appendix

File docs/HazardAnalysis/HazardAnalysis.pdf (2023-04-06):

HazardAnalysis.md | 4/5/2023
RIDE ASSIST RIDE ASSIST RIDE ASSIST RIDE ASSIST RIDE (https://github.com/amosyu2000/cyclops)

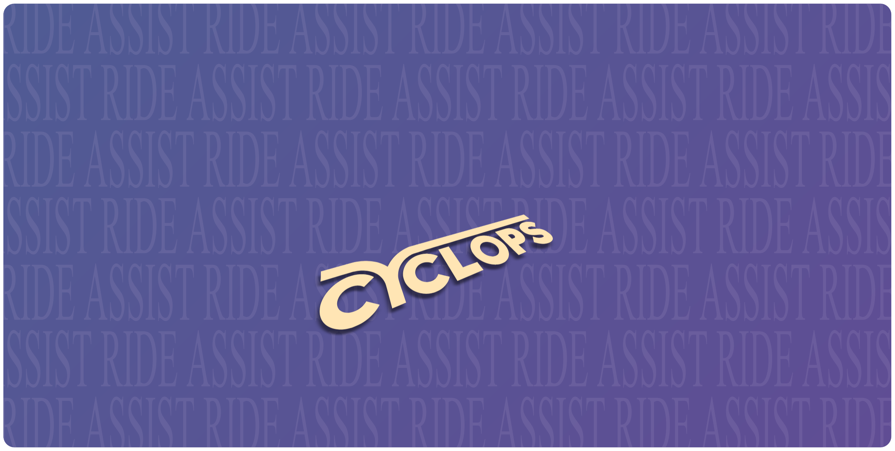
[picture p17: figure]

# ASSIST RIDE ASSIST RIDE ASSIST RIDE ASSIST RIDE ASSIS

RIDE ASSIST RIDE ASSIST RIDE ASSIST RIDE ASSIST RIDE (https://github.com/amosyu2000/cyclops)

# ASSIST RIDE ASSIST RIDE ASSIST RIDE ASSIST RIDE ASSIS

RIDE ASSIST RIDE ASSIST RIDE ASSIST RIDE ASSIST RIDE (https://github.com/amosyu2000/cyclops)

# ASSIST RIDE ASSIST RIDE ASSIST RIDE ASSIST RIDE ASSIS

RIDE ASSIST RIDE ASSIST RIDE ASSIST RIDE ASSIST RIDE (https://github.com/amosyu2000/cyclops)

# Hazard Analysis

Cyclops Ride Assist: Real-Time Monitoring System.

Team 9
Aaron Li (lia79)
Amos Cheung (cheuny2)
Amos Yu (yua25)
Brian Le (leb7)
Manny Lemos (lemosm1)

## Table Of Contents

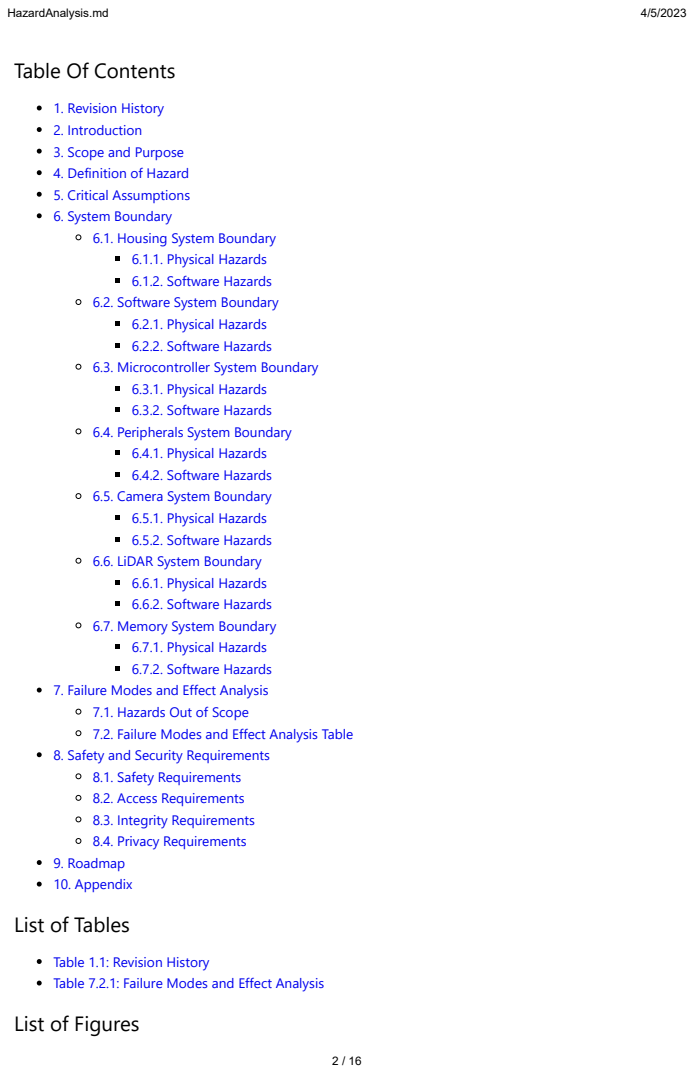
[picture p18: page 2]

1. Revision History
2. Introduction
3. Scope and Purpose
4. Definition of Hazard
5. Critical Assumptions
6. System Boundary
6.1. Housing System Boundary
6.1.1. Physical Hazards
6.1.2. Software Hazards
6.2. Software System Boundary
6.2.1. Physical Hazards
6.2.2. Software Hazards
6.3. Microcontroller System Boundary
6.3.1. Physical Hazards
6.3.2. Software Hazards
6.4. Peripherals System Boundary
6.4.1. Physical Hazards
6.4.2. Software Hazards
6.5. Camera System Boundary
6.5.1. Physical Hazards
6.5.2. Software Hazards
6.6. LiDAR System Boundary
6.6.1. Physical Hazards
6.6.2. Software Hazards
6.7. Memory System Boundary
6.7.1. Physical Hazards
6.7.2. Software Hazards

7. Failure Modes and Effect Analysis
7.1. Hazards Out of Scope
7.2. Failure Modes and Effect Analysis Table
8. Safety and Security Requirements
8.1. Safety Requirements
8.2. Access Requirements
8.3. Integrity Requirements
8.4. Privacy Requirements
9. Roadmap
10. Appendix
List of Tables

Table 1.1: Revision History
Table 7.2.1: Failure Modes and Effect Analysis
List of Figures

## 1. Revision History

Table 1.1: Revision History

Date | Developer(s) | Change
2022- 10-19 | Aaron Li, Amos Cheung, Amos Yu, Brian Le, Manny Lemos | Document created
2022- 10-20 | Amos Yu | Improved formatting
2022- 11-06 | Amos Yu | Addressed peer review suggestions
2023- 03-25 | Aaron Li | Updated document, incorporate TA and peer feedback for Rev1

## 2. Introduction

This document is the hazard analysis of the Cyclops Ride Assist (CRA) system. The CRA is an all-in-one, easily mountable, and quick to setup system that adds modern car safety features onto a bicycle or motorcyle. These features include rear vehicle detection, crash detection, and automatic video and data capture with upload.

## 3. Scope and Purpose

The scope of this document will be kept within the physical and software space of the CRA system boundary. Hazards imposed by the outer environment, society, and user error will be considered out of the scope for this document. At each major phase of production, this document will be updated to reflect any hazards that come up. Phases of production will include software design and implentation, hardware design and implementation, software and hardware testing, etc.

The purpose of this document is to identify potential hazards which arise due to failures in the hardware and software used in the CRA system, the causes and effects of these failures, plans for hazard mitigation and potential elimination, and the safety and security requirements which emerge as a result of this knowledge. Requirements can be found extensively in our SRS.

## 4. Definition of Hazard

A hazard is any property or condition in the CRA, that combined with environmental conditions, has the potential to cause harm to both the user and the various systems of the CRA. In the CRA, there are physical (mount, enclosure, wiring) and software hazards (video logging, vehicle detection) that will be mitigated to ensure safety-criticalness. A hazard is differentiable from an error in that an error results in degraded system performance but does not have the potential to cause harm. Hazards of the CRA will be discussed extensively in this document.

## 5. Critical Assumptions

There are no critical assumptions that were made.

## 6. System Boundary

The system boundary consists of all components within and on the surface of the physical space of the housing and mounting bracket. Although the system's environment can affect or be affected by the CRA, it will not be considered to be within the system boundary. Thus, the hazards can be classified by subdividing the system boundary into sub-systems and domains.
6.1. Housing System Boundary

### 6.1.1. Physical Hazards

The physical hazards within the housing system boundary are listed below.Consideration was given to components of the CRA that could lead to possible physical hazards to the user and system. Some possible environmental factors were also acknowledged.

Hazard | Possible Consequences
Temperature of Exterior Environment | This can cause extreme temperature conditions with the housing which may damage certain components of the housing.
Environmental Factors | Water can be introduced into the housing via holes, screwholes, etc, leading to housing damage.
Accidental Drop of Housing | The housing can be damaged by the surface upon which it has fallen (concrete, wood, glass, dirt, etc).
Inconsistent Mounting | Tilting and shifting of the bracket can occur, leading to instability of the system on the handlebars.
Significant Car Accident | A signficant external force applied to the housing (ex. a major crash, weight of the vehicle) can cause the housing to break.
Ergonomic Design | After prolonged use, the user may feel strained due to repeated movements. Possible repetitive movement can lead to further injury including carpal tunnel syndrome.
Clamp Design | Improper clamping can lead to possible damage to the housing. Since the force is high, physical harm can be caused to the user if clamped onto a finger or other body part.

### 6.1.2. Software Hazards

Since the housing is a completely mechanical system, there are no software hazards within the housing system boundary.

Hazard Possible Consequences

6.2. Software System Boundary

### 6.2.1. Physical Hazards

The physical hazards contained within the software system boundary are listed below. Consideration was given to components of the CRA that could lead to possible software hazards to the user and system.

Hazard | Possible Consequences
Microcontroller Failures | Errors such as wiring issues, shorts, etc. can cause the microcontroller to become defective, leading to software malfunctions. This may lead to improper output of the system.
Cable Connections | Cables held within their own casing may become defective due to wear and tear, leading to communication issues and software errors. This is especially important at manually soldered areas.
LiDAR Recognition Failure | A faulty LiDAR sensor can lead to incorrect data being inputted into the software. The LEDs will then display the incorrect information of objects approaching.
Accelerometer Inaccuracies | An inaccurate accelerometer reading can lead to false detections of a crash. This can lead to the software incorrectly identifying accidents vs non-accidents, which can be hazardous if the storage of the flash drive becomes filled unexpectedly.

### 6.2.2. Software Hazards

The software hazards contained within the software system boundary are listed below. Consideration was given to components of the CRA that could lead to possible software hazards to the user and system.

Hazard | Possible Consequences
Error Handling | Unanticipated errors can cause the software process to behave unexpectedly, leading to bugs or crashes during operation.
Memory Leak | A memory leak can cause the software process to crash after prolonged use.
Cable Mismanagement | Crossing wires may become shorted or loose, leading to incorrect inputs and outputs if wires or pins accidentally touch improper connectors.
Algorithm Bottlenecks | Bottlenecks in the process can cause slow response and processing times. Having different processes run over a certain runtime can lead to even greater processing times.
Code Upkeep | Poor code upkeep can decrease code readability and maintainability. In the event of an error, hazards can arise from debug oversights.
6.3. Microcontroller System Boundary

### 6.3.1. Physical Hazards

The physical hazards contained within the microcontroller system boundary are listed below. Consideration was given to components of the CRA that could lead to possible physical hazards to the user and system.

Hazard | Possible Consequences

Hazard | Possible Consequences
Faulty Microcontroller Mounting | Improper mounting can cause the microcontroller to move around in the housing, damaging the controller and the housing.

High
Microcontroller Temperature | High operating temperature can lead to damage to ports or connections.
Environmental Factors | The microcontroller can malfunction if introduced to enough dust, water, etc.
Power Failure | A power supply failure or surge can cause damage to various components on the microcontroller.
Physical and Static Force | Excessive force from an external factor such as a finger can damage components. Static force can induce a current that could cause damage to components.

### 6.3.2. Software Hazards

The software hazards contained within the microcontroller system boundary are listed below. Consideration was given to components of the CRA that could lead to possible software hazards to the user and system.

Hazard | Possible Consequences
Power Failure | A power supply failure or surge can cause the software processes to terminate at an unexpected state.
Microcontroller Damage | Damage to the microcontroller board via physical, static force can cause the firmware to malfunction.
6.4. Peripherals System Boundary

### 6.4.1. Physical Hazards

The physical hazards contained within the peripherals system boundary are listed below. Consideration was given to components of the CRA that could lead to possible physical hazards to the user and system.

Hazard | Possible Consequences
Cable Agitation | Constant agitation can cause the peripheral cables to come loose from the micontroller or LiDAR sensor. Agitation can also cause the peripherals to fall from their mounting points. This will lead to unconnected cables and connections while the CRA is in use.
Exposed Wiring | Exposed wires with a current can inflict an electric shock to the user.
Environmental Factors | The peripherals can become damaged if exposed to enough water, dust, etc, leading to the failure of the CRA's features.
Power Failure | A power supply failure or surge can damage the peripherals with a high voltage.

### 6.4.2. Software Hazards

The software hazards contained within the peripherals system boundary are listed below. Consideration was given to components of the CRA that could lead to possible software hazards to the user and system.

Hazard | Possible Consequences

Loose Peripherals

| Peripherals can become loose, contaminating the data being collected by the accelerometer, LiDAR, and camera.

Cable
Mismanagement
| The cables of the peripherals can become intertwined with the bike's wires which could lead to falls.
Peripheral Boundary Limits | Software can exceed the limit as set out by the manufacturers of the peripheral, leading to unexpected behaviour.
6.5. Camera System Boundary

### 6.5.1. Physical Hazards

The physical hazards contained within the camera system boundary are listed below. Consideration was given to components of the CRA that could lead to possible physical hazards to the user and system.

Hazard | Possible Consequences
Environmental Factors | Rain, dust, vehicle fumes, etc. can obscure the view on the lens of the camera, leading to improper footage capture which can not be used for further analysis.
Bicycle Collision | A bicycle collision leading to severe contact between the camera and the surface can cause the front lens of the camera to shatter.

### 6.5.2. Software Hazards

The software hazards contained within the camera system boundary are listed below. Consideration was given to components of the CRA that could lead to possible software hazards to the user and system.

Hazard | Possible Consequences
Video Compression | Excessive compression of the video can lead to unclear or grainy footage, leading to improper footage capture which can not be used for further analysis.
6.6. LiDAR System Boundary

### 6.6.1. Physical Hazards

The physical hazards contained within the LiDAR system boundary are listed below. Consideration was given to components of the CRA that could lead to possible physical hazards to the user and system.

Hazard | Possible Consequences

Hazard | Possible Consequences
Cable Mismanagement | The cable of the LiDAR can become intertwined with the bicycle's regular cabling which could lead to dangling or hanging wires.
Environmental Factors | Various environmental factors can cause the LiDAR to crash, leading to electrical issues.
LiDAR Mounting | The clamp that the LiDAR is located on has a strong clamping force that can become a hazard if tightened improperly on unintended surfaces such as body parts.

### 6.6.2. Software Hazards

The software hazards contained within the LiDAR system boundary are listed below. Consideration was given to components of the CRA that could lead to possible software hazards to the user and system.

Hazard | Possible Consequences
Software Misreads | Rain, dust, vehicle fumes, etc. can obscure the LiDAR's view, leading to inaccurate distance information provided to the software.
Environmental Factors | If the LiDAR sensor is exposed to enough factors including temperature, water, dust, the connections and pins make render useless, making the software behave unexpectedly.
6.7. Memory System Boundary

### 6.7.1. Physical Hazards

The physical hazards contained within the camera system boundary are listed below. Consideration was given to components of the CRA that could lead to possible physical hazards to the user and system.

Hazard | Possible Consequences

Improper Contact

| A flash drive with improper contact can cause unexpected interruptions during operation
Flash Drive Damage | Physical damage to the flash drive can lead it to not be properly plugged in to record footage.

### 6.7.2. Software Hazards

The software hazards contained within the memory system boundary are listed below. Consideration was given to components of the CRA that could lead to possible software hazards to the user and system.

Hazard | Possible Consequences
Long File Write Time | Video may take more time to upload, creating a bottleneck in the system.
Storage Overflow | Too many files located in the memory can cause the system to overheat if writes continue to occur.

Hazard | Possible Consequences
Power Supply Failure | A power supply failure or surge during file writing can corrupt the card.

## 7. Failure Modes and Effect Analysis

7.1. Hazards Out of Scope

Hazards Out of Scope will not be considered in the Failure Modes and Effect Analysis listed below in Section 7.2.

Group | Example
External Environment | Bicycle hazards (brakes, cabling, frame), road conditions (construction zones, potholes, traffic), other factors (precipitation, temperature, air quality)
Society | City and rural design, video recording laws, theft, damage (graffiti)
User Error | Improper use and installation, excessive carelessness during handling, low battery, low storage, and low maintenance upkeep
7.2. Failure Modes and Effect Analysis Table

The Failure Modes and Effect Analysis Table (FMEA) Table indicates the failure modes associated with certain design functions and the optimal response to minimize harm to the user or product. The FMEA able thus outlines the recommended course of action required for the CRA team to eliminate as many hazards or failures for its users.

Table 7.2.1: Failure Modes and Effect Analysis

Design Function | Ref
| Failure Mode Effects of Failures Causes of Failure Recommended Action
SR

Crash
Detection

H1-
1

False
negative
crash
detection.

The current loop
of video will not
be logged to the
storage device.
a. Sensor failure
(bias, drift,
complete
failure,
precision
degradation).
b. Crash was
not violent
enough to
trigger a crash
detection
sequence.
a. Perform a sensor
calibration and test
when the CRA is
turned on. Indicate an
issue if one is
detected.
b. Allow users to force
video loop logging
with a button.

a.
SR-1
b.
AR-1

Design
Function

Ref

Failure
Mode

Effects of
Failures

Causes of
Failure

Recommended
Action

SR

H1-
2

False
positive
crash
detection.

An unnecessary
loop of video will
be logged to the
storage device.
a. Sensor failure
(bias, drift,
complete
failure,
precision
degradation).
b. A non-crash
event had
trademark
features of a
crash (e.g. high
force, tipping).
a. Same as H1-1a
b. Alert the user
through the LED
display that a video
has started. Do not
stop the video
recording in the event
of an accident.

a.
SR-1
b.
AR-1

Video
Export to
Storage

H2-
1

Insufficient
memory in
storage
device

Video loop will
not be logged to
the storage
device.
a. Video loop is
too large to be
logged on the
storage device
or there is
insufficient
space on the
storage device.
a. Notify the user that
there is an insufficient
amount of storage
space on boot. In the
event of a storage
overflow, remove the
oldest capture folders
to accomodate for the
incoming footage.

a.
SR-3

H2-
2

Obscured
front-facing
camera
footage.

Camera footage
will be void or
non-optimal in
the event of a
camera loop
logging. Footage
cannot be used
for review and
analysis as
required.
a. Debris or
dust obstructs
the camera's
view.
b. Complete
camera or
camera feed
failure.
a. Create a housing
that will allow for the
complete camera to be
covered. Place the
camera in a location
where it is unlikely to
be impacted by any
debris.
b. Perform a camera
and camera feed check
when the CRA is
turned on. Indicate an
issue if one is
detected.

a.
IR-1
b.
SR-1

Design
Function

Ref

Failure
Mode

Effects of
Failures

Causes of
Failure

Recommended
Action

SR

H2-
3

Corruption
of video
files.

Video files are
lost or become
unreadable.
a. Physical
damage to the
flash drive.
b. Improper
contact
between the
flash drive and
the memory
slot.
c. Multiple files
being written
concurrently.
d. Power supply
failure.
a. Design a physical
barrier that prevents a
damaged flash drive
from being inserted
into the memory slot.
b. Alert the user in the
case that there is no
detected memory
device inputted. If
connected, alert the
user if the drive cannot
be written to.
c. Only allow one video
to be written to the
memory drive at a
time.
d. Use a reliable power
supply with a reliable
connection.

a.
IR-2,
AR-1
b.
IR-1
c.
SR-3
d.
IR-3

Rear
Vehicle
Detection

H3-
1

False
negative
rear vehicle
detection.

A vehicle exists in
the user's rear
view, but they are
not alerted.
a. The vehicle is
not detected by
the LiDAR
sensor.
b. The LiDAR
sensor is
obstructed by
debris.
c. The LiDAR
connection or
feed fails.
a. Perform a sensitivity
check on bootup to
ensure that the LiDAR
is connected properly
through a debug
mode.
b. Same as H2-2a
c. Same as H2-2b

a.
SR-4
b.
SR-1
c.
SR-1

H3-
2

False
positive rear
vehicle
detection.

A user is alerted
that a vehicle
exists in their rear
view when no
vehicle is present.
a. Debris
obstructs the
LiDAR's view.
a. Same as H2-2a

a.
SR-1

Design
Function

Ref

Failure
Mode

Effects of
Failures

Causes of
Failure

Recommended
Action

SR

Rear
Vehicle
Alerting

H4-
1

Incorrect
LED lights.

A vehicle exists in
the user's
rearview but the
rear vehicle
alerting system
does not identify
the distance
correctly. The
opposite also
occurs.
a. Debris
obstructs the
LiDAR's view.
b. The
connection pins
between the
LiDAR and
system have
failed.
c. The LED has
disconnected
from some of
the pins on the
microcontroller.
a. Same as H2-2a
b. Perform a sensitivity
check on the LEDs
when powering the
system on.
c. Perform a sensitivity
check on the LEDs
when powering the
system on.

a.
IR-1
b.
SR-1
c.
SR-1

H4-
2

Missing LED
lights

The LED system
does not light up
at all when
powered on.
a. The
connection
between the
LiDAR system
and the main
system has
failed.
b. The LED
system has
come off the
microcontroller.
a. Perform a sensitivity
check on the LEDs
when powering the
system on.
b. Perform a sensitivity
check on the LEDs
when powering the
system on.

a.
SR-1
b.
SR-1

Hardware
Housing

H5-
1

Housing
integrity is
violated.

Internal hardware
components are
damaged or
destroyed.
a. Housing is
submerged in
water (e.g. rain,
puddle, body
of water).
b. Housing is
violently
rattled.
c. Housing is
dropped to the
ground.
a. Create a water-proof
housing with minimal
holes
b. Secure the
microcontroller using
screws, nuts, and bolts
to the housing. Secure
the housing to the
frame through a
designed clamp.
c. Make the housing
robust and resistant to
fall damage. Secure
the housing to the
frame through a
designed clamp to
minimize impact.

a.
IR-1
b.
SR-2,
IR-1
c.
SR-2

Design
Function

Ref

Failure
Mode

Effects of
Failures

Causes of
Failure

Recommended
Action

SR

H5-
2

Poor
ergonomical
and
accessible
design.

User is
susceptible to
repetitive strain
injuries.
a. Housing
obstructs usage
of bicycle
handlebars.
b. Buttons on
the exterior of
the housing are
hard to use.
c. Housing
cannot be put
together or
taken apart
easily.
a. Provide detailed
instructions on how to
mount the device in a
non-obstructive way.
b. Design buttons to
be visible, intuitive,
tactile, and easily
accessible.
c. Design housing
using the same nut
and bolt size and with
intuitive mounting
holes of where pieces
should be placed.
Create a user manual
to aid installation.

a.
SR-2
b.
AR-2
c.
AR-2

Bicycle
Mount
For
Housing

H6-
1

Mount
failure.

Housing is
dropped to the
ground.
a. Mount is
impacted by
debris.
b. Rattling
loosens mount
grip.
a. Place the mount in a
position unlikely to be
impacted by debris.
b. Instruct user to
firmly tighten the
mount to their bicycle
like the metal frame
bar. Line the gripping
portion of the mount
with rubber to increase
friction and fit.

a.
SR-2,
IR-1
b.
SR-2,
IR-1

System
Firmware

H7-
1

Hardware
malfunction.

The
microcontroller is
unable to execute
the software as
intended.
a. Power supply
failure.
b. Poor
mounting of
the
microcontroller.
a. Same as H2-3d
b. Design a durable
mount for the
microcontroller, and
test the reliability
during crashes.

a.
IR-3
b.
IR-1

H7-
2

Software
malfunction.

The real-time
software running
on the
microcontroller
does not behave
as intended.

a.
Unanticipated
errors in
software.
b. Poor code
upkeep.
a. Run the software
process for a
prolonged period of
time.
b. Enforce readable,
maintainable code.

a.
PR-1
b.
PR-2

## 8. Safety and Security Requirements

8.1. Safety Requirements

SR-1

A system welfare check will be conducted each time the CRA is powered on to verify that all cameras and sensors are successfully communicating with the microcontroller.

Rationale

A problem with the LiDAR sensor could result in unexpected rear view detection behaviour (false positives or false negatives). A problem with the rear facing camera could result in footage of a crash being lost. A problem with crash detection sensors could result in unexpected crash detection behaviour (false positives or false negatives).

Associated
Hazards

H1-1a, H1-2a, H2-2b, H2-3b, H3-1b, H3-1c, H3-2a, H4-1b, H4-1c, H4-2a, H4-2b

SR-2

Safety instructions will be created to ensure that the CRA is properly equipped and mounted for the user.

Rationale | Instructions will allow the user to properly mount and maintain their system.
Associated Hazards | H5-1b, H5-1c, H5-2a, H6-1a, H6-1b
SR-3 | System self-assessments will optimize video storage to ensure there is enough space to hold videos and will alert the user if the space is insufficient.
Rationale | In the case that the storage memory device is full, videos will be cut short to ensure that the user has the footage of the latest accident that they have been involved in.
Associated Hazards | H2-1a, H2-3c
SR-4 | The camera, LiDAR, camera feed will be checked on startup by the system to ensure that all required software is connected and usable.
Rationale | This is to ensure that the camera is able to create and log video data as required on vehicle collision. This is also to ensure the LiDAR sensing is able to detect distances of objects accurately.
Associated Hazards | H3-1a
8.2. Access Requirements
AR-1 | CRA will allow the users to access their videos freely from an external hardware storage drive.
Rationale | This is to allow the user to connect it to their own personal systems to view, delete their videos. There is no need for encryption as this would complicate the process.
Associated Hazards | H2-3a
AR-2 | CRA will be ergonomically designed to accomodate all cyclists, including cyclists with special physical accessibility needs.

AR-2

CRA will be ergonomically designed to accomodate all cyclists, including cyclists with special physical accessibility needs.

Rationale

The design of the device should feel seamless without interfering with the user experience for cyclists with accessibility needs.

Associated
Hazards

H5-2b, H5-2c

8.3. Integrity Requirements

IR-1

The mounting system will be made with solid and sustainable material to ensure mechanical integrity.

Rationale

This will be able to withstand changes in weather and temperature, accidental drops, and debris.

Associated
Hazards

H2-2a, H4-1a, H5-1b, H6-1a, H6-1b, H7-1b

IR-2 | The housing will protect its interior from undesired foreign items.
Rationale | This will keep damaging substances like water, debris, and dust out while allowing access to necessary components like memory and charging ports
Associated Hazards | H2-3a
IR-3 | The components that are sourced from third-parties will be upheld to a quality level corresponding to their importance.
Rationale | As we cannot economically create every part of the device ourselves, we will need to source basic parts from third-party manufacturers. These parts need to be reliable enough to operate as intended.
Associated Hazards | H2-3d, H7-1a
8.4. Privacy Requirements
PR-1 | CRA will not be connected to the internet but will be used and trained locally for CV purposes.
Rationale | This is to ensure that the footage of accidents will not be posted on the internet without the consent of the user. Instead all footage will be saved to an external hardware storage device.
Associated Hazards | H7-2a
PR-2 | Code will be open-sourced, but only select individuals will be allowed to contribute to the master branch of the main repository.

PR-2

Code will be open-sourced, but only select individuals will be allowed to contribute to the master branch of the main repository.

Rationale

This will ensure that the code running on the device follows the coding standards and is peer-reviewed by members of the team.

Associated
Hazards

H7-2b

## 9. Roadmap

The roadmap of CRA is a projection of the safety and security requirements listed above. The majority of these requirements will be implemented on the initial prototype and final application due to the nature of the system and its functionalities. Requirements will be constantly reevaluated with several factors in consideration such as time and project constraints. Towards the end of the project, the Hazard Analysis document will be an evaluation over the project to get an understanding of what risks have been successfully mitigated and which ones will still require work.

With the conclusion of the CRA approaching, the Hazard Analysis was reconsidered to accomodate for any changes or additions. Changes included the introduction of camera and video logging for the rear vehicle detection camera, the LiDAR sensor along with the rear vehicle alerting LED system, as well as the removal of the use of computer vision. Throughout the design process and verification and validation phase, the Hazard Analysis was repeatedly considered which allowed the team to miitigate all risks outlined in this document. Further addendums or updates will be created in the case any discrepancies that arise.

## 10. Appendix

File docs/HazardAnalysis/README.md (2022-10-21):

<div align="center">

# Hazard Analysis




</div>

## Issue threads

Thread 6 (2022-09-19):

Create a Problem Statement for September 26 deliverable

MannyLemos, 2022-09-19:
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

amosyu2000, 2022-09-20:
It says in `docs/Checklists/ProbState-Checklist.pdf` that Prof. Smith wants us to use the `.tex` template. But in class he said we could use any text file type we want.
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

@aaronhsli Could you please ask Prof. Smith to clarify if doing our docs in Markdown is acceptable?

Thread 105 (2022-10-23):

Team 6 Hazard Analysis Review

Hargun22, 2022-10-23:
Great work on the hazard analysis. You guys went in-depth into potential hazards and safety risks associated with your system. My only concern is that some of the hazards that were listed in the system boundary section should've been put in the FMEA table to further analyze their effects and make requirements based on that. For example, I see there can be many hazards that arise due to the power supply failing or getting damaged. If that was analyzed in the FMEA table then you guys could've imposed requirements in order to mitigate those hazards.

@CSchank

Closed 2022-11-07.

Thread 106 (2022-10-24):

Team[6] Review

EngandDeveloper, 2022-10-24:
You have a very detailed hazard analysis and some good mitigation plans, good job.

The main thing I saw was that in your scope and purpose section (section 3), you did not clearly identify what is in scope and what is out of the scope. I would make them a bit more specific. If you are unsure about some components or think that everything should be in scope but not sure about the timing, you may consider assigning some prioritization to the components and give a scope in terms of time and priority. For example, the hardware errors may not be in your scope (or your initial scope), since you have little to no control over the sensors that collects data or the devices that the user will use the system (such as the Ipads). You may consider making the hardware failures an out of scope item. But other than that, great hazard analysis.

@CSchank

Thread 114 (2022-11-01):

Project Demo

amosyu2000, 2022-11-01:
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

amosyu2000, 2022-11-11:
From Nick:

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

amosyu2000, 2022-11-11:
## What we wanna present for the POC

- Breadboard prototype
  - Physical breadboard
  - Fritzing model

- Demonstration of accelerometer wired properly and outputting data into graph

- Car recognition
  - Footage of the prototype working with Brian's car
  - Demonstration of LED lighting up only when Manny's limited edition collectible busted porsche car is in view of the vrear camera
  - Demonstration of one LED turning on when the script is live
  - Demonstration of the button working (one press starts the feed, second press stops the feed)

- Modelling
  - Demonstrate 3D printed housing
  - Demonstrate Inventor files

- Front facing camera
  - Demonstration of the vfront camera saving footage

- Show that battery can power the Pi

- Why don't we use CI?
  - Lots of progress was in electronics, not software
  - Using Python so no need to compile
  - Did not integrate yet, getting separate parts working independently

Closed 2022-11-16.

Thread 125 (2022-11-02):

Create unit test template

amosyu2000, 2022-11-02:

amosyu2000, 2022-11-02:
Progress on unit tests so far (include after MIS and MG)

####
| CFRUT | |
|:--                            |:--|
| Control                       |
| Initial State                 |
| Input                         |
| Output                        |
| Test Case Derivation          |
| How will test be performed    |
| Requirements Referenced       |

#### Accelerometer Value Test
| CFRUT | |
|:--                            |:--|
| Control                       | Static |
| Initial State                 | αx = 0, αy = 0, αz = 0 |
| Input                         | Accelerometer input |
| Output                        | αx, αy, αz |
| Test Case Derivation          | The accelerometer should send updated values of the units acceleration across all 3 axis parallel, perpendicular, and vertical |
| How will test be performed    | The test will be done manually in a real world environment in which the accelerometer unit will be mounted onto the bike and updates values as the bike moves |
| Requirements Referenced       | CFR3, CFR5 |

#### Crash Detection Test
| CFRUT | |
|:--                            |:--|
| Control                       | Static |
| Initial State                 | αx != 0, αy != 0, αz != 0 |
| Input                         | Accelerometer input |
| Output                        | crashed |
| Test Case Derivation          | Cyclops should detect when a crash has occurred when the acceleration of the rider has passed a certain threshold. This then prompts CRA to perform tasks in response to a crash |
| How will test be performed    | The test will be done manually in a real world environment in which the accelerometer unit will be mounted onto the bike and updates values as the bike moves |
| Requirements Referenced       | CFR3, CFR4, CFR5, CFR7 |

#### Left-Side Crash Test
| CFRUT | |
|:--                            |:--|
| Control                       | Static |
| Initial State                 | αx, αy, αz nominal |
| Input                         | αx, αy, αz indicating the cyclist crashed and fell to the left |
| Output                        | crashed |
| Test Case Derivation          | This test will check that the crash detection function is able to differentiate a crash based on the acceleration data. |
| How will test be performed    | Pytest |
| Requirements Referenced       | CFR3, CFR4, CFR5, CFR7 |

#### Right-Side Crash Test
| CFRUT | |
|:--                            |:--|
| Control                       | Static |
| Initial State                 | αx, αy, αz nominal |
| Input                         | αx, αy, αz indicating the cyclist crashed and fell to the right |
| Output                        | crashed |
| Test Case Derivation          | This test will check that the crash detection function is able to differentiate a crash based on the acceleration data. |
| How will test be performed    | Pytest |
| Requirements Referenced       | CFR3, CFR4, CFR5, CFR7 |

#### Front-Side Crash Test
| CFRUT | |
|:--                            |:--|
| Control                       | Static |
| Initial State                 | αx, αy, αz nominal |
| Input                         | αx, αy, αz indicating the cyclist was involved in a forward facing crash |
| Output                        | crashed |
| Test Case Derivation          | This test will check that the crash detection function is able to differentiate a crash based on the acceleration data. |
| How will test be performed    | Pytest |
| Requirements Referenced       | CFR3, CFR4, CFR5, CFR7 |

#### Rear-Side Crash Test
| CFRUT | |
|:--                            |:--|
| Control                       | Static |
| Initial State                 | αx, αy, αz nominal |
| Input                         | αx, αy, αz indicating the cyclist was involved in a rear facing crash |
| Output                        | crashed |
| Test Case Derivation          | This test will check that the crash detection function is able to differentiate a crash based on the acceleration data. |
| How will test be performed    | Pytest |
| Requirements Referenced       | CFR3, CFR4, CFR5, CFR7 |

#### Power On Unit Test
| CFRUT | |
|:--                            |:--|
| Control                       | Manual |
| Initial State                 | System is off |
| Input                         | Power button |
| Output                        | LED |
| Test Case Derivation          | LED’s should light up and be reflective when the system/application has power and is running |
| How will test be performed    | This test will be done manually in a real world environment where the power button is to be pressed to turn on CRA |
| Requirements Referenced       | CFR11 |

#### Power Off Unit Test
| CFRUT | |
|:--                            |:--|
| Control                       | Manual |
| Initial State                 | System is on |
| Input                         | Power button |
| Output                        | LED |
| Test Case Derivation          | LED’s should turn off and be reflective when the system/application has power and is running |
| How will test be performed    | This test will be done manually in a real world environment where the power button is to be pressed to turn off CRA. |
| Requirements Referenced       | CFR11 |

#### Video On Test
| CFRUT | |
|:--                            |:--|
| Control                       | Manual |
| Initial State                 | Camera is powered and connected to microcontroller |
| Input                         | Camera |
| Output                        | Video |
| Test Case Derivation          | Video can be seen on an external monitor when camera is turned on. |
| How will test be performed    | An external monitor will be connected to the system and the test will be performed manually. |
| Requirements Referenced       | CFR2 |

#### Video Save Test
| CFRUT | |
|:--                            |:--|
| Control                       | Static |
| Initial State                 | Camera is powered and connected to microcontroller |
| Input                         | Video stream |
| Output                        | Video file |
| Test Case Derivation          | The test will verify that a video with length BUFFER_TIME_MINUTES can be saved. |
| How will test be performed    | Pytest |
| Requirements Referenced       | CFR8 |

Closed 2023-03-09.

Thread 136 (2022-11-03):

Team 5 VnV Peer Review--Tests have large scope

NevoAbigail, 2022-11-03:
Great work on the VnV! I understand this may/may not infringe on unit test territory, but it seems to me as though some of your functional requirement tests, specifically 5.1.1 and 5.1.2 test many different aspects at once and are fairly general--I wonder whether you could break down these tests into more specific scenarios, especially scenarios that test boundary cases. For example, is it feasibly possible for the cyclist to pass the crash acceleration threshold, but not have crashed? What would happen in that scenario? Or what if a car is moving very fast as it passes the cyclist's blindspot?

amoscheung99527, 2022-11-08:
For the functional requirement tests, they are general as we plan to have unit test cover each subsection of them. And for the boundary cases you mentioned, the crash detection is using acceleration of the x, y and z axis, which is accounting for the car flipping/tilting rather than just acceleration moving forward. And for the blind spot, we are capturing every frame, so the chance of a car moving too fast is not really possible.

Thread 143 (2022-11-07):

Team 5 VnV Peer Review - SD Card

stephendejong, 2022-11-07:
For test 5.1.4. Full SD Test - I like the thoughtfulness of letting user know when the SD card is almost full. Is it also important to test what happens if the card is not inserted in the device or is corrupted? It might be nice to know when the card is missing as the device has reduced function at that point.
love the project!

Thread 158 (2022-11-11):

Fix various md files

aaronhsli, 2022-11-11:
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

Code of Conduct does not have a contact name.

amosyu2000, 2022-11-11:
Also need to remove line 1 from the license file
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

amosyu2000, 2022-11-11:
Also need to update the refs/README.md file
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

amosyu2000, 2022-11-11:
README titles should be centered.
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

Closed 2022-11-11.

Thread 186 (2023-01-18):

MIS: Add software specifications, electrical, mechanical info

aaronhsli, 2023-01-18:

aaronhsli, 2023-01-18:
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

aaronhsli, 2023-01-18:
[RaspberryPi4ElectricalSchematic.pdf](https://github.com/amosyu2000/cyclops/files/10448801/RaspberryPi4ElectricalSchematic.pdf)

aaronhsli, 2023-01-18:
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

aaronhsli, 2023-01-18:
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

aaronhsli, 2023-01-18:
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

aaronhsli, 2023-01-18:
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

amosyu2000, 2023-01-18:
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

amosyu2000, 2023-01-18:
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

amosyu2000, 2023-01-19:
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

aaronhsli, 2023-01-19:
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

aaronhsli, 2023-01-19:
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

aaronhsli, 2023-01-19:
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

aaronhsli, 2023-01-19:
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

Closed 2023-01-19.

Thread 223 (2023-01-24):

Verify that the breadboard is complete, and transfer to PCB

amosyu2000, 2023-01-24:

amosyu2000, 2023-01-24:
PCB should include:
location | device
:--|:--
mounted | all female pins to raspberry pi
mounted | 5 leds
mounted | accelerometer
wired | ultrasonic sensor
wired | power button

amosyu2000, 2023-02-01:
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

Closed 2023-02-01.

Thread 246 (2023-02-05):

[Code] Add error checking for if the ultrasonic sensor is not plugged in

amosyu2000, 2023-02-05:

Closed 2023-03-02.

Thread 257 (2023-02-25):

Code Overhaul

MannyLemos, 2023-02-25:
Rewrite video capturing code:
- split frame retrieval from camera and frame encoding into separate threads to improve fps.
- switch to lightweight codec best optimized for raspberry pi hardware.
- improved error handling & reporting

Introduce lidar_thread
- begin preliminary testing with lidar sensor's features.
- Verify the functionality of the sensor & hardware setup.

Improve Debugging Experience
- add color coding to print_handler
- Unify formatting of calls to print_handler to use color coding to its full extent

circuit_schematiics
- new standalone folders to host versions of circuit schematics
- new circuit schematic V2 created with the aim of eliminating the need for a PCB

Bug Fix
- dir_handler os argument change

Closed 2023-03-01.

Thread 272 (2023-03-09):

Recreate Housing for Final Demo

aaronhsli, 2023-03-09:

amosyu2000, 2023-03-29:
Redesign Front Housing #290
LiDAR Housing Update #296

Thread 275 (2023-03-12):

Team3 Review: Missing Traceability Tables in VnV Report

arkinmodi, 2023-03-12:
Traceability from test cases to requirement/module are missing in the report.

TAs: @NickCapstone @tomashetMcMaster

Closed 2023-03-21.

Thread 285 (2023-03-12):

Team 34 VnVReport Review: Traceability Tables

WinnieTrandinh, 2023-03-12:
@NickCapstone

Great work with associating requirements with the test cases results.
To increase traceability, perhaps include a traceability table as well, between the Test Cases and the Requirements, and also between the Test Cases and the Modules.

This would make it clearer as to which requirements are tested by which cases, or if there are any missing requirements not tested.

Closed 2023-03-21.

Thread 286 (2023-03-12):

Team 34 VnVReport Review: Changes Made Due to Testing

WinnieTrandinh, 2023-03-12:
@NickCapstone

The section outlining the changes made due to testing are well done with regards to the changes discovered from the Rev0 Demo.
However, changes resulting from the VnV itself are not outlined, which is what the rubric outlines.
It may be beneficial if points are added on the changes that arose while conducting the verification, such as the discovery of a bug or design error that prevents a test case from passing.

Closed 2023-03-21.

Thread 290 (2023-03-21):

Redesign Front Housing

amosyu2000, 2023-03-21:

Closed 2023-03-21.

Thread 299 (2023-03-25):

Code Overhaul V3

MannyLemos, 2023-03-25:
Rewrite Accelerometer Thread
- Implement new FIFO queue based temporary data retention
- Update Crash detection

Implement all LED Stick Features
- Powwer on animation
- Capture animation with error reporting
- Power off animation

Closed 2023-03-26.

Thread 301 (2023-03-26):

Ignore this

MannyLemos, 2023-03-26:
LIDAR HOUSING
-------------------------------------------------------------------------------------------------------------------------------------
DIMS
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
DRAW
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

DIMS
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
DRAW
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

DRAW
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

-------------------------------------------------------------------------------------------------------------------------------------

Raspberry Pi Housing
-------------------------------------------------------------------------------------------------------------------------------------

ISO
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

DIMS
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
DRAW
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

DIMS
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
DRAW
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

DIMS
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
DRAW
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

DIMS
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
DRAW
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

DRAW
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
-------------------------------------------------------------------------------------------------------------------------------------

Closed 2023-03-26.

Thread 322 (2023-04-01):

Spelling/Grammar Check

amosyu2000, 2023-04-01:
| Before | After |
|:--|:--|
| front facing | front-facing |
| Front-Facing | Front-facing |
| blindspot detection | rear vehicle detection |
| blind spot detection | rear vehicle detection |
| blind-spot detection | rear vehicle detection |
| lidar | LiDAR |
| flashlight | (remove) |
| headlamp | (remove) |
| Cyclops Ride Assist: Real-time bicycle crash detection and blindspot monitoring. | Cyclops Ride Assist: Real-Time Monitoring System |

Closed 2023-04-05.

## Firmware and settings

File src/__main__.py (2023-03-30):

from threading import Event, Thread
import os
import RPi.GPIO as GPIO
import queue
from print_handler import print_handler
from led_handler import Led_Handler
import accelerometer_thread, camera_thread, lidar_thread, capture_thread

""" Events """
poweroff_event = Event()
log_event = Event()
a_capture_event = Event()
c_capture_event = Event()
l_capture_event = Event()

""" Poweron sequence """
POWER_OFF_BUTTON = 16
GPIO.setmode(GPIO.BCM)
GPIO.setup(POWER_OFF_BUTTON, GPIO.IN, pull_up_down=GPIO.PUD_UP)
led_handler = Led_Handler(log_event)
led_handler.startup_sequence()
print_handler("Main", "Program started")

""" Shared Directory Variable """
directory = queue.Queue(3)

""" Threads """
threads = [
	Thread(target=accelerometer_thread.Start, args=[directory, poweroff_event, log_event, a_capture_event]),
	Thread(target=camera_thread.Start, args=[directory, poweroff_event, c_capture_event]),
	Thread(target=lidar_thread.Start, args=[directory, poweroff_event, l_capture_event, led_handler]),
	Thread(target=capture_thread.Start, args=[directory, led_handler, poweroff_event, log_event, a_capture_event, c_capture_event, l_capture_event]),
]
[ thread.start() for thread in threads ]

""" Poweroff sequence """
GPIO.wait_for_edge(POWER_OFF_BUTTON, edge=GPIO.FALLING)
poweroff_event.set()
[ thread.join() for thread in threads ]

led_handler.poweroff_sequence()
GPIO.cleanup(POWER_OFF_BUTTON)
print_handler("Main", "Program stopped")
os.system("sudo poweroff")

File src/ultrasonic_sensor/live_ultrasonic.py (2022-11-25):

import RPi.GPIO as GPIO
import time
from led import LED
from ultrasonic import Ultrasonic

class Live_Ultrasonic():
	def __init__(self):
		led = LED(17, 22, 23, 25, 27)
		ultrasonic = Ultrasonic(pin_trigger=18, pin_echo=24, distance_min=0, distance_max=50, unit="cm")

		try:
			while True:
				led.percentage_high(ultrasonic.distance_percentage())
				time.sleep(0.5)
		# Reset by pressing CTRL + C
		except KeyboardInterrupt:
			print("Measurement stopped by User")
			GPIO.cleanup()


if __name__ == '__main__':
	Live_Ultrasonic()

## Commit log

2022-10-05 [#54] adding Project Drivers to SRS (#56)
2022-11-04 [#138] Initialize accelerometer code
2022-11-09 Adding .stl, .gcode, .ipt files
    This will be for the first iteration of our mechanical design.
    [Bot for RaspPi4.ipt, Bot for RaspPi4.stl, Top for RaspPi4.ipt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]
2022-11-10 [#151] Adding Camera Buffer Code
2022-11-11 [#160] Created fritzing schematics
    [CRA.fzz]
2022-11-13 [#164] delete camera_recording
2022-11-24 Added ultrasonic sensor code
2022-11-25 [#176] Refactored ultrasonic code into classes
2022-11-25 [#177] created main script file, integrated ultrasonic and accelerometer
2023-01-18 [#186] Update framework for Sections 7, 8, 9, 10
2023-01-19 [#184] Updated fritzing schematics and added them to MIS
    [CRA.fzz]
2023-01-19 #195 LED Change
2023-01-19 [#204] MIS: Added traceability with SRS
2023-01-25 [#230] Added buttons and script execution on boot
2023-01-30 [#226] Implemented better threading and a way to log acceleration/ultrasonic readings to csv
2023-02-01 [#223] Finalized electrical schematics
    [CRA.fzz]
2023-02-06 [#226] Updated where/how csv files are saved
    - Saved csv files are now grouped by time rather than by file type
    - Folder management is dealt with my Dir_Handler
    - Added functionality to the capture button
    - Improved closing sequences for all threads
2023-02-07 [#222] fixed video concatenation
    [__main__.py, acceleration.py, led.py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]
2023-02-09 [#253] Update CAD (.ipt, .stl)
    [BACK.ipt, BACK.stl, BOT.ipt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]
2023-02-09 [#253] Removing old CAD files.
    [Top for RaspPi4.ipt]
2023-02-09 [#253] Updating CAD files.
2023-02-16 #253 Ultrasonic sensor mounting
    [Ultrasonic_Mount.ipt, Ultrasonic_Mount.stl]
2023-02-16 #253 Updated naming convention for sensor files
    [ULTRASONIC MOUNT.ipt, ULTRASONIC MOUNT.stl]
2023-03-02 [#257] Code Overhaul
    [CRA.fzz]
2023-03-21 [#290] Redesigned front housing
    [ACCELEROMETER.ipt, BACK.ipt, BACK.stl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]
2023-03-23 [#280, #277, #276] updated VNV report
    [CRA Usability Survey (Responses).csv]
2023-03-27 [#295] Revise Design Document
    [CRA.fzz]
2023-03-29 [#296} Update Rear Housing
2023-03-29 {#296} Update Rear Housing
    [Bike_Mount_Right_LiDAR.ipt, Bike_Mount_Right_LiDAR.stl, LiDAR.iam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]
2023-03-29 [#247] Code Updates
    - Export captures to USB stick if one is detected
    - addressed some errors
    [__main__.py, acceleration.py, lidar.py]
2023-03-30 [#309] Reworked dir_handler to only be called once per capture
    [__main__.py, acceleration.py, lidar.py]
2023-03-31 Restore logo and update lidar file
2023-03-31 #312 led_test
2023-04-01 [#268] Rewrite Crash Detection Algorithm
    [acceleration.py]
2023-04-01 [#316] Adjusted dimensions for CAD front housing
    [BIKE_MOUNT_BOTTOM.ipt, BIKE_MOUNT_TOP.ipt, BOTTOM.ipt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]
2023-04-02 [#321] LiDAR now returns 999 when out of range
2023-04-02 [#319] Updated SRS to current product requirements
2023-04-02 [#324] Upload presentation materials
2023-04-05 [#253] Upload .ipts for all components
    [ACCELEROMETER.stl, BIKE_MOUNT_BOTTOM.stl, BIKE_MOUNT_TOP.stl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]
